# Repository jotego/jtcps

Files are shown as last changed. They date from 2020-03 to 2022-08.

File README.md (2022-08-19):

# JTCPS - FPGA Arcade Hardware

You can show your appreciation through
* Patreon: https://patreon.com/jotego
* Paypal: https://paypal.me/topapate

Capcom System 1/1.5/2 compatible verilog core for FPGA by Jose Tejada (jotego).

# Original Documentation

[The internet archive](www.archive.org) holds some schematics related to this work.

* [Forgotten Worlds manual](https://archive.org/details/arcademanual_forgotten-worlds/page/n15/mode/2up)

# Memory Requirements

All CPS1 and CPS1.5 operate correctly on a 32MB SDRAM system. Some CPS2 games may require a 64MB module. Those games are listed as having a GFX ROM of 16MB or more below. Please check the CPS2 ROM size section.

# Control

MiSTer allows for gamepad redifinition. However, the keyboard can be used with more or less the same layout as MAME for MiST(er) platforms. Some important keys:

-F12 OSD menu
-P   Pause. Press 1P during pause to toggle the credits on and off
-5,6 1P coin, 2P coin
-1,2 1P, 2P

For MiST, the first 6 gamepad buttons are used for game buttons, the next 2 buttons are used for credit and start buttons. If there is still one button left in the gamepad, it will be used for pause.

There is an option to slow down the game (available only for CPS2). If you enable the 1P_hold_for_slow setting on the OSD, then while the 1P button is held the game will run at half the speed. Release the 1P button to go back to normal speed or disable the option in the OSD. Note that if the option is enabled the 2P, 3P and 4P buttons will also activate the slow down effect.

# Setup

## MiSTer

Copy the RBF file to `_Arcade/cores` and the MRA files to `_Arcade`. Copy zipped MAME romsets to `_Arcade/mame`. Enjoy.

It is also possible to keep the MAME romsets in `_Arcade/mame` but have the MRA files in `_CPS` and the RBF files in `_CPS/cores`

The _rotate screen_ OSD option is ignored for horizontal games.

## MiST

You need to generate the .rom file using this (tool)[https://github.com/sebdel/mra-tools-c/tree/master/release]. Basically call it like this:

`mra ghouls.mra -z rompath -A`

And that will produce the .rom file and a .arc file. The .arc file can be used to start the core and directly load the game rom file. Note that the RBF name must be JTCPS1.RBF for it to work. The three files must be in the root folder.

*Important*: make sure to have the latest firmware and latest version of the mra tool.

Copy the RBF, .arc and .rom files to MiST and enjoy!

Note that there is no screen rotation in MiST. Vertical games require you to turn your screen around. You can however flip the image through the OSD.

Pang! 3 and all CPS 1.5/2 games did not use DIP switches to configure the game, but a small non-volatile RAM. You have to enter the test menu to configure it (via OSD). After you have configured the settings, save the contents using the OSD option *Save NVRAM*. A file will be created at the root of your SD card called game.RAM, where game will match the name of the .ROM file used with the game.

# Issues

Please report issues (here)[https://github.com/jotego/jtbin/issues].

## QSound Hiss

The DSP16A clock enable must be an exact multiple of 30MHz. Otherwise the sampling period will not be constant, generating jitter. The effect of jitter is very obvious in the DAC used on MiST because when all sound goes silent an ugly transient occurs. That effect was not noticeable in MiSTer, which uses a different DAC.

Even with the right clock enable, there is still hiss occasionally in MiST(er). Using the FPGA logic analyzer I could check that the period was indeed constant but hiss was present.

# CPS-1 Audio

The OKI PCM input clock is 1MHz, depending on the SS input setting, this gives two sampling frequencies:

SS | Fs (Hz) | 4xFs  |    a    |  1-a
---|---------|-------|---------|--------
0  | 6097.5  | 24390 | 0.8200  | 0.1800
1  | 7575.7  | 30303 | 0.8524  | 0.1476

The original board has a first-order low pass filter at 770 Hz, this can be implemented with a first order IIR filter:

y[k] = a * y[k-1] + (1-a) * x[k]

where a = exp(-wc/T )
wc = 2*pi*770 = 4838 rad/s
T  = 1/4Fs

# QSound

QSound requires its own firmware rom to work. In MAME this is called qsound.zip. QSound sampling frequency is 3746 ticks of the input clock, when the clock enable applied is 2/3. For a 90MHz input clock, this will result in the correct internal 30MHz and in a sampling frequency of 90MHz/3747=24,019.2Hz

The original board had a digitally controlled amplifier. The volume set on this amplifier could be read back by the CPU and DSP. In order to control the value read by these devices, press and hold the coin button for 1P while pressing up or down (for more or less volume). Note that this does not have an actual effect on the sound output.

# PAL Dumps
PAL dumps cam be obtained from MAME rom sets directly. Use the tool jedutil in order to extract the equations from them. The device is usually a gal16v8. For instance:

```
jedutil -view wl24b.1a gal16v8
```

In order to see the equations for Willow's PAL.

# Compilation
The core is compiled using jtcore from **JTFRAME**. Follow the instructions in the README file of (JTFRAME)[https://github.com/jotego/jtframe] and then:

```
source setprj.sh
jtcore cps1 -mister
```

This will produce the mister file.

## Static Time Analysis (STA)

MiST and SiDi compilations produce STA clean files with the default seed. However the MiSTer RBF file with everything enabled doesn't always come STA clean. If you disable HDMI or sound during compilation the RBF file will normally be STA clean. Public binary distribution in [jtbin](https://github.com/jotego/jtbin) are either STA clean or violations are below 99ps.

# MRA Format

Offset    | Length | Use
----------|--------|-------------
 0  /  0o |  2     | Sound CPU ROM*
 2  /  2o |  2     | PCM data*
 4  /  4o |  2     | GFX ROM*
 6  /  6o |  2     | QSound firmware*
10h / 20o | 18     | CPS-B configuration
22h / 42o |  1     | Game ID
23h / 43o |  2     | Bank offset
25h / 45o |  2     | Bank mask
27h / 47o |  1     | CPS-A board type (Pang! 3, etc.)
30h / 60o | 11     | Kabuki keys (CPS 1.5 only)
28h / 50o |  1     | CPS2 board type
2ch / 54o | 20     | CPS2 keys

* All offset values are expressed in kilobytes and stored with MSB byte second

The offset for each graphic bank is comprised of two bytes. Each offset data is packed in 4 bits, with the MSB used for bank 3:

{ Offset_bank3, ..bank2, bank1, bank0 } = { byte 24h, byte 23h }

The 4-bit offset makes the MSB of the 20-bit GFX ROM address.

CPS-A board type format:

Bits   |  Use
-------|----------------------------
0      | CPU speed. 0=10MHz, 1=12MHz
3:1    | Enables additional inputs on CPS-B chip side
4      | High for charger games
5      | 0 = Disables Kabuki decryption

CPS2 board type format:

Bits   |  Use
-------|-------
1:0    | Controller type

# SDRAM Usage

## CPS 1/CPS 1.5

SDRAM bank | Usage
-----------|-------
0          | RAM/VRAM/M68000 ROM
1          | Sound CPU/PCM samples
2          | GFX
3          | GFX

## CPS 1.5 ROM Size

The SDRAM layout is the same as for CPS 1. Although samples are much larger than in CPS 1 titles, they still fit in one SDRAM bank sharing space with the Z80 ROM.

Game                  | CPU     |   Z80       | GFX     | Q-Sound |
----------------------|---------|-------------|---------|---------|
Warriors of Fate      | 1   MB  |  128 kB     | 4 MB    | 2 MB    |
Cadillacs & Dinosaurs | 1.5 MB  |  128 kB     | 4 MB    | 2 MB    |
The Punisher          | 1.5 MB  |  128 kB     | 4 MB    | 2 MB    |
S.N. Slam Masters     | 2.0 MB  |  128 kB     | 6 MB    | 4 MB    |
Muscle Bomber Duo     | 2.0 MB  |  128 kB     | 6 MB    | 4 MB    |

## CPS 2 ROM Size

It looks like the 16kB memory add-on is not used for regular games. Maybe it is used for
network connectivity only.

Game                  | CPU     |   Z80       | GFX     | Q-Sound |Obj base| Addon | Popularity
----------------------|---------|-------------|---------|---------|--------|-------|------------
19XX                  | 2.5 MB  |  128 kB     | 10 MB   | 4 MB    | 7080   |  No   | 191
1944                  | 1.5 MB  |  128 kB     | 20 MB   | 8 MB    | 7080   |  No   | 161
Alien vs Predator     | 2.0 MB  |  128 kB     | 16 MB   | 4 MB    | 7000   |  No   | 637
Armored Warriors      | 4.0 MB  |  256 kB     | 20 MB   | 4 MB    | 7000   |  No   | 278
Battle Circuit        | 3.5 MB  |  256 kB     | 16 MB   | 4 MB    | 7080   |  No   |  87
Capcom Sports Club    | 2.5 MB  |  128 kB     |  8 MB   | 4 MB    | 7080   |  No   |  20
Cyberbots             | 4.0 MB  |  256 kB     | 32 MB   | 4 MB    | 7080   |  No   | 141
Darkstalkers          | 4.0 MB  |  256 kB     | 20 MB   | 4 MB    | 7080   |       | 146
Dimahoo               | 2.0 MB  |  256 kB     | 16 MB   | 8 MB    | 7080   |  No   |  32
DnD Shadow o. Mystara | 4.0 MB  |  256 kB     | 24 MB   | 4 MB    | 7080   |  No   | 336
DnD Tower of Doom     | 2.5 MB  |  128 kB     | 12 MB   | 4 MB    | 7080   |  No   | 108
Eco Fighters          | 2.0 MB  |  128 kB     | 12 MB   | 4 MB    | 7000   |       |  64
Giga Wing             | 1.5 MB  |  128 kB     | 16 MB   | 8 MB    | 7080   |       |  66
Hyper SF II           | 4.0 MB  |  256 kB     | 32 MB   | 8 MB    | 7080   |       | 171
Janpai                | 1.0 MB  |  128 kB     | 16 MB   | 4 MB    | 7000   |       |  15
Jyangokushi           | 0.5 MB  |  128 kB     | 16 MB   | 4 MB    |        |       |   1
Mars Matrix           | 1.5 MB  |  128 kB     | 32 MB   | 8 MB    |        |  No   |  57
Marvel Super Heroes   | 4.0 MB  |  256 kB     | 32 MB   | 4 MB    |        |       | 165
Marvel vs SF          | 4.0 MB  |  256 kB     | 32 MB   | 8 MB    |        |       | 336
Marvel vs CAPCOM      | 4.0 MB  |  256 kB     | 32 MB   | 8 MB    |        |       | 377
Megaman 2             | 1.5 MB  |  256 kB     |  8 MB   | 4 MB    |        |       | 225
Darkstalker's revenge | 4.0 MB  |  256 kB     | 32 MB   | 4 MB    |        |       |  54
Progear               | 1.0 MB  |  128 kB     | 16 MB   | 8 MB    | 7080   |  No   |  72
Puzz Loop 2           | 2.0 MB  |  128 kB     | 16 MB   | 4 MB    | 7000   |       |  16
Quiz Nanairo Dreams   | 2.0 MB  |  128 kB     |  8 MB   | 4 MB    |        |       |   8
Ring of Destruction   | 3.0 MB  |  256 kB     | 18 MB   | 4 MB    |        |       | 293
Slam Masters 2        | 3.0 MB  |  256 kB     | 18 MB   | 4 MB    |        |       | 291
SF alpha 1            | 2.0 MB  |  256 kB     |  8 MB   | 4 MB    | 7000   |       | 190
SF alpha 2            | 3.0 MB  |  256 kB     | 20 MB   | 4 MB    | 7000   |       | 218
SF alpha 3            | 4.0 MB  |  256 kB     | 32 MB   | 8 MB    | 7000   |       | 456
SF zero 2 alpha       | 3.0 MB  |  256 kB     | 20 MB   | 4 MB    | 7000   |       | 293
Super Gem Fighter     | 2.5 MB  |  256 kB     | 20 MB   | 8 MB    |        |       | 252
Super Puzzle Fighter 2| 1.0 MB  |  256 kB     |  4 MB   | 4 MB    | 7000   |       | 210
SF2 New Challengers   | 2.5 MB  |  128 kB     | 12 MB   | 4 MB    | 7080   |  No   | 135
SF2 Turbo             | 3.5 MB  |  256 kB     | 16 MB   | 4 MB    | 7080   |       |1200
Vampire Savior 1      | 4.0 MB  |  256 kB     | 32 MB   | 8 MB    |        |       |  30
Vampire Savior 2      | 4.0 MB  |  256 kB     | 32 MB   | 8 MB    |        |       |  26
X-Men Children of A.  | 4.0 MB  |  256 kB     | 32 MB   | 4 MB    | 7080   |  No   | 179
X-Men vs SF           | 3.5 MB  |  256 kB     | 32 MB   | 4 MB    | 7080   |  No   | 337

# Simulation

## Game
1. Generate a rom file using the MRA tool
2. Update the symbolic link rom.bin in ver/game to point to it
3. If all goes well, `go.sh` should update the sdram.hex file
   But if sdram.hex is a symbolic link to something else it might
   fail. You can delete sdram.hex first so it gets recreated

   `go.sh` will fill up sdram.hex with zeros in order to avoid x's in
   simulation.

4. Apply patches if appropiate. The script `apply_patches.sh` can generate
   some alternative hex files which skip some of the test code of the game
   so it boots up more quickly

5. While simulation is running, it is possible to update the output video
   files by running `raw2jpg.sh`

Some Verilog macros:

1. FORCE_GRAY ignore palette and use a 4-bit gray scale for everything
2. REPORT_DELAY will print the average CPU delay at the end of each frame
   in system ticks (number of 48MHz clocks)
3. JTCPS_TURBO forces turbo mode, speeding up -slightly- the game speed, especially on boot-up

## Video

Video only simulations can be done using mame dumps. Use the tool *cfg2mame* in the *ver/video* folder
to create two *.mame* files that can invoked from mame to dump the simulation data. Run the game in debug
mode but source from MAME the register file that *cfg2mame* creates. Then at the point of interest souce *vram.mame*. That creates the file vram.bin. Copy that file to a directory with the mame name of the game. Add a numerical index (see the other folders for examples). Create a hex file following the examples in
the other files too. Now you run go.sh like this:

```
go.sh -g game -s number -frame 2
```

This will run the simulation for the folder *game* and looking for files with the *number* index. If you
 need to look at the sprites too, you need to run more than one frame as the object DMA needs a frame to
 fill in the data.

# Support

You can show your appreciation through
* Patreon: https://patreon.com/jotego
* Paypal: https://paypal.me/topapate

# Licensing

Contact the author for special licensing needs. Otherwise follow the GPLv3 license attached.

# Patron Acknowledgement

The following patrons supported the development of CPS1.5
```
3style              Chris Harvey        Joeri van Dooren    Oliver Wndmth
80's spaceman       cohge               Johan Smolinski     Oriez
Adam Davis          Coldheat007         John Casey          Oscar Laguna Garcia
Alan Shurvinton     Dakken              Jonathan Loor       Oskar Sigvardsson
Alfredo Henriquez   Dan                 Jonathan Tuttle     Patrick Roman Fabri
Alonso J. Núñez     Daniel Bauza        Jorge Slowfret      Paweł Mandes
Anders Rensberg     Daniel Estreito     Josiah Wilson       Per Sweden
Andrea Chiavazza    dannahan            JPS (RetroFPGA)     Phillip McMahon
Andreas Micklei     Darren Wootton      Juan E. Gayon       PsyFX
Andrew Ajello       Dasutin             Justin D'Arcangelo  Purple Tinker
Andrew Boudreau     David Ashby         Kitsuake            Rachael Netz
Andrew Francomb     David Fleetwood     KnC                 RandomRetro
Andrew Moore        David Jones         Kyle Good           RetroDriven
Andy Palmer         David Mills         Lee Osborne         Richard Eng
Andyways            derFunkenstein      Leslie Law          Richard Murillo
angel_killah        DJ Lethal           Lionel LENOBLE      Richard Simpson
Angelo Kanaris      Don Gafford         Louis Martinez      Robert Bergman
Anthony Monaco      DrMnike             Luc JOLY            Robert Forbes
Anton Gale          Ed Balan            Magnus Kvevlander   Robert MacLean
Antonio Villena     Edward Rana         Manuel Astudillo    Robert Mullings
Aquijacks           Eric J Faulkes      Marcus Hogue        Roman Buser
Arcade Express      Filip Kindt         Martin Di Palma     rsn8887
Arjan de Lang       Francis B           Matt Evans          Ryan Fig
asdfgasfhsn         Frank Hoedemakers   Matt ODonnell       Sassbasket Silvercloud
atrac17             Frédéric Mahé       Matthew Humphrey    Sebastien Goutal
Bear S              Gary Greenan        Matthew Woodford    Skeeter
Ben Toman           Gavin               Matthew Young       Sofia Rose
Bender              Greg                Max Schütz          Spank Minister
Bliz 452            Gregory Val         Michael Deshaies    Spencer Bradley
Bob Gallardo        Gus Douboulidis     Michael Yount       Stephen Goldberg
Brent Fraser        Handheld Obsession  Mick Stone          Steven Wilson
Brett T Davis       Hard Rich           Mike Jegenjan       Steven Yedwab
brian burney        Henrik Nordström    Mike Parks          Thomas Irwin
Brian Sallee        HFSPlay             MiSTerFPGA.co.uk    Toby Boreham
Carrboroman         hyp36rmax           mottzilla .         Travis Brown
Charles             Jacob Hoffman       Nailbomb            Trifle
Chi Wai Tran        Jeff Roberts        natalie             Ulf Skutnabba
Chris Jardine       Jeremy Hasse        Neil St Clair       Ultrarobotninja
Chris smith         Jeremy Kelaher      Nico Stamp          Victor Bly
Chris W Miller      Jesse Clark         nonamebear          Victor Fontanez
Christian           Jim Knowler         nullobject          Víctor Gomariz Ladrón de Guevara
Christian Bailey    Jo Tomiyori         Oliver Jaksch       Xzarian
Christopher Gelatt                                          yoaarond
```
The following patrons supported the development of CPS2
```
                     80's spaceman        Adam Small           Adam Zorzin
Adam is              Adan Jacquez         Adrian Labastida     Adrian Nabarro
Alan Shurvinton      Alexander Lash       Alexander Upton      Alfonso Clemente
Alonso J.            Alvaro Paniagua      Andrea Chiavazza     Andreas Micklei
Andrew Boudreau      Andrew Schmidt       Angelo Kanaris       Anthony Monaco
Anton Gale           Antwon               Aquijacks (Flashjacks Aqy
Arend Pronk          Arthur Blough        Arthur Fung          BRCDEvg
Banane               Bear S               Ben Toman            Bitmap Bureau
Bitmaps Retro        Bliz 452             Brandon Peach        Brandon Smith
Brandon Thomas       Brent Fraser         Brian Peek           Brian Plummer
Bruno Freitas        Bruno M              C                    Cameron Tinker
Carrboroman          Cesar Sandoval       Charles              Chris Chung
Chris Mzhickteno     Chris Tuckwell       Chris W              Chris smith
Christian Bailey     Clinton Cronin       Cobra Clips          Coldheat007
Colin Colehour       Colt83               DARK WEB             Dan Doyle
Daniel               Daniel Casadevall    Daniel Fowler        Daniel Page
Daniel Zetterman     Darren Wootton       Dasutin              David Drury
David Filskov        David Fleetwood      David Jones          Denis Brækhus
Diana Carolina       Dimitris Zongas      DrMnike              Dre137
Eric J               Eric Schlappi        Eric Walklet         Five Year
Flavio Real          Florian Raoult       Focux                Gluthecat
GohanX               Gonzalo Lopez        Goolio               Greg
Gregory Val          HFSPlay              Handheld Obsession   Henry
Ibrahim              ItsBobDudes          JOSE LUIS            JR
Jack Sammons         Jacob Hoffman        Jacob Lawter         James B
James Dingo          James Kilgore        Javier Rodas         Jeff Roberts
Jeremy Hasse         Jerry Suggs          Jesse Clark          Jesus Rodriguez
Jim Knowler          Jockel               Johan Smolinski      John Figueroa
John Fletcher        John Hood            John Silva           John Wilson
Jonah Phillips       Jonathan Brochu      Jonathan Loor        Jonathan Tuttle
Jootec from          Jorge                Jork Sonkinfield     Joseph Milazzo
Josh Emery           Josh Mayer           Josiah Wilson        Justin D'Arcangelo
Kai Cherry           Keith Gordon         Kem Yos              Ken Scott
Kendrick Hughes      Kevin Gudgeirsson    KnC                  KrzysFR
L.Rapter             LFT                  Laurent Cooper       Lee Grocott
Lee Osborne          Luc JOLY             Mack H               Magnus Kvevlander
Manuel Astudillo     Marco Emparan        Mark Baffa           Mark Davidson
Mark R               MarthSR              Martin Ansin         Matheus
Matsu                Matt Elder           Matt Evans           Matt Lichtenberg
Matt McCarthy        Matt ODonnell        Matthew Humphrey     Matthew Woodford
MechaGG              Megan Alnico         MiSTerFPGA.co.uk     Michael Berger
Michael C            Michael Deshaies     Michael Rea          Mick Stone
Mike Jegenjan        Mike Olson           Mike Parks           Mottzilla
NINE                 Nailbomb             Narugawa             Neil St
NerdyNester          Nick Delia           Nick G               Nico Stamp
Nicolas Hurtado      NonstopXiaowei       OopsAllBerrys        Oriez
Oskar Sigvardsson    Parker Blackman      Patrick Roman        Paul Cunningham
Paul M               Paulo M.             Paweł Mandes         PeFClic
Per Ole              Philip Lai           Philip Lawson        Piafoman
Pierre-Emmanuel Martin Pontus Nyholm        Rachael Netz         Rachel Schaeffer
RandomRetro          Raph_friend          Raphael Melgar       RayGun
Richard Eng          Richard Murillo      Richard Simpson      Rick Ochoa
Ronald Dean          Roro                 Ryan                 Ryan Fig
Ryan O'Malley        Sam Hall             Samuel Warner        Schnookums
Sofia Rose           Spank Minister       SteelRush            Stefan Krueger
Stephen R            Steve Ikeguchi       Steve Skrzyniarz     Steven Hansen
Steven Yedwab        Stuart Morton        SuperBabyHix         Taehyun Kim
Tales Dilli          TealShark            Terse                The Collector
The Video            Thomas Attanasio     Thomas Capetanakis   Thomas Irwin
Tobias Dossin        Travis Brown         Trifle               Turboman UK
Ty B                 VickiViperZabel      Victor Bly           Victor Fontanez
Will Abbott          William Clemens      Yunus Soğukkanlı     Zach Marquette
Zoltan Kovacs        albertprime          alejandro carlos     angel_killah
arcadebros           blackwine            brian burney         bruno_tapez
cbab                 chauviere benjamin   dannahan             datajerk
deathwombat          derFunkenstein       gunmakuma            joshewah777
kccheng              kernelchagi          liphy                natalie
nonamebear           retrod00d            rsn8887              scapeghost
slayer213            taal.M               tonitellezb          troy coberly
yoaarond             종규 박
```

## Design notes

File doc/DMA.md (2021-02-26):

# DMA

## Measurements

DMA events occur once per line. All events except the palette DMA will finish before the line finishes.

Once VB starts DMA events are stopped until
1. A palette or OBJ request occurs
2. We need to prepare the SCR buffers before VB ends

VB lasts for 38 lines.

### Palette DMA

It spreads over many lines. Lasts for 780.4us, it is of a fixed duration, regardless of which palettes are updated. It can start outside VB, particularly during system bootup sequence.

Palette DMA stops for OBJ processing at the regular pace. It probably stops also for tile processing but that cannot be seen VB because tile proc. is stopped for most of the VB period.

### OBJ DMA

I measured the line DMA header and found these values: 604ns, 1.64us, 2.06us

ROW SCR | OBJ  | Time (us)
--------|------|----------
  OFF   | OFF  | 0.60
  OFF   |  ON  | 1.64
  ON    | OFF  | Not measured
  ON    |  ON  | 2.06

The first one would correspond to a line update with no OBJ and no row scroll. The second, no row scroll, but OBJ is active. The third, full row scroll and OBJ. It seems that there is a minimum of ~600ns (maybe 9x 16MHz cycles plus some bus arbitrion at the CPU 10MHz) required by the original DMA controller even if no requests are in place.

On each line a whole sprite data is copied: 4 16-bit transfers.

OBJ DMA can be re-started in the middle of the frame.

### Tiles DMA

Tile data for each scroll layer is stored in a buffer. SCR2 buffer is larger because it supports row scrolling.

Layer | Transfers | Time (us, 4MHz clock) | Equivalent tile pixels
------|-----------|-----------------------|------------------------
SCR1  |  98       | 24.5                  | 392
SCR2  |  96       | 24                    | 768
SCR3  |  24       | 6                     | 384

The layers are read in this order: SCR1, SCR2 and finally SCR3. Each layer is read only when it is needed based on the current screen position and the vertical scroll value.

### Loop test

A counter runs during the frame and gets reset at VB. By switching different control registers the following information can be extracted:

-Palette is only copied if the base register is written to. The DMA duration is the same regardless of the palette mask setting
-Scroll 2, 3 and row scroll. The video control register disables DMA for this layer
-Video control register is $4C ($11 in jtcps1_mmr.v = ppu_ctrl)
    -ROW  bit 0
    -SCR2 bit 4
    -SCR3 bit 2

Row scroll
19a9 7,6,3,2
198D 4,5,1,0

Scroll 3
19a8 7,6,3,2
198d 4,5,1,0

Scroll 2
1a31 7,6,3,2
198e 4,5,1,0

Fastest setting
1a67
Slowest setting
1833

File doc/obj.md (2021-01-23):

# Buffer Architecture

## CPS1

### Original Design

There is a frame buffer only for objects. Data is read from it at the pixel rate,
while data for the next frame is written in any location.

1. At VBLANK: CPU triggers the DMA and starts writing on a new VRAM page
2. During HBLANK, a few table entries are read
3. Sprites from read entries are rendered in the frame buffer

### JTCPS1

There is no frame buffer but only a line buffer.

1. At VBLANK: CPU triggers the DMA and starts writing on a new VRAM page
2. During HBLANK, a few table entries are copied to an internal table in BRAM
3. The internal table is read and a selection of sprites that will be visible
   is copied to a second table (double buffered)
4. The second table is used to render sprites in the line buffer

The advantage of this architecture is that it uses less memory. However, the
maximum number of sprites that can be drawn is less than what was allegedly
possible in the original hardware.

## CPS2

### Original design

There is no DMA involved. There is an 8kBx2 page buffer. While the CPU writes to one
of them, the engine renders the contents of the other one. The CPU flags which half
is being accessed with a latch.

A frame buffer is also used in CPS2.

### JTCPS2

Memory bits available without OBJ logic: 249'117 (MiST) => 27 9MK blocks free

The SDRAM does not limit the number of elements:
    -SDRAM limit: 96MHz / 8 * 4 bytes = 48 MByte
    -GFX data 4bpp, 16 pixels => 1 pixel = 8 bytes
    -SDRAM limit in pixels = 48Mbyte/8 = 6MByte => >12k horizontal lines

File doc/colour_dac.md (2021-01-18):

# The R089B

This is a resistor array, described by Loïc in his CPS2 work. Pins are as follows:

pin 1 is common, all resistors connect to this pin. From pins 2 to 7, each resistor is roughly twice the value of the previous one, starting at 100 Ohm: 100, 220, 470, 1k, 2.2k and 4.7k.

-Colour signals connect to 2.2k, 1k, 470 and 220 Ohm
-Bright signals connect to 1k, 470, 220 and 100 Ohm

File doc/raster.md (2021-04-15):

Games using raster interrupts, at least during the attract mode or first level.

Game     | Used | 0E  | 10  | 12   | Remarks
---------|------|-----|-----|------|--------
19xx     | No   |     |     |      |
armwar   | No   |     |     |      |
batcir   | No   |     |     |      |
sfa      | No   |     |     |      |
ssf2     | Yes  |     |     |      | SCR2/ROWSCR values changed midframe
megaman 2| No   |     |     |      |
csclub   | No   |     |     |      |
spf2t    | No   |     |     |      |
mpang    | No   |     |     |      |
avsp     | No   |     |     |      |
qndream  | Yes  | 200 | 106 | 106  |
mmatrix  | Yes  |  FF |  FF | 106  |
msh      | Yes  |0/200| many| 106  |

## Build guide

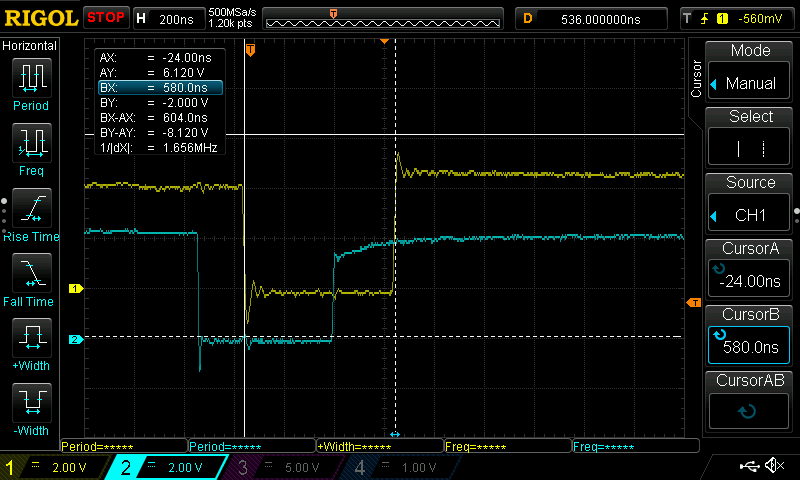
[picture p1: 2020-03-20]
doc/measurements/DS1Z_QuickPrint1.png

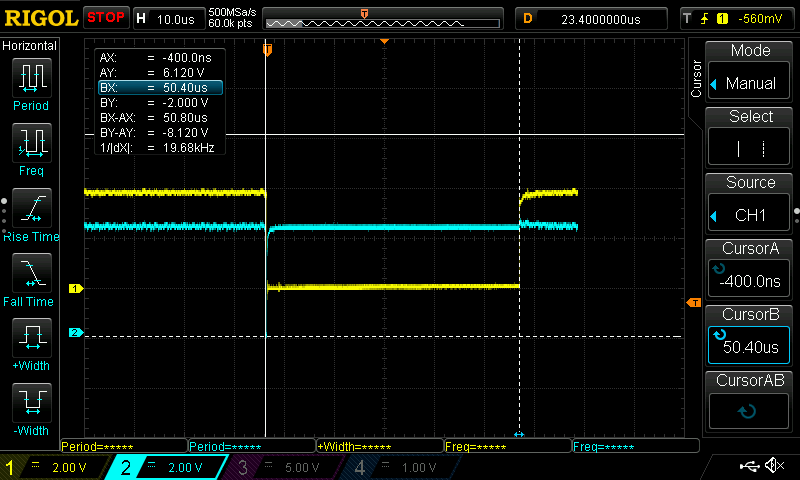
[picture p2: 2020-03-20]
doc/measurements/DS1Z_QuickPrint6.png

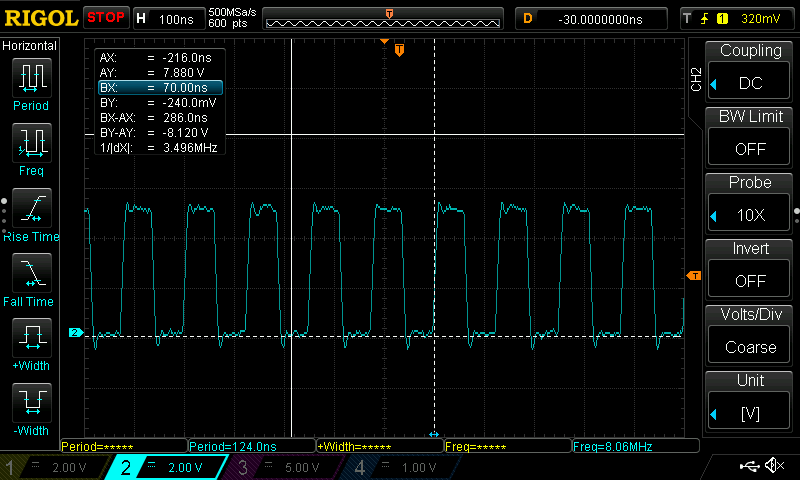
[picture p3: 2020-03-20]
doc/measurements/DS1Z_QuickPrint16.png

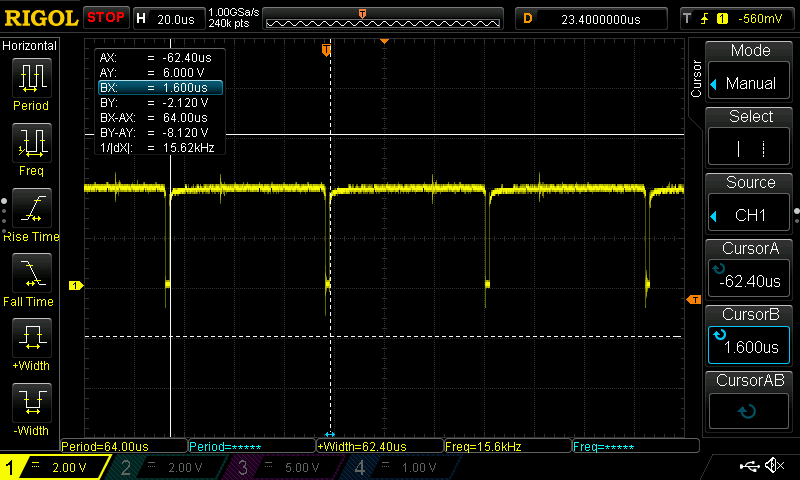
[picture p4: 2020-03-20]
doc/measurements/DS1Z_QuickPrint9.png

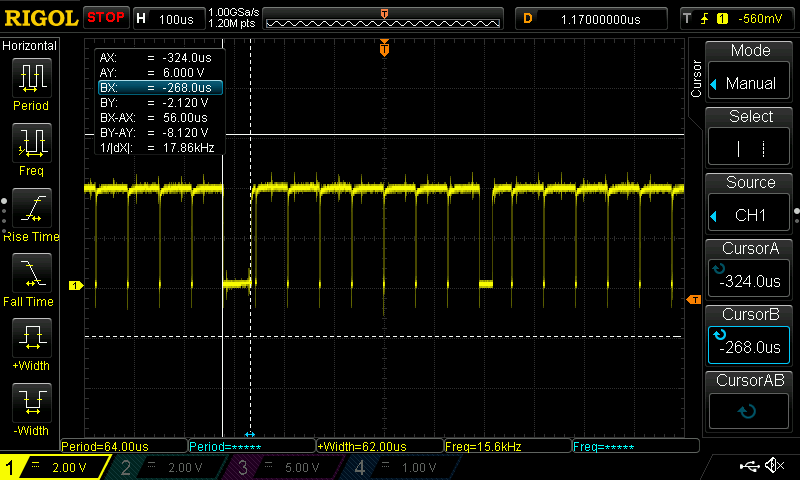
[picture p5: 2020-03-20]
doc/measurements/DS1Z_QuickPrint12.png

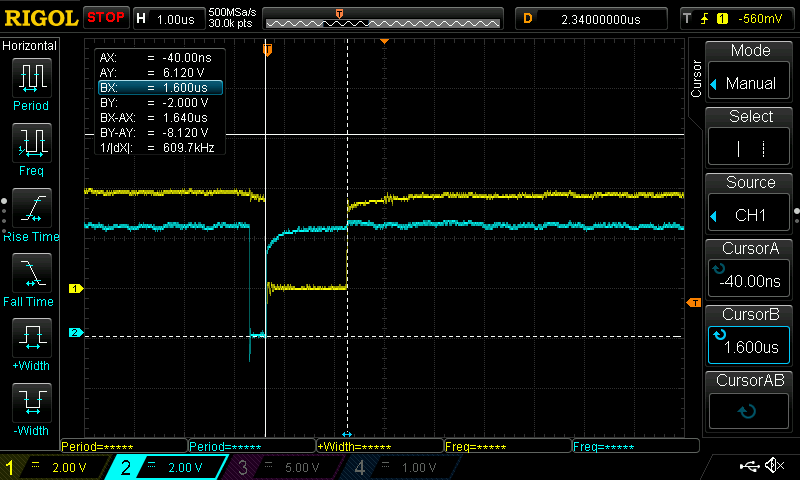
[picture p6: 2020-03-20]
doc/measurements/DS1Z_QuickPrint5.png

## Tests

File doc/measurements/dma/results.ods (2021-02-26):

core | OBJ short |  | OBJ long |  | No OBJ |  | Turbo 12MHz |  | Turbo 10MHz
210124 | 1399 | 139a | 13e4 | 13e8 | 14ad | 14ae | 1d5e | 1d5f
200130 | 14ae | 14af | 14ae | 14af | 14ae | 14af | 1d5e | 1d5f | 1852
PCB | 1894 | 1895 | 1894 | 1895 | 1894 | 1895 | 1894 | 1895 | 1895
MAME |  |  |  |  |  |  |  | 2382
210220 | 1890 | 1890 | 1890 | 1890 | 1890 | 1890 |  |  | 1ce2
COMPARISON
210124 | 5017 | 5018 | 5092 | 5096 | 5293 | 5294 | 7518 | 7519
 |  | -20,3% | -19,1% | -19,0% | -15,9% | -15,9% | 19,5% | 19,5%
200130 | 5294 | 5295 | 5294 | 5295 | 5294 | 5295 | 7518 | 7519 | 6226
210220 | 6288 | 6288 | 6288 | 6288 | 6288 | 6288 |  |  | 7394
 |  | -0,08% | -0,06% | -0,08% | -0,06% | -0,08% |  |  | 17,5%
PCB | 6292 | 6293 | 6292 | 6293 | 6292 | 6293 | 6292 | 6293 | 6293
Delta |  | -15,9% | -15,9% | -15,9% | -15,9% | -15,9% | 19,5% | 19,5% | -1,1%
MAME |  |  |  |  |  |  |  | 9090
 |  |  |  |  |  |  |  | 0,444462100746862

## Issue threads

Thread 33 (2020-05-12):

CPS1 core - Street Fighter 2 Turbo Hyper Fighting: The speed differential: The issue

fluxcorenz, 2020-05-12:
I've been trying to get good timing measurements to ensure the CPS1 core is as accurate timing-wise as possible, and Street Fighter 2 Hyper Fighting has been a thorn in the side of emulation for about 20 years now.

Video comparing 20200501 mister CPS1 core vs arcade board:
https://www.youtube.com/watch?v=7f4TsJQQSB0

From the sync time (0m21s) to the start of the 'continue' countdown screen:
Arcade board: 250s
Mister: 267s

Making a speed differential of roughly 6.8%

ROM revision is same: 921209 ETC

DIP settings (shown at end of video) are not exactly identical (I couldn't set the Mister dips the same), but I did a later test with arcade dips matching the Mister settings and the speed difference between the two arcade captures was around 14frames over the ~1500 frames of test time - probably within the general variation of timing of the arcade board, if I were to make more captures.

The same test on the earlier 20200410 rbf (against the same arcade footage) showed slightly faster mister speeds (i.e. the core has slowed down between 20200410 and 20200501)
https://www.youtube.com/watch?v=A4euNTIXxXw
From the sync time (0m19s) to the start of the 'continue' countdown screen (different from the above due to the sync point):
Arcade board: 252s
Mister: 266s

Roughly 5.5% slower

Furthermore, enabling the 'turbo' mode in the 20200501 mister cps1 core almost matches the arcade board speed (mister being faster by 15 frames or so):
https://www.youtube.com/watch?v=gs-IZaOrSlc

I'm working on getting footage from other people's arcade boards to gain confidence in general, to prove my arcade board isn't anomalous.

Critiques on testing methodology etc welcome

jotego, 2020-08-07:
I was thinking today that maybe the difference could come from different frame rates. So I verified a couple of things. The conclusion is that the frame rate does not seem to be a factor.

Schematics show that the crystal oscillator is different for the CPU and the GPU (CPS-A chip). The CPU uses a 10MHz crystal in most CPS1 games and allegedly a 12MHz one in some titles. The CPS-A chip uses a 16MHz crystal. The frame rate is set by the CPS-A chip so there is no reason to think that the frame rate would be different.

The frame rate on my SF2WW board -measured through DMA periods- is 59.78Hz. The JTCPS1 core outputs 59.63Hz. The difference is 0.25% and falls within the error tolerance of the equipment used.

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

jotego, 2020-12-16:
I have fixed a problem recently in the CPU that should bring back some of the speed. However, the main point is probably the DMA timing. I haven't uploaded the new RBF as it may be troublesome to 128MB module owners.

fluxcorenz, 2020-12-16:
I agree with the earlier point about frame rates - all the CPS1 Street Fighter boards run at the same graphics frame rate - SF2 Turbo uses techniques to run faster internally (https://game.capcom.com/cfn/sfv/column/131667) but still outputs at ~60Hz

I'm happy to give the rewritten memory controller version a test if you supply the RBF - I do use a 128MB module but will keep that in mind regarding any issues that might pop up.

jotego, 2021-01-30:
One year later... I have news.

During this time I have verified that the dash boards only have a faster clock. There are no other differences.

Grego2D and I designed a test software to run on real hardware and measure the time. Without going into much detail, the results can be summarized in:

MAME 9090
JTCPS1 Turbo 7519
REAL PCB 6293
JTCPS1 No turbo 5090

So the core is +20% faster with turbo, and 20% slower with no turbo. I did a first improvement to the DMA, and got it from 20% to 15%. I will be closing the rest of the gap in the coming days.

jotego, 2021-01-31:
I have improved the bus wait logic. The time difference is now 0.08%. RBF already available in jtbin.

fluxcorenz, 2021-01-31:
https://www.youtube.com/watch?v=2nJiMnxXYVA

Original time loss over all the idle rounds was 24 in-game seconds, now down to 3.
Total frame loss is 97 frames over 14999, ~0.65% slower than arcade.

Pretty huge improvement!

jotego, 2021-02-01:
It's a great comparison. Thank you so much for re-doing it.

Some of the error will be due to the difference between the  PCB aged oscillator and the crispy shiny 8MHz sharp oscillator in MiSTer.

We are going to take that factor out in a future test.

alessioscand, 2021-02-01:
Hello,
are these improvements valid also for SIDI?
Thanks

jotego, 2021-02-01:
Of course, the updated core is in the jtbin repository.

jotego, 2021-03-09:
Speed matched.

Closed 2021-03-09.

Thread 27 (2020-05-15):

CPS1: DB15 no working on last MiSTer RC 20200515

yavimaya, 2020-05-15:
DB15 SNAC is no working on last CPS1 core version, only D button from neogeo controller does something.
It was full working on v20200502.

jotego, 2021-02-20:
Is DB15 SNAC the same as the NeoGeo gamepad on DB9 for Villena's boards?

jotego, 2021-05-26:
Duplicated: https://github.com/jotego/jtbin/issues/93

Closed 2021-05-26.

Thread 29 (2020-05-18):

CPS1 - Forgotten Worlds - wrong files in sets

eubrunosilva, 2020-05-18:
forgottnua - Forgotten Worlds -USA, B-Board 88618B-2, Rev. A-
lw_2.2b <= this file doesnt exist in this set
i think also other sets of forgotten worlds have this file so nonmerged sets will not work

jotego, 2020-09-10:
Thanks Bruno. I will accept PR for these issues.

Closed 2020-09-10.

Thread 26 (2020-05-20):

CPS1: Carrier Airwing questioned about speed

jotego, 2020-05-20:
From Carrboroman:

>  I'm not sure if it is an issue with US NAvy, but I see the background to stutter at the beginning of the stages (i.e. first stage, the clouds, pretty evident)...then when the game starts it's smooth....(I'm using 15Khx CRT, via VGA board, latest Mister)
> Quick update, I tried Carrier Airwing (world) and it shows the same behaviour. basically it's like slowing down when the stage begins (and sporadically while playing) it is particularly visible at the first stage, right before the first enemies arrives, the clouds are stuttering. Enabling turbo in the settings get rid of the issue...just don't know if the overall speed is increased (music feels a bit faster indeed)  I asked a friend who owns a Carrier Airwing PCB to make a video, but it may take few days (he's in Italy)
>(just to be sure, the clouds stuttering I refer to, is not during the plane take-off animation from the carrier, but right at the beginning of the first stage!)

jotego, 2021-01-31:
Same as #33

Closed 2021-01-31.

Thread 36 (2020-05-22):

Complete mame key mapping (kick harness)

funkycochise, 2020-05-22:
By now only the first 3 buttons for player 1 and 2 are mapped
P1 : B1 (Left Ctrl), B2 (Left Alt), B3   Space
P2 : B1 (A), B2 (S), B3 (Q)

Additional keys needed for kick harness are not recognized
P1 : B4 (Left Shift), B5 (Z) , B6 (X)
P2 : B4 (W) , B5 (I) , B6 (K)

jotego, 2021-02-02:
Sorry for the long wait.

MAME default keys are supported now:

6 buttons for 1P
5 buttons for 2P
3 buttons for 3P

The service key (9) and test key (F2) have been added too.

This will come automatically in future updates.

prrole, 2021-02-02:
Player 2 button 6 would make a lot of sense to add as K, even if it's not default in MAME - it is the de-facto standard.

Reference:

I-PAC, see, see I-PAC installation tab:
https://www.ultimarc.com/control-interfaces/i-pacs/i-pac2/

J-PAC, see J-PAC Installation tab:
ultimarc.com/control-interfaces/j-pac-en/j-pac-jamma-interface

JammaSD
arcadexpress.com/documentos/JammASD.pdf

JVS-PAC:
jvspac.kirurg.org/?page=operation

JVS-PAC 2:
irkenlabs.com/jvs-pac2/keyboard-operation

el-goe, 2021-02-02:
It would be nice to also be able to remap them on joysticks.

jotego, 2021-02-03:
I have added K (to the source code, not RBF files yet). I think it won't be a problem to share it between 3P and 2P because I don't know of 6-button games for three joysticks.

I cannot really add local mapping in the core without much havoc at all levels (user, developer and MiSTer framework). The current approach is this one:

1. MiSTer provides PS2 keyboard and gamepad inputs to the core
2. MiSTer can map keypresses to gamepad inputs transparently to the core
3. The core can map keypresses to gamepad inputs too

Note that 2 and 3 can potentially collide. An option to disable 3 may be advisable, but I don't want to pollute the OSD with more options and so far no one has complained about a clash of key mappings. Maybe they will now that F2 is assigned to the test key.

F2 as a test key is useful in the CPS1.5 and CPS2 cores and had been requested.

Closed 2021-02-02.

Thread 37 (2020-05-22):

CPS1 Investigate MRA support for rare Capcom test build 'The World Warrior & Champion Edition'

mholzinger, 2020-05-22:
To investigate - Support for for rare Capcom test build 'The World Warrior & Champion Edition'

Source: Arcade projects user posts a new Street Fighter arcade build has been uncovered.

Post to the project and the forum are here: https://www.arcade-projects.com/forums/index.php?thread/12828-rare-game-the-world-warrior-champion-edition/

```Street Fighter II - The World Warrior &Champion Edition

Street Fighter 2 910522 - Etc. build

A-board 89626A-4 DASH
B-board 91634B-2
C-board PPU B-11
```

- According to the forum post, this build may only work patched in ram and was a test build by capcom.

- Dump of files attached to this issue post.
[sf2-05222020.zip](https://github.com/jotego/jtbin/files/4670644/sf2-05222020.zip)

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

- Also to note from Post- This may appear on a cloned Pang 3 board.

jotego, 2020-09-10:
Thank you. I have added it to jtbin. Please make PR there if you have files or changes to add.

cracklejoy, 2020-09-25:
On first glance this appears to be one of yumeji's boss hacks and there are several in hbmame.  I have not checked byte for byte but I highly doubt that this is a test build without further information. I just finished a playthrough. That url leads nowhere.

Closed 2020-09-10.

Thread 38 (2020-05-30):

Star field in Strider

ArtemioUrbina, 2020-05-30:
The star field doesn't twinkle in MiSTer and some stars are rendered as lines.

Video comparing both: https://www.youtube.com/watch?v=p-YIV0Z6YGY

Thanks for the great work!

jotego, 2020-06-08:
Thank you so much for the video.
I don't have the exact algorithm for the stars. Nobody does as of today. But I would have expected them to twinkle in the same way. That's something I want to look at.

ArtemioUrbina, 2020-06-08:
Let me know if you want a direct capture, I can use an OSSC/XRGB/XPC-4 + X-Capture 1

wnka, 2021-02-11:
Issue impacts Forgotten Worlds star fields too

jotego, 2021-02-11:
It does, yes. I was expecting the CPS-B chip decapping to show the logic for this but the circuits unveiled do not seem to be the full story. Part of it is in the other CPS-A chip, which is not known yet.
I will check again the CPS-B schematics and see if I can apply something here.

jotego, 2021-09-29:
The stars are now documented thanks to Loïc Petit. There are a couple of text files [here](https://gitlab.com/loic.petit/cps2-reverse/-/blob/master/DLs/DL-0311/doc/stars.md) and [here](https://gitlab.com/loic.petit/cps2-reverse/-/blob/master/DLs/DL-0921/doc/star-raster.md) but also all the schematics for CPS-A and CPS-B chips.
I'm working on them now and will update the core this week.

ArtemioUrbina, 2021-09-29:
Awesome!

jotego, 2021-10-01:
This is fixed now. I have to make sure the changes didn't affect CPS2 so I will upload the source code later.
I'm not sure about Forgotten Worlds now. The circuit is correct, but the core may be reading the ROM at the wrong place. I need some original pictures for reference.

Strider is perfect. Arcade:
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

Core:
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

Closed 2021-11-10.

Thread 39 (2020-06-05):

Strider: artefacts around Hiryu's character in certain positions.

Left-Empty, 2020-06-05:
Hello, Hiryu seems to have black pixels around its sprite in certain positions, in a way reminding me a bit of [a past 3 Wonders issue]( https://github.com/jotego/jtbin/issues/39).

Here are two examples screenshots:

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

Cheers!

jotego, 2020-06-05:
I think those can be seen in MAME too. It may an artefact on the original board too.

Left-Empty, 2020-06-05:
You are absolutely right: ironically, the "grosser Pixel" quality on my MAME setup made the thing less apparent than on the erotic direct video output of the MiSTer.

Closed 2020-06-05.

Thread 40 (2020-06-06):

CPS1 Carrier Air Wing sprite priority bug

PhantombrainM, 2020-06-06:
Yesterday I played Carrier Air Wing all 9 (or 10?) rounds with Continue dip on.

I noticed when the plane is fueled up (all three rounds or so?) that the pipes are flying through the air and I thought it looks weird.

So I opened Youtube and found the same behaviour but also some YT Vidoes without the problem. I think it's a bug.

Wrong (like on MISTer):
https://www.youtube.com/watch?v=ev1rgJm6uWw&t=545s

Seems right:
https://www.youtube.com/watch?v=T2ffq0MHzGI&t=306s

Also I lost control during the game at stage 7 or 8 (no control anymore and I died). Then I noticed I need to press start again and from that on I was player two (?) until the end of the game. Strange. I don't know why this happened and if it was a one time issue or not. Maybe I'll play it again tonight.

jotego, 2020-06-08:
This was originally issue #28 but it is described better here. There is a pic here:
https://clips.twitch.tv/IntelligentPiercingCoyoteFloof
The problem is that when I looked at the internal video signals, the drawing actually makes sense as it is. So I think I may be missing a piece of the puzzle. MAME gets this right but gets the NEMO letters wrong, which are very obvious too.
This will get sorted when I finally receive the EPROMs I've been waiting for.

The second issue you mentioned sounds more like a software problem. Maybe a different version of the game will work ok.

c0d3h4x0r, 2020-06-13:
I just noticed the same bug and took a photo of it.

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

jotego, 2020-12-08:
Technical notes:
Layer use:
SCR1 = text
SCR2 = big plane
SCR3 = clouds
OBJ = small plane and hoses
Control registers:
PRIO0 = 0000
PRIO1 = F7FF
PRIO2 = 03FE
PRIO3 = FFFF
Layer control = 1A5A

PhantombrainM, 2021-01-31:
FYI. Tested. CPS 01/31/2021 Carrier Air Wing sprite priority glitch after 2rd Level is still present. But new DMA runs butter smooth now.

asturur, 2021-07-28:
Also the capcom arcade museum for consoles do this right. in the 30 June version of the core the bug is still present.

jotego, 2021-12-17:
Fixed in 0fdcb02. But NEMO letters during the demo now look like in MAME. Maybe there are really supposed to be like that?

asturur, 2021-12-17:
Oh wow is cool that is been fixed. What was the issue? Does it affects more than just carrier air wing and nemo?

jotego, 2022-06-25:
The commit 0fdcb02 that *fixed* this issue, broke
- "Three wonders" intro. See #131
- Final Fight and Varth alignment. See #132
The priority mux section was reverted in edd0cb9, reopening this issue.

asturur, 2022-06-25:
gonna have 2 copies of the core 😏

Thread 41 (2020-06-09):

Many MRAs are missing MameVersion

c0d3h4x0r, 2020-06-09:
**/media/fat/Scripts/mra_rom_check.sh** says:
```
There are issues with one or more of your MRA or MAME files

Please gently encourage Developers and Maintainers of MRA files to correct files with broken XML, missing CRC values and missing MAME versions values to correct their MRA files
```

**/tmp/mra_rom_check.log** says:
```
/media/fat/_Arcade/1941  Counter Attack -World 900227-.mra:No MameVersion
/media/fat/_Arcade/Adventure Quiz Capcom World 2 -Japan 920611-.mra:No MameVersion
/media/fat/_Arcade/Captain Commando -World 911202-.mra:No MameVersion
/media/fat/_Arcade/Carrier Air Wing -World 901012-.mra:No MameVersion
/media/fat/_Arcade/Daimakaimura -Japan Resale Ver.-.mra:No MameVersion
/media/fat/_Arcade/Daimakaimura -Japan-.mra:No MameVersion
/media/fat/_Arcade/Dynasty Wars -USA, B-Board 89624B- -.mra:No MameVersion
/media/fat/_Arcade/Final Fight -World, set 1-.mra:No MameVersion
/media/fat/_Arcade/Forgotten Worlds -World, newer-.mra:No MameVersion
/media/fat/_Arcade/Ganbare! Marine Kun -Japan 2K0411-.mra:No MameVersion
/media/fat/_Arcade/Ghouls'n Ghosts -World-.mra:No MameVersion
/media/fat/_Arcade/Ghouls'n Ghosts -patched-.mra:No MameVersion
/media/fat/_Arcade/Gulun.Pa_-_Prototype_1993_-_Japan_931220_L-.mra:No MameVersion
/media/fat/_Arcade/Knights of the Round -World 911127-.mra:No MameVersion
/media/fat/_Arcade/Magic Sword  Heroic Fantasy -World 900725-.mra:No MameVersion
/media/fat/_Arcade/Mega Man  The Power Battle -CPS1, USA 951006-.mra:No MameVersion
/media/fat/_Arcade/Mega Twins -World 900619-.mra:No MameVersion
/media/fat/_Arcade/Mercs -World 900302-.mra:No MameVersion
/media/fat/_Arcade/Nemo -World 901130-.mra:No MameVersion
/media/fat/_Arcade/Pang! 3 -Euro 950601-.mra:No MameVersion
/media/fat/_Arcade/Pnickies -Japan 940608-.mra:No MameVersion
/media/fat/_Arcade/Pokonyan! Balloon -Japan 940322-.mra:No MameVersion
/media/fat/_Arcade/Quiz %26 Dragons  Capcom Quiz Game -USA 920701-.mra:No MameVersion
/media/fat/_Arcade/Quiz Tonosama no Yabou 2  Zenkoku-ban -Japan 950123-.mra:No MameVersion
/media/fat/_Arcade/Street Fighter II  The World Warrior -World 910522-.mra:No MameVersion
/media/fat/_Arcade/Street Fighter II'  Champion Edition -World 920513-.mra:No MameVersion
/media/fat/_Arcade/Street Fighter II'  Hyper Fighting -World 921209-.mra:No MameVersion
/media/fat/_Arcade/Street Fighter Zero -CPS Changer, Japan 951020-.mra:No MameVersion
/media/fat/_Arcade/Strider -USA, B-Board 89624B-2-.mra:No MameVersion
/media/fat/_Arcade/The King of Dragons -World 910805-.mra:No MameVersion
/media/fat/_Arcade/Three Wonders -World 910520-.mra:No MameVersion
/media/fat/_Arcade/U.N. Squadron -USA-.mra:No MameVersion
/media/fat/_Arcade/Varth  Operation Thunderstorm -World 920714-.mra:No MameVersion
/media/fat/_Arcade/Willow -World-.mra:No MameVersion
```

jotego, 2020-09-09:
I won't correct it myself. I leave the issue open in case someone wants to add the information to the MRA files in https://github.com/jotego/jtbin

jotego, 2021-01-31:
Atrac17 and Chocobobo are working on a new MRA set for these cores. This is covered by their solution so I will close the issue here.

Closed 2021-01-31.

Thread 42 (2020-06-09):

1941 - right edge of screen (in landscape HDMI display) has weird defect

c0d3h4x0r, 2020-06-09:
Not sure if this is accurate of the original hardware or not, since I don't have original hardware to compare against.  But I've noticed that a few columns of pixels at the right edge of the screen don't appear to render correctly.

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

jotego, 2020-09-09:
I have tested it:
-It doesn't occur in MiST
-it occurs in MiSTer for analogue 15kHz output or HDMI (rotated or non rotated)
I'm going to investigate it

jotego, 2020-09-09:
It only happens if the DIP switch for flip is enabled both in MiST and MiSTer. I didn't see it in MiST because the flip was off by default.
This points to some problem in the scroll data DMA involving the flip bit.

jotego, 2020-09-10:
This is now fixed in commit 1b6327b7fc1201a27b7d390cb54178d6def1d08f
I'll create new RBF files. I'm closing the issue now.

jotego, 2020-12-07:
This happens again in commit https://github.com/jotego/jtcps1/commit/bac12ec630ee3a4161137427fa8bc1f7a2836994 after fixing this assignment:
```
-wire        tile_vs  = vrender1== flip ? 9'd17 : 9'd12; // Vertical start, use for SCR3
+wire        tile_vs  = vrender1 == (flip ? 9'd17 : 9'd12); // Vertical start, use for SCR3
```

M-Walrus, 2021-01-31:
Adding another example of this bug occurring in Varth:
https://youtu.be/A_6O4TvEd8E

Clouds and large boss ships exhibit this bug throughout the game.

jotego, 2021-02-01:
This is fixed now locally. I will update the binaries later (today).

Closed 2021-02-01.

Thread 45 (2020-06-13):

Street Fighter II': Hyper Fighting (USA 921209)

mrfpga, 2020-06-13:
In 1P mode on the Balrog (Claw) stage there are graphical glitches in the center of the stage, where the women are dancing in the background. Thre is a horizontal stripe below their feet with random colours that are permanently changing.

EDIT: The problem occured on the MiSTer core, not sure about the other systems.

mrfpga, 2020-07-01:
@jotego

Here is a video showcasing the bug, which is already present on Street Fighter II: Champion Edition:

image:
https://ibb.co/52Xc3Gs

video:
https://youtu.be/tHlIP2nwj3M?t=834

cracklejoy, 2020-07-22:
This is not a bug.  Those are the lights for the stage and have been there for in sf2,sf2ce and sf2hf.

Closed 2020-07-23.

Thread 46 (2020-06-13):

Street Fighter Alpha: Warriors' Dreams (CPS Changer, Publicity USA 950727)

mrfpga, 2020-06-13:
When playing 1P mode for some time random voice samples start playing like the knockout cry long before the round is over.

EDIT: The problem occured on the MiSTer core, not sure about the other systems.

jotego, 2020-12-31:
I am going to assume this is related to #61. I will review the ADPCM chip controller. I am closing this here and will track it in #61.

Closed 2020-12-31.

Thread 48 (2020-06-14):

SF2WW USA 911101 Flicker

mikey1964, 2020-06-14:
I check my ram and it seems ok pass all test . this flicker happens in all stages but easy to see in sagat stage . when you beat a fighter in this case sagat with a perfect hold the
 buttons to increase the speed of the score count it will cause some parts of the background to flicker in video look at the rock and sagat body on the ground video is in zip file. I do not have a arcade pcb to see if this is normal behavior

[IMG_3680[3444].zip](https://github.com/jotego/jtbin/files/4775746/IMG_3680.3444.zip)

jotego, 2020-09-10:
Sorry it took me a while to get down to this issue. I agree with paulb-nl. Thank you both for reporting and resolving the issue.

Closed 2020-09-10.

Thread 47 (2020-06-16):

Buzzing Sound in Dinosaur Hunter (Chinese bootleg of Cadillacs and Dinosaurs)

MJY71, 2020-06-16:
There is a rather loud constant buzzing sound with Dinosaur Hunter (Chinese bootleg of Cadillacs and Dinosaurs). It almost sounds like a very loud ground loop. ROM used is the merged dino.zip from MAME 0.221, which includes the dinohunt clone. All CRCs have been verified. The MRA also references dinoh.zip for some reason, even though none of the ROMs in that set are called for.

With the DIP switches at default settings with the latest MRA from the 20200604 Alternatives collection, the noise can be heard from the character select screen onward, with the buzzing stopping occasionally and starting again.

With the Demo Sounds DIP switch set to On, it can also be heard as soon as the characters appear in the vehicle during attract mode.

No music can be heard, but some sound effects are barely audible, being masked almost entirely by the noise. Turning off ADPCM and/or FM has no effect.

MJY71, 2020-06-27:
That sounds great. I submitted this just to have it on file as suggested, but I think it was submitted before you confirmed that you were going to be working on Q-Sound... so now I don't care about this issue. ;)
Thanks!

Closed 2020-09-09.

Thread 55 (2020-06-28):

CPS1 background layer missed in Three Wonders intro.

jegayon, 2020-06-28:
There seems to be a problem in the background layer in the introduction of Three Wonders:

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
I hope these screenshots help.

paulb-nl, 2020-09-29:
With Turbo enabled the backgrounds appear correctly.

jotego, 2020-09-30:
Excellent hint. Thank you!

jegayon, 2020-09-30:
Umm... I must have something wrong with my Mist core, because even with the Turbo option activated the issue remains....

jotego, 2020-10-01:
Turbo function doesn't work in MiST from the OSD.
I can confirm that enabling turbo fixes it in MiSTer.

jegayon, 2020-10-02:
Yes!!! I just recived my Mister today and I can confirm it too.

jotego, 2020-12-07:
I tested it today using the new SDRAM controller, in case this was a memory contention issue. But the result was the same: no background for no turbo, background for turbo.

I wonder if the game should actually be set at 12MHz CPU permanently. I will try modifying the MRA to set 12MHz.

For my reference, this is how the scenes should look like.

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

jotego, 2020-12-30:
It happens even if CPU speed is set at 12MHz in the MRA file. Maybe the DMA starts a bit too early in the line.

jotego, 2020-12-30:
Compiling with FORCE_GRAY does not show the backgrounds either, so it is not a missing palette problem.

jotego, 2021-01-31:
Six months later...

The speed measurements I have made for issue #33 gave the final hint. When I applied the first fixed to the DMA (speeding the core by 5%), the backgrounds showed up. The problem was that the core was running too slow. I have it fixed locally and I will release the binary update today.

Thank you for reporting this and sorry for the long wait.

Closed 2021-01-31.

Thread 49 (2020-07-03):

CPS1 Core button mapping not working on SF2 games for X-Arcade TankStick

wiggy808, 2020-07-03:
@jotego

Patreon here.
I've submitted a ticket to X-Arcade techs, they indicated (as well as Classic Gaming Discord channel) that it was a core issue.
The X-Arcade Tankstick is basically a keyboard encoder, so opening up notepad, the buttons input letters and keys from the keyboard.

During button mapping of Player 1 on any of the CPS1 Street Fighter 2 series (SF2, SF2CE, etc. ), Player 2 does not have button mappings for kicks, only the 3 punches, while Player 1 has all 3 punches and kick buttons mapped and working.

Couple things that might help:
1.) Final Fight works great for both players, as they each only need 3 buttons instead of 6, so I'm assuming that might help you key in on the issue some way.
2.) The device does come up as keyboard on MiSTer when CPS1 loads, and same ID is detected when doing button mapping for both player 1 and player 2 because there is only 1 USB plug that is used to carry both players input.

Let me know what I can do to map player 2, as the .map and .cfg input files are not ascii so i don't know of a way to just set them in a file manually.

Thanks
Wiggy

jotego, 2020-11-19:
Sorry for the long delay in response. When I first read this I thought someone else would reply with a solution. Sometimes it does happen!

Now that I read more, I think it may be indeed a problem with the core. My cores convert key presses to joystick movements and that is probably interfering with MiSTer firmware, which also may be trying to do that for your joystick.

I will release the second CPS 1.5 beta without the internal keyboard mapping so it will all be left to MiSTer firmware to handle. Let me know how that goes.

Apologies again for missing to reply promptly.

wiggy808, 2020-11-19:
No worries, I’d say this is probably solved no need to change anything.

I was able to narrow down the problem (as it occurred on the SNES core as well), to xinput vs Dinput modes on my joystick.

See my ticket here as it’s now solved as of yesterday so everything works on CPS1 and other cores as well.

https://github.com/MiSTer-devel/Main_MiSTer/issues/276#issuecomment-730326217

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

jotego, 2020-11-20:
Thank you for your feedback. I always doubt about removing the keyboard mapping from the cores in case some users already use it.
I will close the issue now.

Closed 2020-11-20.

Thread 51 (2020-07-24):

MiSTer update_all removed Xinput support for CPS1

wiggy808, 2020-07-24:
Not sure what part of the update_all script affected this.

I had an image that I added CPS1 cores too via Patreon. Unable to map the keys (other issue already open) for the X-Arcade Tankstick, I upgraded the PCB to the Tri-mode board so that it could be used as a DirectInput or Xinput or Keyboard Input (only option before upgrade). I tried both DirectInput and Xinput modes, all buttons for both players worked fine.

After running an update_all, I'm now only able to use DirectInput mode for CPS1 cores, Xinput no longer allows me to map Player 2 buttons. Player 2 moves player 1.

jotego, 2020-07-24:
I don't see how this can be related. Let me try to get the author of update-all script into the conversation.

theypsilon-test, 2020-07-24:
Hi @wiggy808 , is this issue also happening with other arcade, computer, and console cores?

theypsilon, 2020-07-24:
Hi @wiggy808 , is this issue also happening with other arcade, computer, and console cores?

wiggy808, 2020-07-24:
No, but SF2 is the only core that requires 6 buttons per player. Even before I upgraded to Tri-Mode PCB, I was able to play Final Fight etc in keyboard mode on XArcade Stick.

As long as I only have to map a few keys, any of the modes seem to work. It was just something I noticed after upgrading to the Tri-Mode PCB that I couldn’t map all the keys in Xinput mode, only in Directinput mode.

So it’s definitely possible that other cores are affected, I just don’t have another core that requires 6 buttons per player to be a good test, so I opened up the issue with your CPS1 core.

Lemme know how I can test this better to help narrow down the cause.

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

wiggy808, 2020-07-24:
Apologies didn’t hit reply all.

No, but SF2 is the only core that requires 6 buttons per player. Even before I upgraded to Tri-Mode PCB, I was able to play Final Fight etc in keyboard mode on XArcade Stick.

As long as I only have to map a few keys, any of the modes seem to work. It was just something I noticed after upgrading to the Tri-Mode PCB that I couldn’t map all the keys in Xinput mode, only in Directinput mode.

So it’s definitely possible that other cores are affected, I just don’t have another core that requires 6 buttons per player to be a good test, so I opened up the issue with your CPS1 core.

Lemme know how I can test this more to help narrow down the cause.

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

theypsilon, 2020-07-24:
Maybe you could try with SNES and Genesis cores, they have 6 button controllers.

wiggy808, 2020-07-24:
Good call. I added SF2 rom for SNES, same issue with Xinput selected on X-Arcade as I saw with CPS1 core and no problems with DirectInput selected for SNES SF2.

Unfortunately, I would have to assume XInput worked on SNES before the update_all for the SNES core as well, since I only had tested the CPS1 core just before and after the update_all (I primarily use the MiSTer for arcade).

Couple thoughts. First, Not sure how to move this ticket to a MiSTer issue vice CPS1 issue like is now. Second, just to clarify how I’m doing the button mapping:

1. I unplug X-Arcade (not necessary but for good measure)
2. Set Switch to Xinput mode on Xarcade
3. Plug x-Arcade back in.
4. Reset MiSTer
5. Select OSD and Reset to map new joystick
6. Map joystick 1 starting with A button on joystick 1
7. Redo #6 with A button and map all of player 2 joystick controls.
8. Start SNES core —> SF2
9. Bring up OSD menu
10. Select Map buttons for game using A button on joy1
11. Repeat but using A button and map joy2

Using the exact steps above, when step 2 is on Xinput, when all this is done, Joystick 1 and Joystick 2 both move / control player 1 (like the CPS1 core).
When step2 is on DirectInput, both joysticks work as player 1 and player 2 just fine and have all 6 buttons working as expected.

Hope this helps, lemme know if I can test anything else.

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

theypsilon, 2020-07-24:
I think the better place to post this issue would be here: https://github.com/MiSTer-devel/Main_MiSTer/issues

update_all might have installed a newer version of Linux or Main_MiSTer binary through the main MiSTer-devel updater, and that newer version might have some problem with Xinput.

You will get better support there for sure.

wiggy808, 2020-07-26:
Will do, thanks!

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

jotego, 2020-08-05:
Closing it here then.

Closed 2020-08-05.

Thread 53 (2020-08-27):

Options menu in Street Fighter Alpha (CPS Changer)

raziel2001au, 2020-08-27:
It's supposed to be possible to access the options menu which contains settings like difficulty in the CPS changer version of Street Fighter Alpha by pressing Start 2 + Pause at same time for 1 second. However, the pause implemented in the core is not the same as the pause button on the CPS changer. Even if it was it's not a well known feature so I'm wondering if it's possible to add some sort of menu option or shortcut in the core to access the settings menu of the game?

jotego, 2020-12-17:
I have implemented this request. Sorry for the long delay and thank you for letting me know about this. I had no idea.
I will release it tomorrow.

raziel2001au, 2020-12-18:
Perfect, thanks jotego! Out of interest sake, what kind of solution did you go with in the end?

jotego, 2020-12-19:
I just did what you said. The unused coin button is used for the charger pause. This means you have the original system pause available.

raziel2001au, 2020-12-20:
Perfect, thanks!

Closed 2020-12-17.

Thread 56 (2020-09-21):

CPS1 Willow sprites not fading out with background.

squidrpi, 2020-09-21:
Noticeable on Willow opening screen (below) showing the worlds. When the background fades out the sprites do not fade, just switch off. Possibly related to [#32]

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

paulb-nl, 2020-10-04:
The sprites do fade with the background but it is difficult to see with the current brightness curve. The sprites do stay a few frames longer than the background.

Here is a video with the fade out going darker where it is easier to see:
[https://youtu.be/a_vxJwQQTuA](https://youtu.be/a_vxJwQQTuA)

jotego, 2021-01-18:
I have replaced the quick calculation method by a [look-up table](https://github.com/jotego/jtcps1/blob/master/cores/cps1/hdl/pal_lut.hex) obtained by solving the electrical circuit in the schematics. I believe this is as accurate as it gets. Please check it out, just update MiSTer to get the files.

Closed 2020-10-03.

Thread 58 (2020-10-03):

CPS1 brightness attenuation

paulb-nl, 2020-10-03:
As I posted here https://github.com/jotego/jtbin/issues/32#issuecomment-612374620 it seems the brightness is not attenuated enough compared to the real hardware.

Mame has a max attenuation of 66% and this core has a maximum of only 33%.

I made a test build replacing this:
https://github.com/jotego/jtcps1/blob/1dc20fb6f740f37cd3d95dd30bfaa56f6d3bd82d/hdl/jtcps1_colmix.v#L229-L231
with this:
````verilog
red   <= {2{dly_r}} - (mul_r>>1) - (mul_r>>2);
green <= {2{dly_g}} - (mul_g>>1) - (mul_g>>2);
blue  <= {2{dly_b}} - (mul_b>>1) - (mul_b>>2);
````
and indeed the fade in/out looks a lot smoother.

jotego, 2020-10-07:
Hi Paul,

Thanks a lot for looking into this. I think I based the attenuation on the Bionic Commando schematics and I had it pending to measure it. It looks like your approximation works better. I would like your name to show in the commit.

Would you mind making a PR? In that case, please do it on the [CPS1.5 branch](https://github.com/jotego/jtcps1/tree/cps1.5), and that is currently the development branch.

Thank you

Closed 2020-10-11.

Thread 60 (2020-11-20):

Cadillacs & Dinosaurs - CPS1.5 (Beta 2)

ItsAtomico, 2020-11-20:
Middle part of the car (door section) flickers when the Cadillac rolls into the screen.

Can be tested at the start of Stage 2 or during attract mode. Tried USA, World and Asia roms, HDMI and CRT (via I/O board).

jotego, 2020-11-20:
I think this is the same problem as #44

jotego, 2020-12-11:
Just pasting the snapshot here for reference.

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

jotego, 2021-01-23:
This is fixed now in the CPS2 branch of the repository after simplifying the sprite engine. I will update the binary files next Friday (30th Jan).

Closed 2021-01-23.

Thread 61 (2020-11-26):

PCM sound missing in Street Fighter II series.

PepAlacant, 2020-11-26:
It lacks a sound on Chun-li Stage music. It seems a PCM is missing on the melody. It's a instrument that sounds almost all the time in the melody. Here is a sample of how it should sound.

https://www.youtube.com/watch?v=H2dgVJy8jZM

It happens on both MiST and MiSTer jtcps1 Cores.

jotego, 2020-11-26:
That's just an awesome finding. And quite an embarrassing one too. There is definitely a PCM channel missing. I will get it fixed.

PepAlacant, 2020-11-28:
It happens in other games too, lost or very low PCM channel. I suppose it's the same issue than in Street Fighter II. The King of Dragons loses percussions and other games! Thanks for your excellent work.

jotego, 2021-01-01:
The sound commands are issued in time, and there is a sound produced at the right time. But it is not the same sound.

The sound seems to be produced by ADPCM phrases **4** and **B**. The Z80 sends two commands very closed to each other for each phrase: 4, 4 and then B, B. The PCM module is requesting the right data and getting it correctly.

Parsing the SF2 OKI ROM directly and listening to sounds 4 and B, I find that they sound quite different from how they sound in the arcade (or at least in MAME). Even when parsed with the MAME C code.

I do not understand right now why these two sounds are played differently. Some ideas:
-Side effect of the second issued command with the same phrase
-Different response to saturation

jotego, 2021-01-02:
It was just the linear interpolator removing too much HF content. Replacing it with a full FIR x2 interpolator preserves the HF content, and the sample sounds as expected. Removing interpolators all together is also a valid option.

I will release an update today.

Closed 2021-01-02.

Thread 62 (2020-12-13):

CPS15 build

gyurco, 2020-12-13:
I think some things are missing for a successful build:
cores/cps15/patrons/msg
jtdsp16 module (also referred as git@github.com url, not https://)

jotego, 2020-12-17:
Yes, I rushed a little bit with the public files. A commit was missing inside the Mister template in JTFRAME too...
I am not planning to publish JTDSP16 as I am a bit afraid of commercial companies using the code without complying with the license.
I can give you access to the private repository if you want to see it. I will publish it when I am done with CPS2.
However, you do not need it to build CPS15. You can just define the macro NOSOUND, or simply compile with **jtcore cps15 -q** and you will get the core compiled (with no sound, though).

gyurco, 2020-12-18:
For my purposes, sound is not required. I just want to try the new EEPROM saving feature in the firmware.

jotego, 2020-12-19:
It should compile correctly now. I fixed the missing commits.
This is the kind of thing I want to prevent (or at least delay):
https://www.ebay.com/itm/Analogue-NT-NES-24K-Gold-Plated-Factory-Sealed-Brand-New-System-9-out-of-10-/193258367366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

jotego, 2020-12-19:
About the EEPROM, the module I use for storing the values in the core already has a secondary set of ports there in place. The idea is to connect that to whatever saves to the SD. If you get that done, it would be awesome!

gyurco, 2020-12-19:
With a parallel interface for jteeprom, it would be a piece of cake. But I don't see that, what should I look for?

Yeah, you cannot know what was used by Analogue. Also it was very interesting when Ijor released his FX68K CPU, their Genesis suddenly appeared.

jotego, 2020-12-19:
I have connected the lines in jteeprom and pushed it.
Please update CPS15 with submodules and look for this line: https://github.com/jotego/jtcps1/blob/344ec615ca12e35470ecc473df793e886ec99bcb/cores/cps15/hdl/jtcps15_game.v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

gyurco, 2020-12-19:
I see now. A dump_we would be also needed to restore the EEPROM at core boot (I've implemented it by sending a .RAM file via ioctl_index=1 just after the .ROM).

gyurco, 2020-12-19:
Btw, which branch of jtframe should I use? I see the branch for cps15 is diverged from master, where the data_io change is already committed. Are you planning to merge jtframe/sdram back to master?

gyurco, 2020-12-19:
I've sent a PR to jteeprom. I have the necessary jtframe changes also, but in the master branch, which doesn't compile with cps15. So I wait with that.

gyurco, 2020-12-19:
Another problem that without the sound board, no controls at all, thus I cannot enter service mode and try to change some settings :)

gyurco, 2020-12-19:
It's the jtframe change for master:
https://github.com/gyurco/jtframe/commit/0d855969fe2864ad25d3e02fa4cc478a9f902a29
I won't send a PR until the dust settles on the repos, or you can integrate it in your own way. The cps15 change itself is very minimal.

jotego, 2020-12-19:
Thank you. Let me merge the changes in master to the SDRAM branch and check that it compiles correctly.

jotego, 2020-12-19:
It has taken a couple of trials but if you update CPS1.5 and run a submodule update, it should all work. I cannot still update the master branch of JTFRAME as the SDRAM interface has changed, and I still do not consider it stable.
Could you try your change on these files?

gyurco, 2020-12-19:
Looks like something is lost in the sdram branch, as USEWAITN is no longer in jtframe_z80_romwait.

gyurco, 2020-12-19:
...and I only get a black screen for every games.

jotego, 2020-12-19:
It's strange... I have just checked the commits in Github, and they are correct.
I tried compiling again a moment ago, and it well. I wonder whether you missed running the _submodule update_ command.

gyurco, 2020-12-19:
Now OK...for some reason I didn't get the two new commits in the cps15 repo.
Unfortunately only 00's are written in the RAM file. I have to check if the error is on the serial or the parallel side of the EEPROM.

gyurco, 2020-12-20:
It works finally!
I sent you the PRs (submodule update is not included), and a new firmware via email.

jotego, 2020-12-20:
Just tested it here. It's pure joy!
Let me know here when you publish the firmware. I will release the updated core then.
Sound is still noisy with the sigma-delta output of MiST. I will be lowering the system frequency to 48MHz next. That may help with the sound noise too.
I may refactor the code a bit. Maybe push it to jtframe_dwnld or the core-specific _dwnld/prom_we module.
Thanks a lot.

gyurco, 2020-12-20:
Great! I've just released the new firmware (201220). Note that it also has 64-bit status word support, too (Street Fighter should use it  - it's broken currently).
I've tried to make this change as simple as possible, and it should be backwards compatible with existing cores, too (if no CORE_NVRAM_SIZE is defined, that the game interface is unchanged). But of course, it's your code, and it must fit to your taste, too.

48 MHz SDRAM clock for CPS1? Won't be too slow? Isn't it possible to keep 96MHz at least for MiST/SiDi? Maybe if the core and the sdram clocks can be separated (SDRAM controller can be 48 or 96, but all other parts are only 48, as it's done in many other cores), then it'll be easy to do it.

gyurco, 2020-12-23:
The noisy sound on MiST couldn't be because of the overall volume level is very low? Just compare it with CPS1, CPS15 is very silent.
Btw, Merry Christmas!

jotego, 2020-12-23:
Merry Christmas!

Yes, the volume is low but there is a lot of HF content that saturates the sigma-delta modulator easily. Reducing the frequency of the modulator helps in avoiding saturation. Having an integer relationship between the DAC clock and the sample rate also prevents noise and when I fixed that I got rid of horrible noise. But it isn't clean yet. I think messing a bit with the clock enable of the DAC may fix it.

This DAC output is for me one design flaw of all homebrew FPGA platforms. It takes sigma-delta modulation for granted, simplifying it to great lengths. On MiSTer it is possible to connect an external DAC and bypass the 1-bit modulator. The difference is abysmal.

jotego, 2020-12-30:
ioctl_index in data_io does not have a reset value, which kills my sims. I tried setting it to 8'd0 at SPI_SS2 posedge but that creates problems in the actual core compilation. Games don't boot up if I do it. I do not understand why. Does it make sense to you? @gyurco

gyurco, 2020-12-30:
You can use ioctl_download/ioctl_upload to determine if it's valid. If they're 1, then the index is surely valid.

gyurco, 2020-12-30:
Resetting it with SPI_SS2 will reset it every time the ARM stops using the SPI.

Closed 2021-01-17.

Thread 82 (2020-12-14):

V-Sync issues with Cadillacs and Dinosaurs and Warriors of Fate

Alex-Catalin, 2020-12-14:
As the title suggests, I noticed some V-Sync issues with these 2 games. They appear always at the same time, in the same places in the game.

For example, in Cadillacs and Dinosaurs, they can be seen right at the beginning, in stage 1 and they appear again in the second level, when you are in the swamp. On Warriors of Fate, they look even worse than on Cadillacs and Dinosaurs.

I have not experienced any other issues, such as crashes or anything else, just these V-Sync problems which are consistent and appear every time in the exact same places.

Closed 2021-03-05.

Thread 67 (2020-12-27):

WILLOW strange turbo behavior and unassigned buttons

Rageypoo, 2020-12-27:
Hello, just wanted to let you know that in WILLOW if you use the attack or jump buttons it speeds up the game insanely fast in everything except once the game starts. It speeds up text, animation, and the countdown timer if you die. Is this normal?

Also, there is a button assignment that doesn't seem to exist. The game had 2 buttons, one for attack and one for jump, but when doing button assignments there is a third button that seems to be blank.

jotego, 2020-12-30:
Hi, yes, it is normal. It is the way the game was designed. Check out the dip switches. There is a "turbo" function that might be related to that. I have not tried it out myself.

The third button is read at least in test mode. It seems not to be used during gameplay.

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

Closed 2020-12-30.

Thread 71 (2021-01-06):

Sound issue in Street Fighter II series

nickcsbr, 2021-01-06:
Hello,

Since the last update I have noticed that the ADPCM samples in Street Fighter II series are sounding very low quality for the CPS1 core. The hit sounds, the airplane sound and specially the voices are the most noticeable ones. Please let me know if any other information is needed and keep up the amazing work! Thank you.

SegaSnatcher, 2021-01-09:
I noticed this too, glad it wasn't just me.

SegaSnatcher, 2021-01-11:
Final Fight sample audio also sounds worse now.

jotego, 2021-01-12:
I am implementing the original on-board filter and more precise upsampling filters for the next update. But, all the signal flow outside the core is out of my control. The different filters and D/A converters will affect the sound too. This is especially true if you use the cheap analogue output in MiSTer. Then there is another problem: many people only remember MAME, not the real sound.

Here is the frequency response of the on-board filter for the PCM channel. I hope you find this more to your liking when I finish it.

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

jotego, 2021-01-13:
I think this is solved now in commit https://github.com/jotego/jtcps1/commit/6e1934ac39cf118277dd936cc3d59d75383904aa
You can hear it in the attached file. I will release the update on Friday.

[final fight.mp3.zip](https://github.com/jotego/jtcps1/files/5810099/final.fight.mp3.zip)

nickcsbr, 2021-01-13:
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

Perfect! Thank you for your incredible work!

Closed 2021-01-13.

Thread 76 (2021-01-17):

CPS1: Top row glitchy line of pixels in Street Fighter 2 Hyper Fighting.

SegaSnatcher, 2021-01-17:
I took a video of the issue.

https://www.youtube.com/watch?v=rmytFhembWg&feature=youtu.be

jotego, 2021-01-17:
I attached a 96MHz compilation to the last Patreon post. I suppose there are no glitches there. This is the DMA being late for 48MHz SDRAM compilations.

Closed 2021-01-17.

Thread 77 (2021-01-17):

DMA Measurements

jotego, 2021-01-17:
I measured the DMA in a SF2 board by looking at the bus request signal of the M68000. I came up with a model for it detailed in [DMA.md](https://github.com/jotego/jtcps1/blob/master/doc/DMA.md).

DMA is used to read data from the shared RAM. The main CPU is stopped during that time. Reads are spread across the whole frame.

-Palette is read during vertical blanking
-Row scroll position, scroll tiles and the OBJ table are read during horizontal blanking, in small pieces

Depending on the size of tiles for each scroll layer, the DMA period varies. SCR1 has the most frequent DMA access as its tiles are 8x8. SCR3 is the least often as tiles are 32x32.

DMA steals a lot of time from the main CPU. It looks like when a section is not needed, its DMA transfer is not executed. It is not clear which CPS-A registers are used to enable the DMA. But it looks like some registers are refreshed each frame by the CPU without a real need for the refresh. Particularly the base memory registers. I am assuming that the palette and object tables are only copied when the base memory registers are written to. I am currently copying tile data for every frame and row scroll data for every frame if row scroll is enabled. That is probably more than needed and it may be slowing down some (not many) scenes.

The object table can have a special code to mark the final object. It is not clear if the DMA will stop after reaching that byte.

There is a state machine controlling the DMA inside the CPS-A chip. It seems to operate at 4MHz. At least, memory transfers are done at that speed. In between one type of memory transfer and another, there are some state machine cycles involved. I don't know exactly how many of them are there.

I would need a piece of software that runs on an SF2 board that does this:

-Have two selectable object tables, a long one and a short one (with the termination code)
-Display some video using all layers
-It should refresh all registers on the V blank interrupt:
 1. Palette base address
 2. Object base addr.
 3. SCR1 b. a.
 4. SCR2 b. a.
 5. SCR3 b. a.
 6. Row scroll b. a.
 7. Layer enable bits in the video control registers
-It should let the user turn on and off individually which one of the registers will be updated, and which type of object table is used
-Run a counter to show how many counts can be done per frame. The number of counts will vary depending on how many DMA items are active.
-The row scroll table should have non zero values to make it obvious that is being used
-By individually selecting and disabling these bits, and measuring the board, it will be possible to know which ones have an effect on the DMA, and which don't.

jotego, 2021-01-31:
The first test suite is here: https://github.com/originalgrego/sf2ww_dma_tests

jotego, 2021-03-09:
Done

Closed 2021-03-09.

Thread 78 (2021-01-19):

CPS1: 1941 very low FX volume option still over powers music.

SegaSnatcher, 2021-01-19:
I feel even the lowest volume FX option might be a bit too loud for those that want to hear more of the FM music.

Would be nice if very low was adjusted slightly lower so the FM music could be heard more.  This is with the filter setting off.

Here is an example of what I like to hear.

https://www.youtube.com/watch?v=rEqFyEjePZA

PhantombrainM, 2021-01-31:
Your Video says "Ver mame0.37b16".

The behavior of the music fx balance should be compared to a real pcb. If that mismatchs a issues ticket  should be created.

Otherwise it's more of a feature request than an issue.
JT cores already allows to disable FX completly, if you just want to listen to the music. Not sure if it needs even more options.

jotego, 2021-02-01:
I want to make a test for sound balance on the PCB, but this is going to take several weeks I suppose.
Once I have that information I will re-centre the OSD values around the measured value. I will make the "very low" option really sound very low.

SegaSnatcher, 2021-02-01:
Awesome!!!

SegaSnatcher, 2021-02-27:
Thanks for making FX lowest volume lower, but it seems all volume levels are now lower as a result.  Was this intentional?

jotego, 2021-02-27:
Yes, I turned everything down a notch. Let us leave it like that until I can make the measurements.

Closed 2022-04-17.

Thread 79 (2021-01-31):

"Original Filter" triggers noise artifacts (analog audio) MISTer

PhantombrainM, 2021-01-31:
If you load up Carrier Air Wing and let the first attraction cycle pass there is a remaining permanent sound with the following conditions:

-> MISTER CORE VOLUME in GUI Core Settings -> one step down
-> Original Filter : ON (OFF -> Voice gone)
-> FX Volume : LOW (other settings change pitch of sound)
-> FX: ON (OFF -> Voice gone)
-> FM: ON OFF -> Not affected
-> MISTer general Volume change F11/F12 (Full and one step lower changes pitch of the voice)

I can try to make a video if necessary.

paulb-nl, 2021-01-31:
This is caused by the audio DAC of MiSTer. SNES also has this issue.  Using Optical or HDMI audio extractor there is no issue.

jotego, 2021-01-31:
Like Paul says, this is artifact created by the cheap built-in DAC. There are techniques to minimize these problems but there is only so much you can do.
My recommendation since several years ago is to stop using cheap 1-bit sigma-feta converters and have a proper DAC connected to the FPGA.
MiSTer allows that by means of the optical output or the HDMI output.
I hope future FPGA systems for retro have a proper DAC installed on board.

I can try and add options to mess with the built-in DAC, like:

-reduce signal amplitude
-add dithering
-filter out low frequencies

But I think it's better if users buy an 8€ DAC, honestly.

Let me know what you think.

PhantombrainM, 2021-01-31:
I hadn't tried SNES, but I noticed it with the 48Mhz version already with Punisher. In the 96Mhz version it was gone again.

If it's a hardware problem with the Mister, then I'm not in favour of a workaround. Who knows where the journey will take us. That would then have to be removed again in a future hardware generation or revision, so not purposeful.

 I'll look into an external converter or I'll try to grab HDMI audio.

 I think the ticket can be closed with this.

PhantombrainM, 2021-01-31:
Closed. As discussed.

Closed 2021-01-31.

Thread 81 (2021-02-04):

CPS1 Original-filter comparison with PCB

paulb-nl, 2021-02-04:
Here is a video recorded from jtcps1 20210201 with filter enabled.
https://youtu.be/HNkTJRo_ZR0

Here are videos of the pcb:
https://youtu.be/4C1vcIH7FTA

https://youtu.be/EDXE0SsaCiM

Doesn't it sound like the filter is removing too much high frequency compared to the pcb? The cymbal and drum sound very muffled.

jotego, 2021-03-02:
I agree. I have just double check both the analogue (Forgotten Worlds schematics) and digital (JTCPS) filters in simulation, and they actually match.
I have a SF2 board too, I will compare the component values in that board. Maybe Forgotten Worlds, being the 1st game, had different values.
For now, I'd rather not change the filter. It may be wrong for SF2, but it may be right for other titles.

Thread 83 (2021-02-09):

CPS Cores do not support Custom AR:

Firebrandx, 2021-02-09:
Wanted to experiment with my own integer scaling and noticed CPS games do not support this feature. For example:

[sf2ce]                       
vscale_mode=1
custom_aspect_ratio_1=48:35

Does not work at all (you can't select the custom AR mode in the OSD). It's vital in my opinion that all cores should allow the user complete control over AR and integer scaling. The "Original" and "Wide" modes are too limiting in scope.

jotego, 2021-02-10:
I have added that now. Give me a couple of days to update the RBF files.

Closed 2021-02-10.

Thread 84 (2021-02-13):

[MiSTer] CPS 1 : 1941 - Counter Attack (Japan) -  reverse display for rom check part on HDMI

wwark, 2021-02-13:
This case is present just on HDMI, the case is ok on CRT.

I took screenshot with the Mister (option win+printscreen)
Rom Check
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
In game
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

We saw trhe rom check is inverted compared during the game.

Thanks,

jotego, 2021-02-13:
The screen orientation is controlled by the game. It seems like the game doesn't apply the flip setting until later.
I'm afraid there isn't anything I can do.

wwark, 2021-02-14:
Ok on Mame the behavior is not reverse on my LCD screen. Is Mame not have the correct behavior is this case ?
and also this issue is not present on CRT.

Thanks,

jotego, 2021-02-15:
Set the flip setting in MAME and you will see it happening there too.

For the CRT test, you must have run it with a different flip setting.

wwark, 2021-02-15:
ok if i set flip Mame i saw the reverse display but it is inverted between the mister core and Mame.
Thanks no need to check more on this case.

Closed 2021-02-13.

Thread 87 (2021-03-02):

Street Fighter Alpha (CPS2) Ryu's ending

jotego, 2021-03-02:
Ryu's ending screen looks black instead of showing an orange sky.

The sky is in layer SCR2, but SCR3 is configured to have priority over it, and it is all drawn with ink zero, which is not transparent. There must be some bit in the CPS-A/B chip to configure this, but we don't know it.

Reference: [CPS-B schematics](https://petitl.fr/cps2/DL-0921/#lut-assembly).

This is how it looks like:

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

And this is how it should look:

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

jotego, 2021-03-02:
This seems to be a ROM mapping problem. CPS2 is assumed to cover all ROM space for the SCR banks, but in this case SCR3 may be pointing to an unmapped region, and thus should be read as FF's (and be transparent)

Chocobobobo, 2021-03-04:
Just checked with my good friend Raph, who owns the blanka version of the PCB

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

paulb-nl, 2021-03-04:
Street Fighter Zero PCB:
https://youtu.be/P-zc4VzSZgU?t=396

https://youtu.be/qRfPZ-rqujY?t=817

Chocobobobo, 2021-03-04:
Yes, I watched every single video with it on YT. But with the poor image quality, it feels like some are using super eagle filter (meaning emulators are being used). This is why I am just trusting people I know, owning actual hardware (and streaming it for me to check).
But thanks Paul :)

Closed 2021-03-09.

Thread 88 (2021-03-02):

CPS1 - Crackling audio on Street fighter 2 Zangief stages

jadflat, 2021-03-02:
I'm getting some crackling on the music on Zangief stages on all three versions of Street Fighter 2. It does this over hdmi, 3.5mm and optical. Seems to be present only on the FM audio.

jotego, 2021-03-03:
Thank you. I am tracking this issue [here](https://github.com/jotego/jtbin/issues/175).

SatanicNemesis, 2022-02-07:
This has been closed but problem still persists

jotego, 2022-02-07:
Because the issue is being tracked in the link above. I have just moved it.

jotego, 2022-04-17:
I think that's just how the chip is supposed to sound. Other implementations sound the same: check track 20 [here](https://vgmrips.net/packs/pack/street-fighter-ii-the-world-warrior-cp-system).

Closed 2022-04-17.

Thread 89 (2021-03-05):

CPS1: 1941 is upside down (?)

r4dius, 2021-03-05:
Hi, I just tried running 1941 on mister with hdmi and the picture is upside down,
the "rotate screen" is enable, if disabled the image is rotate 45° as expected I guess.
Am I doing something wrong :'( ?

jotego, 2021-03-06:
Go into the OSD menu, the DIP switches, then select flip and reboot.

r4dius, 2021-03-06:
My bad, thanks :)

Closed 2021-03-06.

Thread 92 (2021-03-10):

cps 1.5 3º player

leosmendes, 2021-03-10:
the core of cps1.5 working normally for 3 players? I ask why I can't get any buttons on "cadlac and dinosaurs" I managed to use 3 controls smoothly on the gauntlet core. I activated in the configuration part of the game 3 payers too. I can't get any response in the core of cps 1.5 from the third controller, even though I mapped it and activated it too

jotego, 2021-03-11:
Hello, there is a problem with the third player input. I have already spent a couple of sessions debugging it but haven't found the culprit yet.
I am taking this problem here

https://github.com/jotego/jtbin/issues/148

So I will close this thread. Thank you for reporting it. I will continue chasing this issue.

Closed 2021-03-11.

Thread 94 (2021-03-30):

Willow - Dip switches does not work properly

thehughhefner, 2021-03-30:
Hi,
I was playing through willow (world) and I've noticed that the dip switches are broken. Toggling one dip switch can affect other dip switches. For example, when increasing health, it can turn off other things.

Also, the level dip switch doesn't work either, setting it to level 6 won't take me to that level.

atrac17, 2021-08-04:
These are the proper dips for Willow. Those others come from mame. Try placing this in your mra for [willow] primary mra.

```
    <switches base="23" default="3f,1f,de">
        <!-- DSWA -->
        <dip name="Coin A" bits="0,2" ids="2/1,4/1,3/1,2/1,1/4,1/3,1/2,1/1"/>
        <dip name="Coin B" bits="3,5" ids="2/1,4/1,3/1,2/1,1/4,1/3,1/2,1/1"/>
        <dip name="Cabinet" bits="6" ids="Upright 2 Players,Upright 1 Player"/>
        <!-- DSWB -->
        <dip name="Difficulty" bits="8,10" ids="8,7,6,5,1,2,3,4"/>
        <dip name="Nando Speed" bits="11,12" ids="Very Fast,Fast,Slow,Normal"/>
        <dip name="Power Ups" bits="15" ids="On,Off"/>
        <!-- DSWC -->
        <dip name="Lives" bits="16,17" ids="4,3,1,2"/>
        <dip name="Vitality" bits="18,19" ids="2,5,4,3"/>
        <dip name="Flip Screen" bits="20" ids="On,Off"/>
        <dip name="Demo Sounds" bits="21" ids="Off,On"/>
        <dip name="Allow Continue" bits="22" ids="No,Yes"/>
        <dip name="Game Mode" bits="23" ids="Test,Game"/>
    </switches>
```

jotego, 2021-11-21:
I have copied the DIP switch list provided by Atract17 to the MRA files.
The confusion came because Willow DIP switches have a different meaning if you turn on the service mode while playing -and don't reset the game. But there is no way right now to show an alternative DIP switch menu in MiSTer. So we have to delete the cheat options provided in this other mode.

Closed 2021-11-21.

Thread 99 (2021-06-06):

In "Muscle Bomber Duo Ultimate Team Battle" 3rd and 4th players can't jump

13r, 2021-06-06:
I mapped several gamepads but always the 3rd and 4th player have the "jump" button inoperative. In the OSD i can map the button fine in every pad, but in the game it doesn't work. I even switched gamepads and it happen always with the 3rd and 4th player.

I tried other CPS and CPS 2 games of 3 and 4 players where they use 3 or more buttons and they seem to work fine (for example "Dungeon and Dragons Tower of Doom"). This seems to be the only game with this problem for me.

jotego, 2021-06-08:
That's indeed the case. Let me look into it.

13r, 2021-06-08:
Ok, thanks for confirming it (i was a little paranoid about some kind of configuration issue on my mister). Take all the time you need ;).

jotego, 2021-06-09:
Fixed in f6c327f
Run the updater to get the file

Closed 2021-06-09.

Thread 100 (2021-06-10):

SF2WW Blanka headbutt bug sound

mikey1964, 2021-06-10:
play as guile get to blanka stage block everything at some  point blanka will try to headbutt you and will do it 2 times in a row and each time the dying sound plays not sure if this happens in a real arcade board  .  also not sure if this is normal on a real arcade cps1 board as the plane moves the portraits flicker sometimes . the sf2ww arcade game seems to have alot of flicker when the speed increases hard to tell what is legit hardware bugs and what is a bug in the mister core not sure if other arcade revisions fix theses problems

mikey1964, 2021-06-10:
here is a video https://gofile.io/d/RMOFbA

jotego, 2021-06-11:
Hi,

I think your RBF may be a bad one. I made a bad update last week and had to delete it. The problem we fave is that the updater doesn't delete files, only updates. So I think you will have to manually delete the core.

I am preparing changes to the update approach to prevent these situations but it will still take a while until we have them ready. A first step will be announced today.

Thank you for reporting it.

mikey1964, 2021-06-11:
ok i will delete the RBF by hand and then let the update download it again. i  will test again and let you know if it made a difference

mikey1964, 2021-06-11:
i remove files manually   jtcps1_20210604.rbf - size 2.87 MB (3,013,356 bytes)
                                        jtcps15_20210604.rbf - size 2.91 MB (3,059,688 bytes)
is there anything else i need to remove. update install these files
jtcps1_20210604.rbf - 2.87 MB (3,013,356 bytes)
jtcps15_20210604.rbf - 2.91 MB (3,059,688 bytes)

 it made no difference
i got blanka to do the headbutt 3 times, in one set i got elephant sounds other 2 sets the sound had distortion and sound drop got like a robot like sound.

mikey1964, 2021-12-23:
so iam guessing you fix this JT? i let blanka do his headbutt  i see nothing change still getting different sounds

jotego, 2021-12-23:
Let me check again

mikey1964, 2021-12-23:
which rbf are you using

mikey1964, 2021-12-23:
iam using jtcps1_20211217

jotego, 2022-04-17:
I think this is probably a bug in the original. I'll close it until new evidence pops up.

mikey1964, 2022-06-14:
i have not been able to find a arcade machine to test this out but atleast i can confirm this happens in mame  also so its not my de10 or bad files . if i find a arcade machine i will let you know if it does the same thing

Closed 2022-04-17.

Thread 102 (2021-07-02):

CPS 2 : Powered Gear Strategic Variant Armor Equipment (Japan 941024) - Graphical issues

wwark, 2021-07-02:
You will see glitches on the screenshot below - produce with the 1st public release version.
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
Thanks,

wwark, 2022-01-07:
normally fixed by https://github.com/jotego/jtcps1/issues/119

jotego, 2022-01-07:
Yes, it is fixed now :-)

Closed 2022-01-07.

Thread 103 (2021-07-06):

CPS1: Street Fighter II' Hyper Fighting -World 921209-.mra - Pause and Coin always mapped to R / L buttons regardless of configuration change

jdalmanza, 2021-07-06:
I can change the button mappings manually within the interface but no matter what I assign to L and R they always function as Coin and Pause.

In my case I am using a SNES style gamepad. I can map all os the 6 input buttons to the buttons I want but L and R are always Coin and Pause. this is the only game that exhibits this behavior of the roms that I have tried on both CPS1 and CPS2 cores, I can freely map and replace coin and pause on just about every other rom, just not on SF2:HF

jotego, 2021-07-06:
Try going through the controller setup in the main MiSTer menu first (before loading the core)

jdalmanza, 2021-07-12:
I tried a different controller, HORI PS3 fighting pad and did not see the issue I described. Then, I took your advice and re-mapped the original SNES style controller and after that I did not see the issue anymore on this or any of the other ROMs.

Closed 2021-07-12.

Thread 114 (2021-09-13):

CPS2 - eco fighter - missing foreground layer

Spacejockey-GH, 2021-09-13:
En la pantalla 5 faltan todas las columnas verticales que deberian aparecer en primer plano no son dibujadas:

 Core del 20210828:
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

Captura de MAME###

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

Si mal no recuerdo esto se veía bien en versiones previas del core (Antes del fichero beta.zip)

jotego, 2022-01-07:
Fixed in b23bbae

Closed 2022-01-07.

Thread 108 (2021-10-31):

CPS-2 - Darkstalkers: The Night Warriors - Graphics Glitching

M-Walrus, 2021-10-31:
Elements of backgrounds, UI and character sprites all exhibit glitchy behavior when playing through the game.  These glitches happen for a frame and all elements have similar behavior where a block will be missing or misplaced.  This can be difficult to observe because of how briefly it flashes, but I have seen it occur on multiple stages while playing the game.  Does not seem to effect the intro, character select, or transitions between rounds.

CPS-2 core version where this is observed: 20211024
Game version/MRA: Darkstalkers The Night Warriors (Euro 940705)

In the attached screenshot you can see it in the top-left corner where part of the UI is missing for a frame, which should be overlaid on top of the character artwork and framing it fully, but instead is missing the bottom half.
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

Another example of glitching UI element is timestamped here in my recent video for the core/game. Look a couple seconds past where this starts when "3 HIT COMBO" comes on the screen.  The I in HIT flickers out and then part of the word COMBO disappears with the B getting moved next to the T in HIT:
https://youtu.be/ouYL4MP_wNE?t=679

thehughhefner, 2021-10-31:
The Night Warriors is full of visual glitches.

This happens on real hardware as well.

jotego, 2021-11-01:
Another example copied from Discord:
https://youtu.be/ouYL4MP_wNE?t=657

> You can see a large chunk of the background go missing on the right side for a frame, and part of it appears below Victor as he is falling: then if you go frame by frame as Victor his hitting the floor afterwards, you can see most of Rikuo's portrait by his life bar disappear
a few frames later if you observe Victor while he is bouncing off the ground, you can see large portions of his character sprite missing also
I noticed the player character sprites on multiple stages doing this, with large chunks missing from them for a frame.
same for background art on various stages

Still not sure whether this is genuine or a core problem. It is not so easy to spot it as it happens for a split second

M-Walrus, 2021-11-03:
Some videos were posted on discord from original CPS2 hardware with a darksoft multi, and the observations I made from those are:

turbo1:
-clean. no UI, character sprite or background issues.  MiSTer core seems to match this perfectly.

turbo2:
-frequent UI corruption including character portraits flickering out for a frame.
-some background corruption. foreground light pole on jon talbain stage was most notable. no background objects randomly moving around the stage as was observed on MiSTer.
-minimal/no character sprite corruption (saw a single line on demitri for a frame, but thats it- no large chunks)

turbo3:
-definite character sprite corruption. half of demitri's sprite was missing for a frame during jon talbain fight.

so currently the only things in question in the MiSTer CPS2 core compared to what I've seen in the real hardware videos are:

-a regular occurrence of character sprites missing chunks

-stage objects moving to different places on the screen for a frame.  In my video linked above you can see the lightpole in the foreground on jon talbain's stage move to a different spot on the screen for a frame just like the background machinery did on Victor's stage.

thehughhefner, 2021-11-03:
This could be due to two things
- There are variations between real hardware. As mentioned before, Darkstalkers is in general a visual buggy game.
- DMA timing needs to be adjusted.  Didn't the mapping of the CPS-A confirm it was correct?

M-Walrus, 2021-11-03:
This may be coincidence, but the three instances where I've noted screen objects being drawn in the incorrect location for a frame, have always been shifted to the left on the screen.
The "3 HIT COMBO" text where the B was shifted to the left against the T, machinery on Victor's stage appeared on the ground (far) to the left of its original position, and the light pole on Jon Talbain's stage also moved to the left from its original position.

We have only seen a 5 minute video of Turbo 2 on original CPS-2 hardware so far, so I think a longer video would help to be certain here.

thehughhefner, 2021-11-03:
I'm starting to think more about what you are seeing @M-Walrus is also in real hardware. Darkstalkers is one of many where there are absolute random visual glitches that appear on screen for a frame. Also, it is very very hard to compare real hardware vs "emulator" since lots of things going on at the same time. Its a fighting game after all.

M-Walrus, 2022-04-02:
Closing this.  Last tests suggested it possibly occurred more frequently on the core than on a real PCB, but I have no way to verify this and do not want to have this report lingering around any longer. Possibly someone who especially likes this one can verify it closely to the original PCB performance at a later point.

Closed 2022-04-02.

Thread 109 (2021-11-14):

CPS2- Dungeons & Dragons Tower of Doom - odd text highlight effect in service mode

Jimi369, 2021-11-14:
When in service mode on D&D-Tower of Doom on the CPS2 core  the highlighted text seems to be slightly corrupted. At least it is different from other service modes on the cps2 core.

I’ve looked on youtube for a video to compare but found no example. So it may be normal but I can’t tell.
Tested on two different Mister builds with the latest updates (as of november 13th)

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

jotego, 2021-11-14:
It isn't consistent across games so I think it's correct but I'll leave the issue open in case new information arises.

Closed 2021-12-22.

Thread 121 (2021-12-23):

Rogue line on SSF2 player select screen

sqwirral, 2021-12-23:
Issue appeared in **jtcps2_20211217**, previous version is okay.
Tested with Super Street Fighter II The New Challengers (World 931005).mra

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

jotego, 2022-01-07:
I this in fine in version b23bbae
That's 7th Jan. 2022
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

Closed 2022-01-07.

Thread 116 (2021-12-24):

CPS2 - Alien Vs. Predator - Graphics glitch

M-Walrus, 2021-12-24:
Round 7 has a graphics issue with a foreground door frame (about 2 minutes into the stage), as seen timestamped here:

https://youtu.be/Oo8bmBKDlFg?t=2174

Colors on the foreground section of door become two-tone and the priority shifts so it becomes a background object, making it look like players are walking on top of it.

Version tested is Euro region release, 10-24-21 core build on MiSTer FPGA

atrac17, 2022-03-20:
This may be due to overdump of GFX roms @jotego. I'll upload new MRA's here to test with the latest rom dump from mame.

jotego, 2022-04-20:
As this is a problem with the ROM dumps and not with the core, I will close it here.

M-Walrus, 2022-05-11:
> As this is a problem with the ROM dumps and not with the core, I will close it here.

This was never confirmed @jotego. Do you have any further information about these bad rom dumps?  I am pulling from the most recent MAME set, verified.  Folks with ROM dumping capability should know if there is possibly no good dump of this game, if this is indeed the issue.

All we have in this issue report is a random person saying it *may* be due to some issue and they would test something, but no follow-up.

atrac17, 2022-05-11:
You've used this specific ROM? Made an MRA to load this over dumped GFX bank?

[cps2.cpp: corrected some overdumps for avsp - Guru](https://github.com/mamedev/mame/commit/163659b50aabc57aaeeb55e35e88d85523cdbc4c)

When @theypsilon has the new distribution for ROM fetching available, I'll replace the MRA.

I'm not some random person. Since you did the above, you know that when you looked at the MRA, I'm one of the authors. This was discussed off of GitHub because it effects every single MiSTerFPGA user.

atrac17, 2022-05-12:
Core and hardware. Thanks tester nobody!

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

https://youtu.be/oA_aBrCciFI?t=2520

Closed 2022-04-20.

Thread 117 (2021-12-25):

CPS2: Sprite gaps (Multiple games)

lsnderick, 2021-12-25:
Recently I noticed there seems to visible "gaps" between some elements of the larger sprites. During the screen transitions those sprites seem to move out of sync with the rest of the image. So far I've seen this is in Vampire Savior 2 The Lord of Vampire (Intro), Vampire Hunter 2 Darkstalkers Revenge (Intro), Marvel Super Heroes (One of the stage background layers). Some screenshots:

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

jotego, 2021-12-25:
I think this is new. Maybe I broke something in an update. I don't remember seeing this problem before.

jotego, 2021-12-25:
The problem was introduced in commit 0fdcb02

jotego, 2021-12-25:
Fixed in c67b7e7

Closed 2021-12-25.

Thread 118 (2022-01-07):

CPS2: Mars Matrix music sounds too low + sound effects only on the left channel

thehughhefner, 2022-01-07:
Hi,
Mars Matrix music sounds too low compared to other CPS2 games. I don't have the original board to compare, however, compared to other games on the same hardware it's low.

Also, the sound effects (shooting) seem only to appear on the left channel.

jotego, 2022-04-20:
All CPS2 games share the same sound subsystem as far as I know. The game must have been programmed to be quiet. Feeling the sound to come only from one source may be due to the spatial nature of Q-Sound, you may try moving a bit. I can hear the shooting sound from both speakers if I move close to them.

Closed 2022-04-20.

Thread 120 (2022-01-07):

Eco Fighters: tall objects not drawn

jotego, 2022-01-07:
Scenes were a top to bottom element in the object layer is used, fail do draw it.

During the attract mode:

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

The wooden pilar is missing. It should look like:

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

This issue comes from [JTALPHA](https://github.com/JTFPGA/jtalpha/issues/85).

jotego, 2022-01-07:
Fixed in b23bbae

Closed 2022-01-07.

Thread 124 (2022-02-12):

Ssf2

jotego, 2022-02-12:
From Discord

in ssf2 in ken stage when you win a line flickers on the bottom of the boat as is moving up and down when you win on the score count. i  dont think this happens in real hardware can somebody check if it does happen there

mikey1964, 2022-02-12:
might be normal

https://user-images.githubusercontent.com/56406421/153706640-32b3d04e-c95b-4007-8a05-cf230e2b0ec1.mp4

jotego, 2022-04-20:
I think this is genuine then. I'll close the issue. Thanks for the video.

Closed 2022-04-20.

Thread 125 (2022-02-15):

Core suddenly rebooting - X-Men vs. Street Fighter

luciusbono, 2022-02-15:
I'm trying to chase down an intermittent issue with X-Men vs. Street Fighter where the core will suddenly reboot. It doesn't happen every session, but does happen _most_ sessions around 3 rounds into the game.

I recognize this is super vague, but I'm new to the MiSTer platform and haven't been able to locate any logs that may be helpful - and it's not consistent enough where I've been able to find any specific trigger conditions. Only the core reboots (screen freezes and the core boot sequence occurs). I have only noticed this on X-Men vs. Street Fighter but it's the ROM/core I play the most.

Running the latest version of the core / MiSTer from `update_all`. MiSTer is using a high quality power supply / is well cooled (it's using the MiSTer Multisystem daughterboard). Input device is an 8BitDo Arcade Stick.

Any guidance you could provide to help produce a better problem report would be greatly appreciated - certainly not expecting answers with this vague of a problem report!

jotego, 2022-02-15:
Thank you for your kind report.
This could be related to #110. Can you try playing with the Phoenix ROM version? That version doesn't use encryption and if worked, it would point to the problem.

luciusbono, 2022-02-22:
Sorry for the long delay, I was traveling last week and didn't have enough time to test the Phoenix ROM.
Testing with the USA Phoenix ROM for about two hours has yielded _zero_ resets so I suspect your hunch about encryption being the problem is correct.

Is there any other testing I can do to help?

jotego, 2022-02-22:
Thank you very much. This is precious information. I'll try to spend some time on it this week.

venalaine, 2022-02-25:
I can also confirm this issue. I have been playing this game during past couple of days and sometimes the game just reboots. It seems that the issue is not related to certain level or anything. Sometimes it happens after 5 min of playing, sometimes after 30 minutes or something.

ibrahima-whatever, 2022-05-07:
Hi,

This happens fairly regularly in single player. Steps to reproduce below:

1. Pick a team that includes Akuma / Gouki. He can be selected by moving up from Magneto or another character on the top row.

2. In a match, use Akuma’s super; Raging Demon / Shun Goku Satsu against the CPU when one of their characters is on relatively low life (eg less than a third or so). This super can be used by pressing ‘jab, jab, direction forward, short, fierce’. If you are successful Akuma will trigger a super animation where he slowly floats towards the opponent, then grabs them with a white screen flash. Another description for the input depending on preference is ‘light punch, light punch, forward, light kick, heavy punch’. You may need to practice this move to get used to the input

3.  If you have been successful the following things should happen:
* Akuma defeats the CPU opponent with the super
* The CPU tag partner character jumps onto the screen after the white flash and the super combo has completed
* The game resets when the CPU tag partner attempts to attack

Please note that this happens between 50-70% of the time when playing against the CPU. In some cases it is possible that the game will not reset even when you have input the super correctly and defeated the first CPU opponent.

I have noticed that a similar crash also occurs in Marvel Super Heroes using the hidden character Anita when playing against a CPU controlled Shuma Gorath on their stage.

If needed I can do a recording of the Akuma crash. Please let me know if that would be useful.

ibrahima-whatever, 2022-05-07:
Just noted re: Phoenix set. I will try and replicate it on that set over today and let you know how I get on.

jotego, 2022-05-08:
Thank you. Please let us know if the Phoenix set is ok. I tried a few things about this on the related issue #110 but I couldn't fix it. I will try a different approach this week to find the root cause.

ibrahima-whatever, 2022-05-08:
Retested on the Phoenix USA 961004 rom. No crash. Played through arcade mode and landed the super roughly five or six times to KO cpu opponent. Game continued as normal.

Out of interest I retested on the standard USA 961004 rom. No crash. Tried to reproduce several times.

Retested on the Euro 961004 rom. Crash. This was reproduced several times.

Retested on the Euro 960910 rom. No crash.

So at this point can’t guarantee that the Phoenix rom includes a change that prevents this particular crash on Xmen Vs Street Fighter when ko’ing a CPU player with Raging Demon, though I understand that this has prevented crashes on other romsets in similar situation (eg the old deejay crash on ST).

I would assume that outside of the region code and related changes the two 961004 romsets are identical, but again I could understand if that isn’t the case for whatever reason (eg change in how the cpu controlled character behaves, or changes to game logic or similar).

In the interest of narrowing this down might be worthwhile to note that I typically play with in-game turbo setting enabled (eg ‘normal’ or ‘turbo’ on character select screen). I usually pick Akuma as first character but have also seen this happen when he is secondary. I have been able to reproduce this when he is partnered with Ryu or Magneto, so again tag partner doesn’t seem to impact this.

jotego, 2022-07-03:
This is most likely fixed in bf5a34e. Please reopen it if it still happens (wait until the updated core is published on the 8th July 2022)

luciusbono, 2022-07-03:
Amazing! Thank you so much.

Closed 2022-07-03.

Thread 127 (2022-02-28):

No jump button on Strider on the default configuration

pepie34, 2022-02-28:
No button is configured to do a jump by default on Strider.
(No jump appears in the short osd popup help, and no button actually do the jump)
You need to do at least a remap on the core menu to enable a jump button.

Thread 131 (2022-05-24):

cps1 - 3 Wonders - intro glitch

barbudreadmon, 2022-05-24:
Seen on a friend's mister last week, i don't own one.

See pcb video at https://www.youtube.com/watch?v=UiJeLfruoh4&t=71s , the gun isn't supposed to be cut but it's cut on mister.

atrac17, 2022-06-19:
Reference #132

Last working build is [20211206](https://github.com/jotego/jtbin/blob/master/mister/cps1/releases/jtcps1_20211206.rbf) (JTCPS1 v9f4b585).

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

Current build is [20220601](https://github.com/jotego/jtbin/blob/master/mister/cps1/releases/jtcps1_20220601.rbf) (JTCPS1 v40add73).

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

jotego, 2022-06-25:
Thanks @barbudreadmon for the PCB video.
Thanks @atrac17 for providing the history information. I've reverted the compromising change in edd0cb9. This fixes this issue but reopens #40.

Closed 2022-06-25.

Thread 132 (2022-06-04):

Final Fight: check layer alignment

jotego, 2022-06-04:
Check whether this is correct

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

atrac17, 2022-06-19:
The priority issues are present in other CPS1 titles. Final Fight is not the only title effected. I was able to trace this back to the last known working build.

Last working build is [20211206](https://github.com/jotego/jtbin/blob/master/mister/cps1/releases/jtcps1_20211206.rbf) (JTCPS1 v9f4b585).

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

Current build is [20220601](https://github.com/jotego/jtbin/blob/master/mister/cps1/releases/jtcps1_20220601.rbf) (JTCPS1 v40add73).

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

Traced back to the following commits:

[4cef041](https://github.com/jotego/jtcps/commit/4cef041467b0fea679848870385c073a28a18d8f)
[0fdcb02](https://github.com/jotego/jtcps/commit/0fdcb021b95a30dc7bf548203660dcb2f20e56e7)

jotego, 2022-06-25:
Thanks @atrac17 for providing the history information. I've reverted the compromising change in edd0cb9. This fixes this issue but reopens #40.

Closed 2022-06-25.

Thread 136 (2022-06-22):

Can't Define Coin/Start

ZeroAlucard27, 2022-06-22:
This issue is only on the Capcom fighting games, for some reason.

I can (seemingly) define my buttons, but when I finish the process, the coin and start buttons don't work.

This has happened with multiple controllers (two fight sticks and a keyboard), and I did save my settings.

Closed 2022-06-22.

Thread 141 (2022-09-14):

wrong sound in king of dragon and captain commando

titorin0, 2022-09-14:
In the first stage of captain commando the cymbals are perceived very strident.
they are not corrected by touching the filters.

the same goes for the king of dragon in stage 4 .
becoming unpleasant
https://youtube.com/clip/UgkxhsKSqb7QJffJFQkWv4YaObqXCOb_Gsxo
real pcb kod: https://youtube.com/clip/Ugkx30RhvkV-J4ZiMGVQeUj8xLZeA2Rg3CZ3

https://youtube.com/clip/UgkxO7wt1Am9h_BWJhiZ_K9NUSGeHzs6rsx1
real captain pcb: https://youtube.com/clip/Ugkx5FEH_Dr24ocC1RRvmCN5CZdFSEakpOx9

TesterNes, 2022-11-12:
That Captain Commando's video is not from a real pcb but MAME32Plus!Plus!0.116u3
This is from a real one: https://www.youtube.com/watch?v=0o9Utr5rjFQ
Anyway, this is related to https://github.com/jotego/jtcps/issues/145

jotego, 2022-11-21:
Close as duplicated. We will track it in #145

Closed 2022-11-21.

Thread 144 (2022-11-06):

Puzzloop2/CPS2 Spinner support

eedomus, 2022-11-06:
By Default, Puzzloop is configured to be played with a joystick.

But you can enable spinner control going to "Test Menu / Configuration / Operation"

Playing this game with a spinner is a nice added value on the gameplay 🥰

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

jotego, 2023-01-15:
The spinner logic is currently not connected to the CPU. Apparently, there are two games using the spinner and the hardware is slightly different.

To do:

- [ ] connect spinner to JTCPS2
- [ ] Eco Fighters mode
- [ ] Puzz Loop 2 mode

capitaineflam25, 2023-01-16:
Thanks for the explanation 👍🏻

jotego, 2023-01-18:
Completed on e1c67c9
To be released this Friday

Closed 2023-01-18.

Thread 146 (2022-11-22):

Speed increase with SF2 Hyper Fighting

sqwirral, 2022-11-22:
The speed of SF2HF seems to have been changing between releases.

It was pretty good back in 20210131. Here's a video by fluxcore comparing 20210131 to real hardware:
https://www.youtube.com/watch?v=2nJiMnxXYVA

Here is a video (posted by Ohmi) comparing the current 20220819 to a real HF board, and the core runs too fast:
https://drive.google.com/file/d/1FNYcXS0yum-oKHpksb2RO4Xx8hH1cAg5/view?usp=share_link

I tested a lot of RBF's (using Street Fighter II'  Hyper Fighting -World 921209-.mra) and found the speed has changed a lot in both directions between versions. Here's a video with 15 synced together:
https://www.youtube.com/watch?v=kW-OaRdK7IU

It may be easier to visualise the changes when looking at the end times of the above video:
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

(Note, I also tested the same versions a second time, to make sure it wasn't giving totally different results each run. While not frame-exact, they were very close when sticking to the same version, so I don't think that's a problem.)

jotego, 2022-12-16:
Some changes in how the /DTACK signal is handled have affected the core performance over time. This is a collection of the different values recorded using _SF2 DMA no b3.mra_ These tests measure the CPU speed under different DMA settings. In this table I am just comparing the default value. Note that the numbers are in hexadecimal.

Version         | commit  | Speed     | JTFRAME
----------------|---------|-----------|-------------------------
Original PCB    |  N/A    |  2C00     |
20210131        |         |  2C04     |
20210604        |         |  2C0A     |
20210828        |         |  2C0B     |
20210921        |         |**357C**   |
20211002        |         |  357C     |
20211024        |         |  357C     |
20220112        |         |  3584     |
20220321        |         |  3584     |
20220417        |         |**2BF9**   |
20220422        |         |  2BF9     |
20220427        |         |  2BF9     |
20220601        |         |  2BF9     |
20220627        |         |  2BF9     |
20220704        |         |  2BF9     |
20220705        | 61626fc |  2BF9     |  bd7cf34
20220819        | b78bdae |**3576**   |  a108a4a

The immediate action is to [delete version 20220819](https://github.com/jotego/jtbin/commit/7059c052a419959bf5c3fdd335b4b7bfc7c10126). I keep the issue open until the source code incorporates the fix.

jotego, 2022-12-22:
- The changes in the jtframe_68kdtack module in [JTFRAME](https://github.com/jotego/jtframe/commit/fa2d6a1a78d3d41b57ae12030c54f8096d01d8b0)  caused the speed increase
- Fixed in bd63249

Closed 2022-12-22.

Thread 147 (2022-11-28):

CPS3 schematics

jotego, 2022-11-28:
This issue covers the work that can be done without cracking open the custom chips

- [x] Create core in the JTCPS repository and add JTKICAD
- [x] Schematic for the memory modules
- [x] Symbols for custom chips -temptative names-
- [x] First schematic draft

etriana85, 2022-11-28:
I'm working on it

Closed 2023-02-03.

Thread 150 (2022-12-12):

CPS3 Custom chips

jotego, 2022-12-12:
Obtain die pictures of the custom chips

- [ ] Obtain disposable custom chips
- [ ] Desolder
- [ ] Decap
- [ ] Die pictures
- [ ] Upload and share with interested developers

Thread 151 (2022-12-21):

Create new MRA files for CPS1 games

jotego, 2022-12-21:
JTCPS1 was the first core to extract information from MAME in order to create the MRA files. Since then JTFRAME has advanced a long way to make this a standard step of core development. JTCPS1 MRA files are not well supported now as they are not covered by the new workflow and they have had merges in JTBIN.

**Missing MRA features**
- Button names
- _ccw_ annotations for vertical games

**Tasks**
- [ ] Export the header section of current MRA files into a new _mame2mra.toml_ file
- [ ] Add button names
- [ ] Correct DIP switch names
- [ ] Add flow for custom MRA files
- [ ] Keep MRA files for DMA speed tests

Toryalai1, 2022-12-21:
This might be helpful:
https://github.com/jotego/jtbin/pull/298

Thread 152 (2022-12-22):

Freezes on MiSTer

jotego, 2022-12-22:
Latest known commit to work: b78bdae
Broken commit: _before_ 8ffa364

- In MiSTer, games halt after the test screen, which passes ok. The DMA test rom has corrupted graphics
- In MiST, games work normally

jotego, 2022-12-22:
Fixed in f0c96fc

Closed 2022-12-22.

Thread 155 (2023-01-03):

Add ability to change sensativity and rotation speed of Forgotten Worlds analog rotation like in mame

konradpop, 2023-01-03:
due to various rotary joystick interfaces the response on the rotation can be slow with this game, mame has a feature for analog rotary sensitivity and speed so that the character can spin faster or slower etc. Is this possible in this, Using DaemonBite joystick with rotary interface + LS30 joysticks, the default rotation speed is too slow in the game.

jotego, 2023-01-16:
Completed in 968dfba
- Added OSD option with 4 speeds for rotation
- Rotation is mapped to two joystick buttons
- Rotation can be controlled with a spinner
I will update the version in JTBIN on Friday

Closed 2023-01-16.

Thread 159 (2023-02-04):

Adding high score saving

theenemy-thd, 2023-02-04:
Are there any plans to add high score saving at all, It would obviously be great on all your cores to have highs saved.

jotego, 2023-02-05:
Yes, a lot of ground work has already been done in the last two months to pave the road to hi-score saving.
If you check the repository logs, the modifications done to add a file called mem.yaml to many cores is related to this.
I cannot commit to a specific date for this change but it's coming.
Let me close this issue as I think this task was already captured in a different one.

Closed 2023-02-05.

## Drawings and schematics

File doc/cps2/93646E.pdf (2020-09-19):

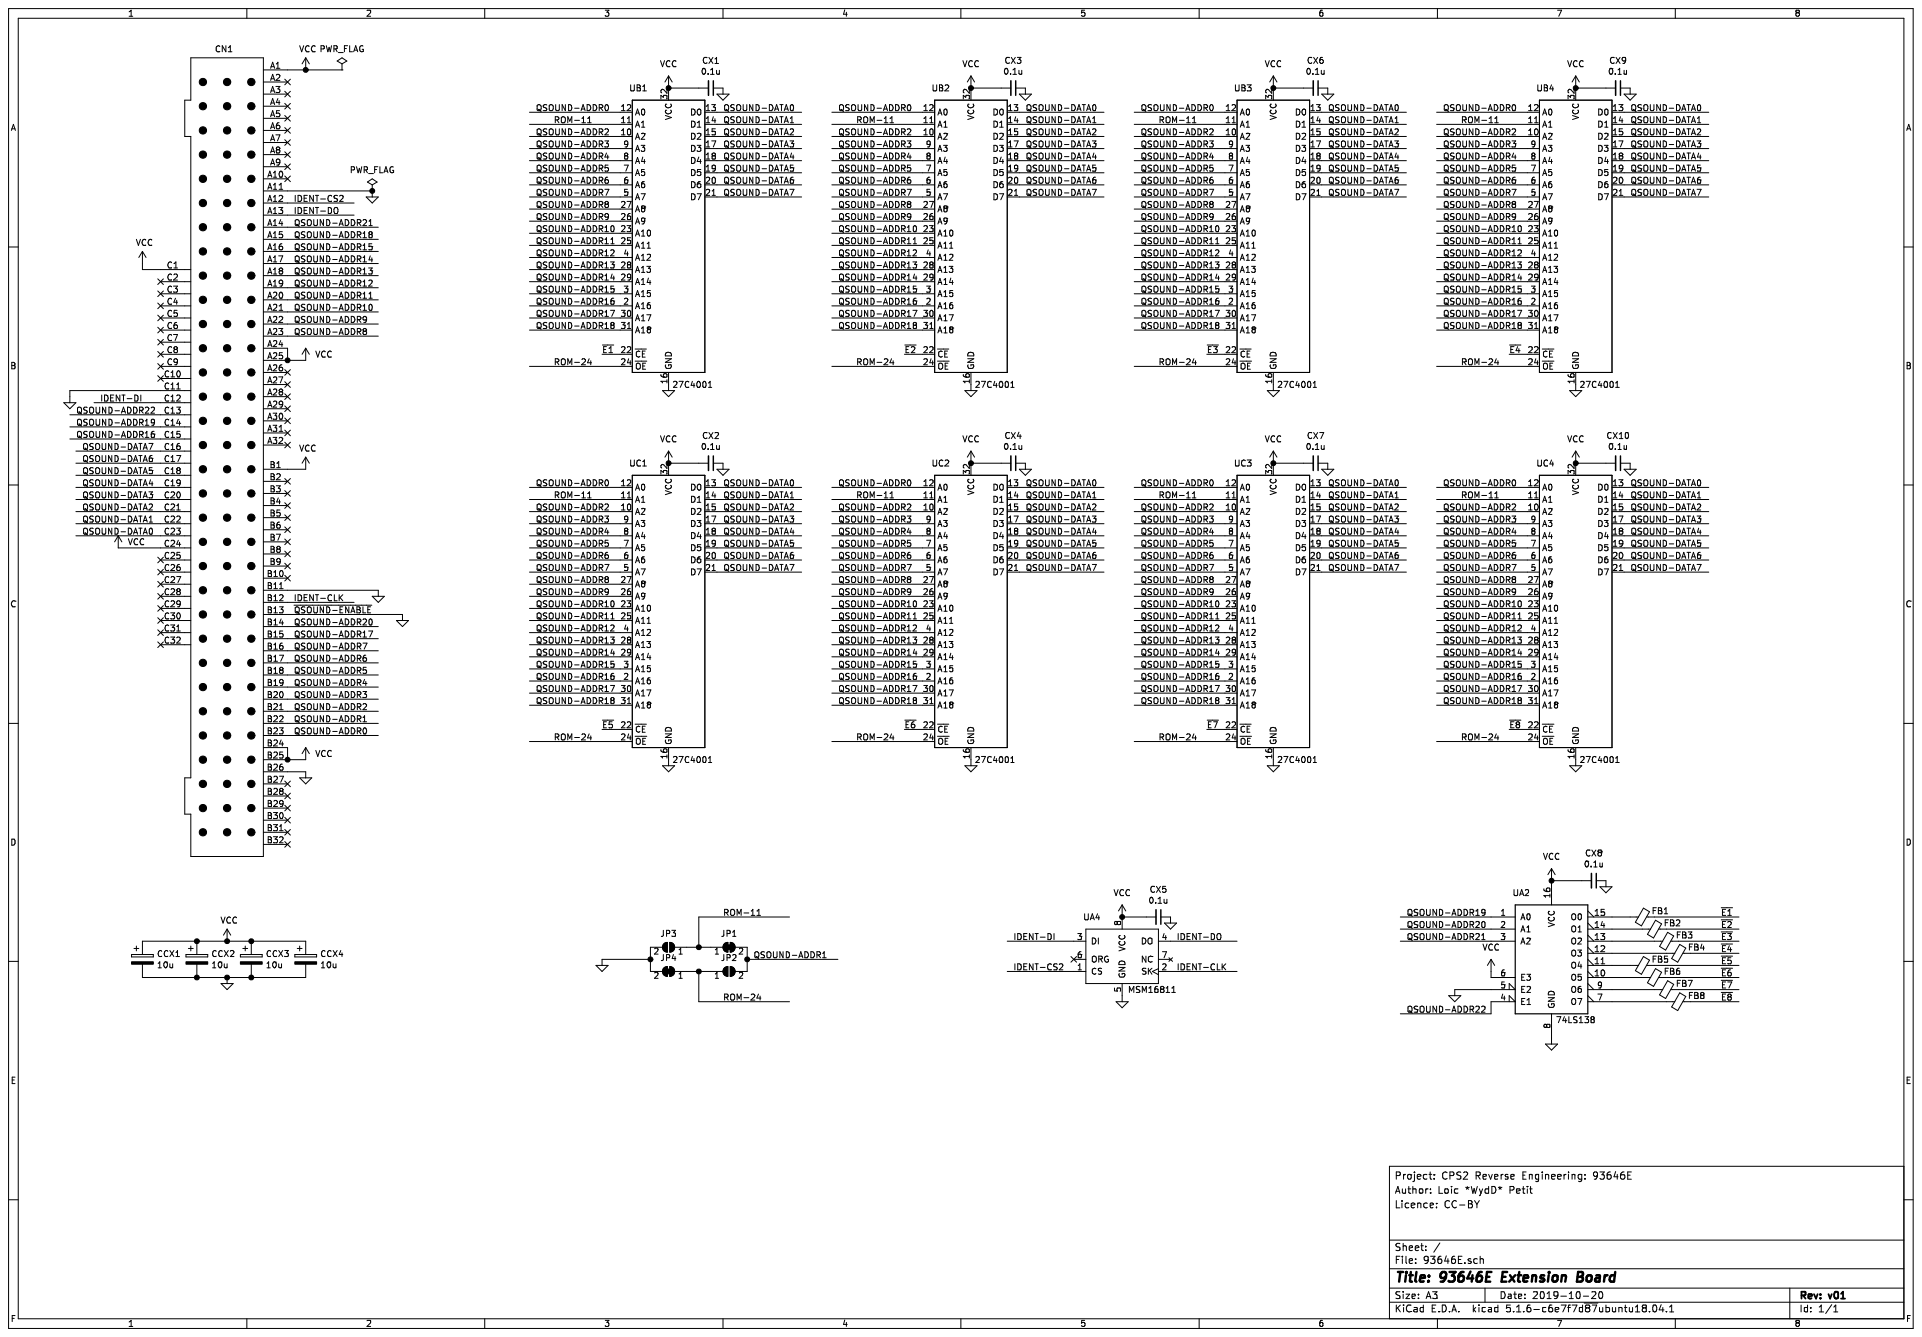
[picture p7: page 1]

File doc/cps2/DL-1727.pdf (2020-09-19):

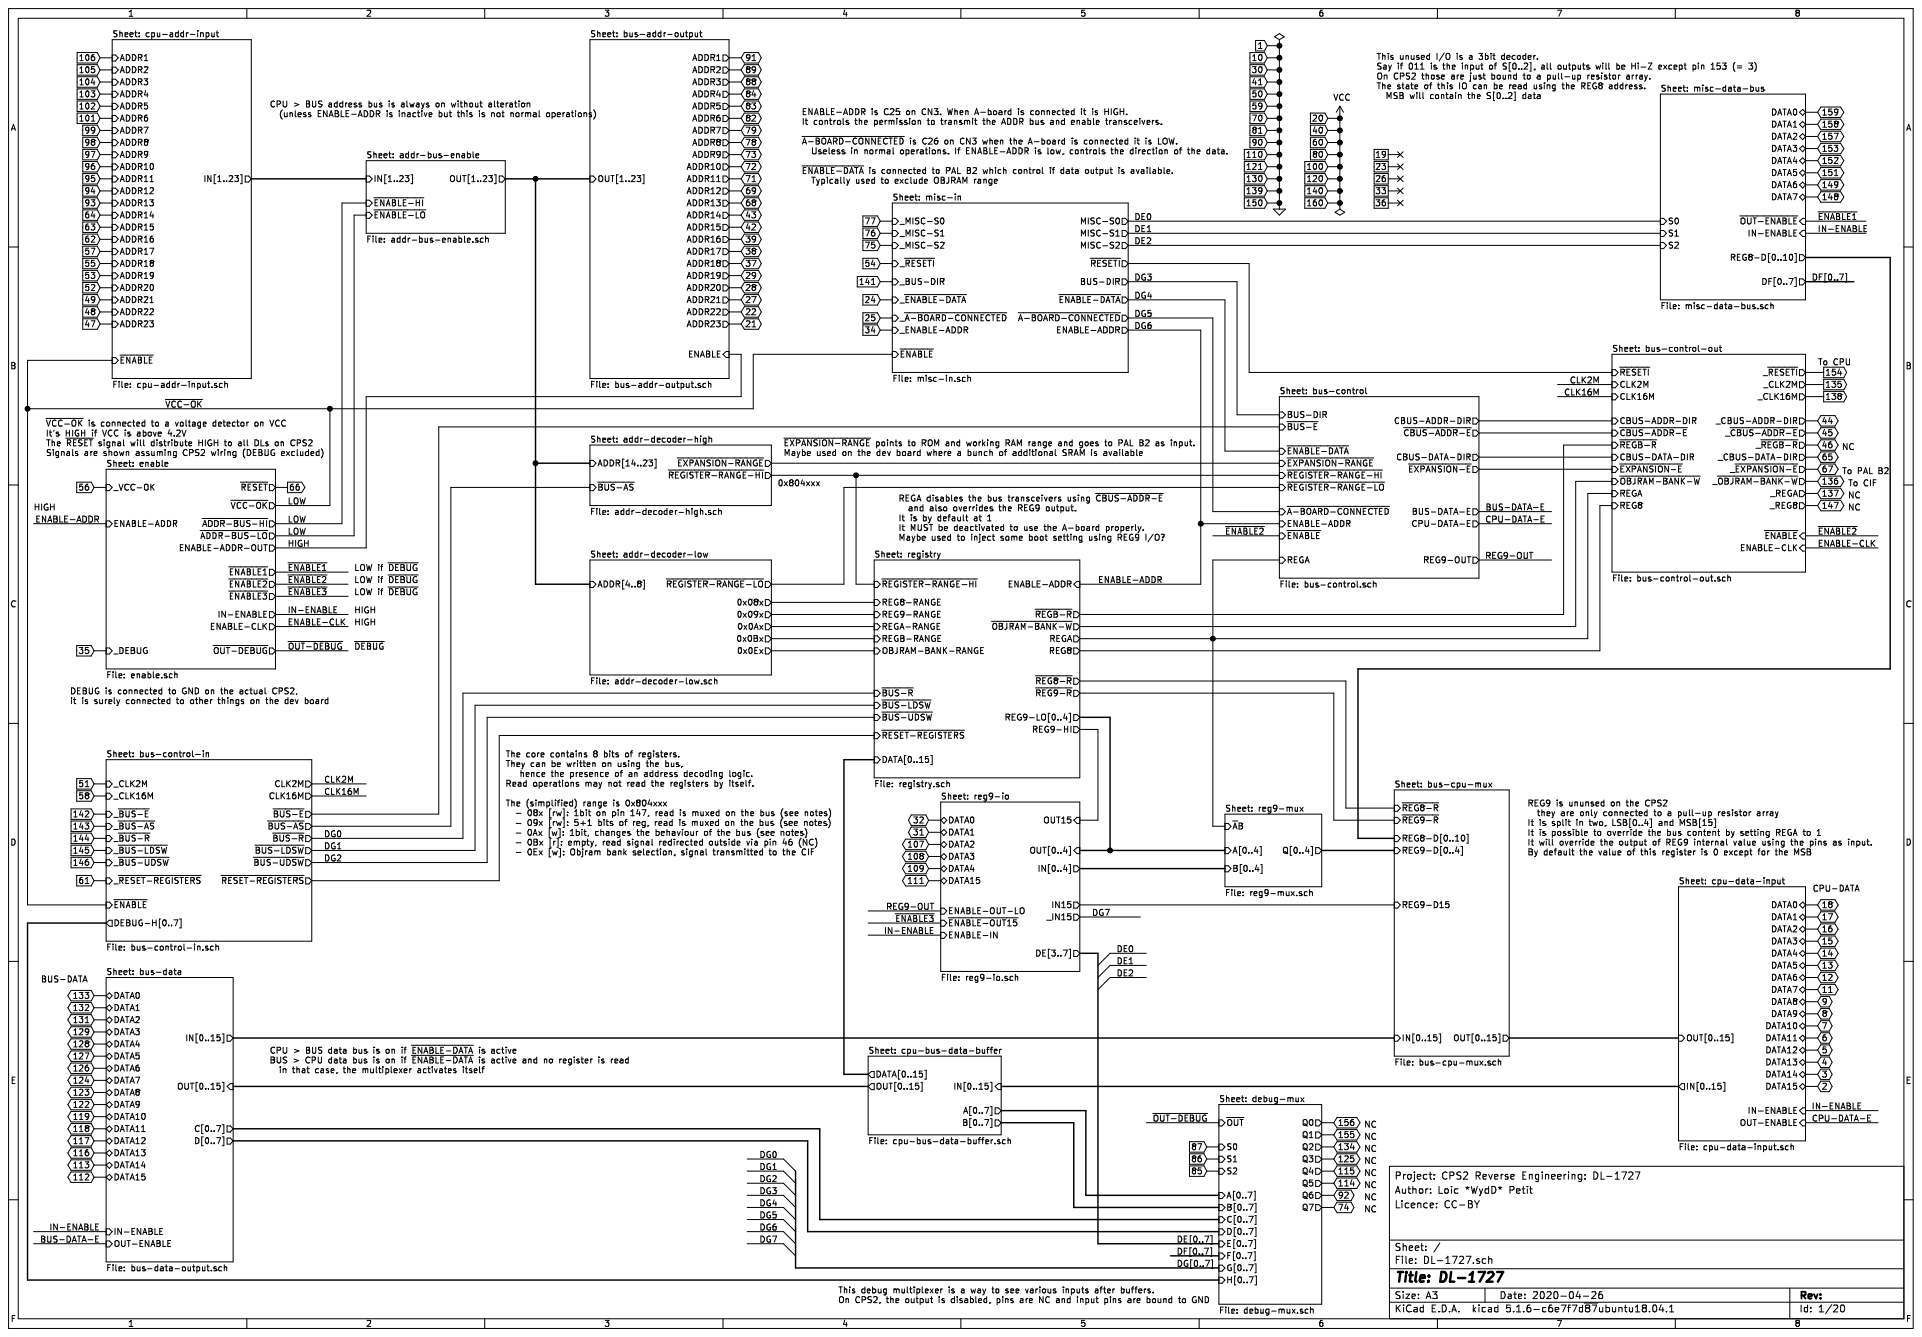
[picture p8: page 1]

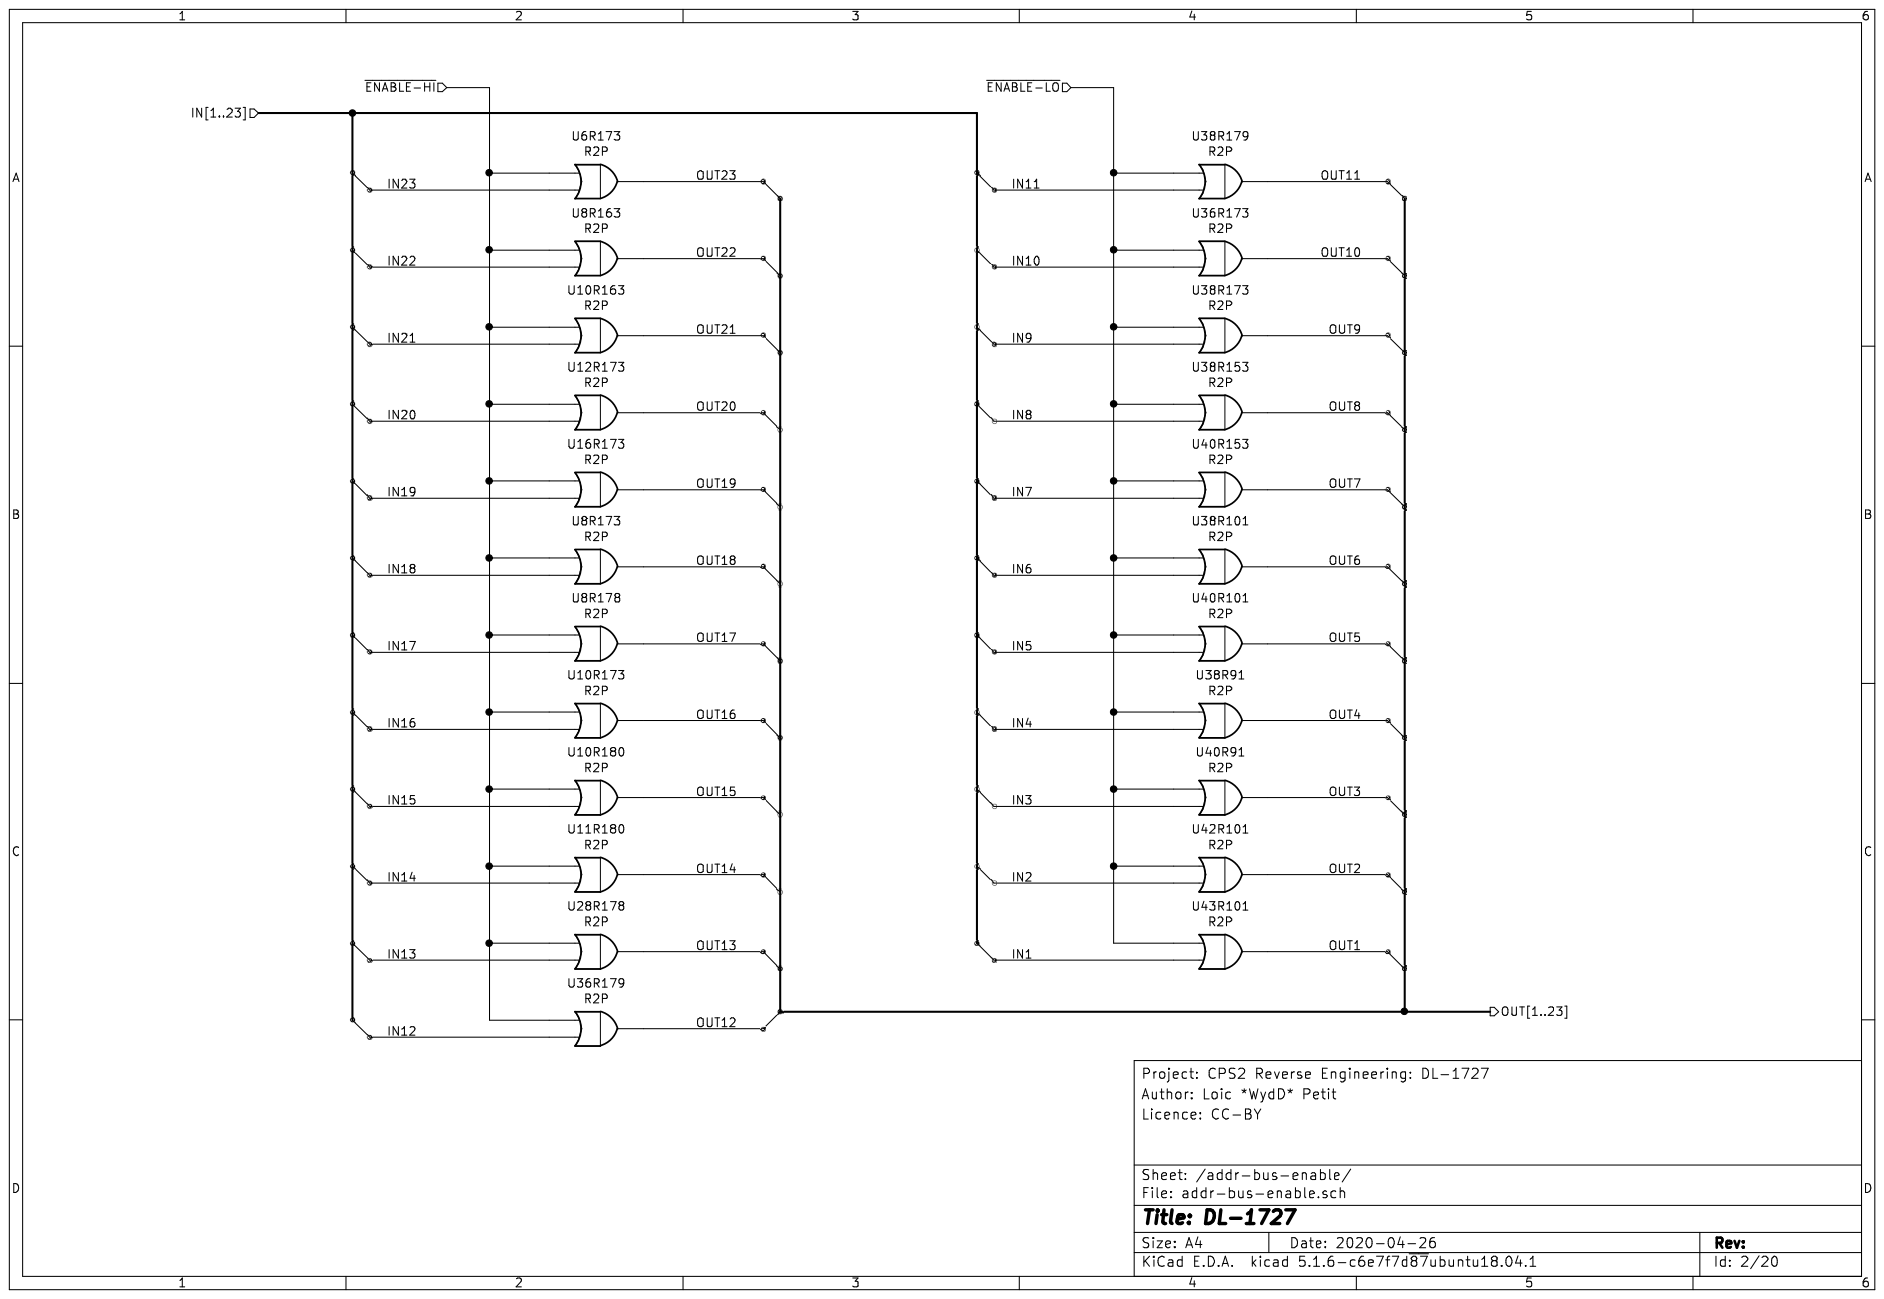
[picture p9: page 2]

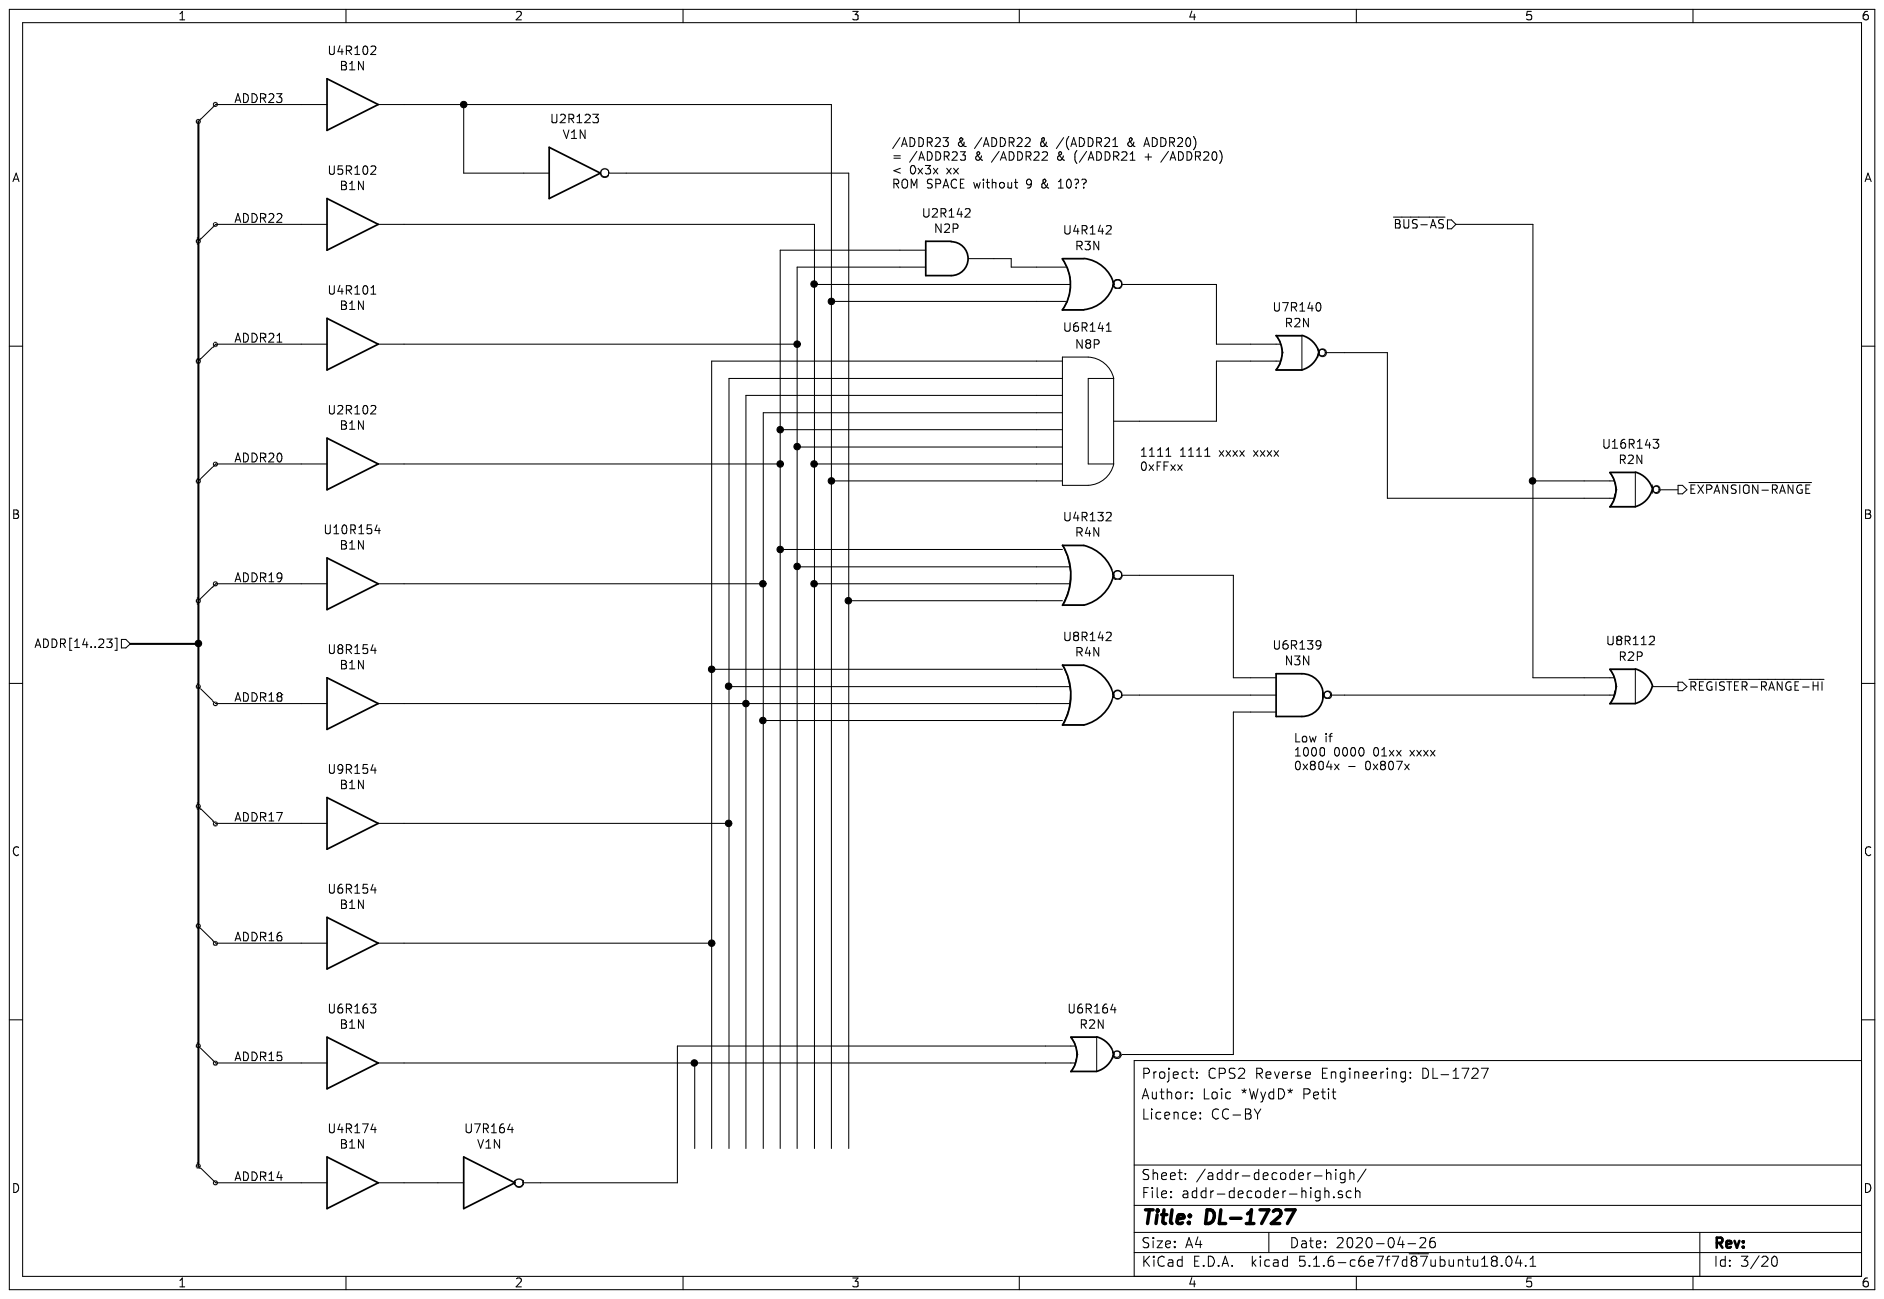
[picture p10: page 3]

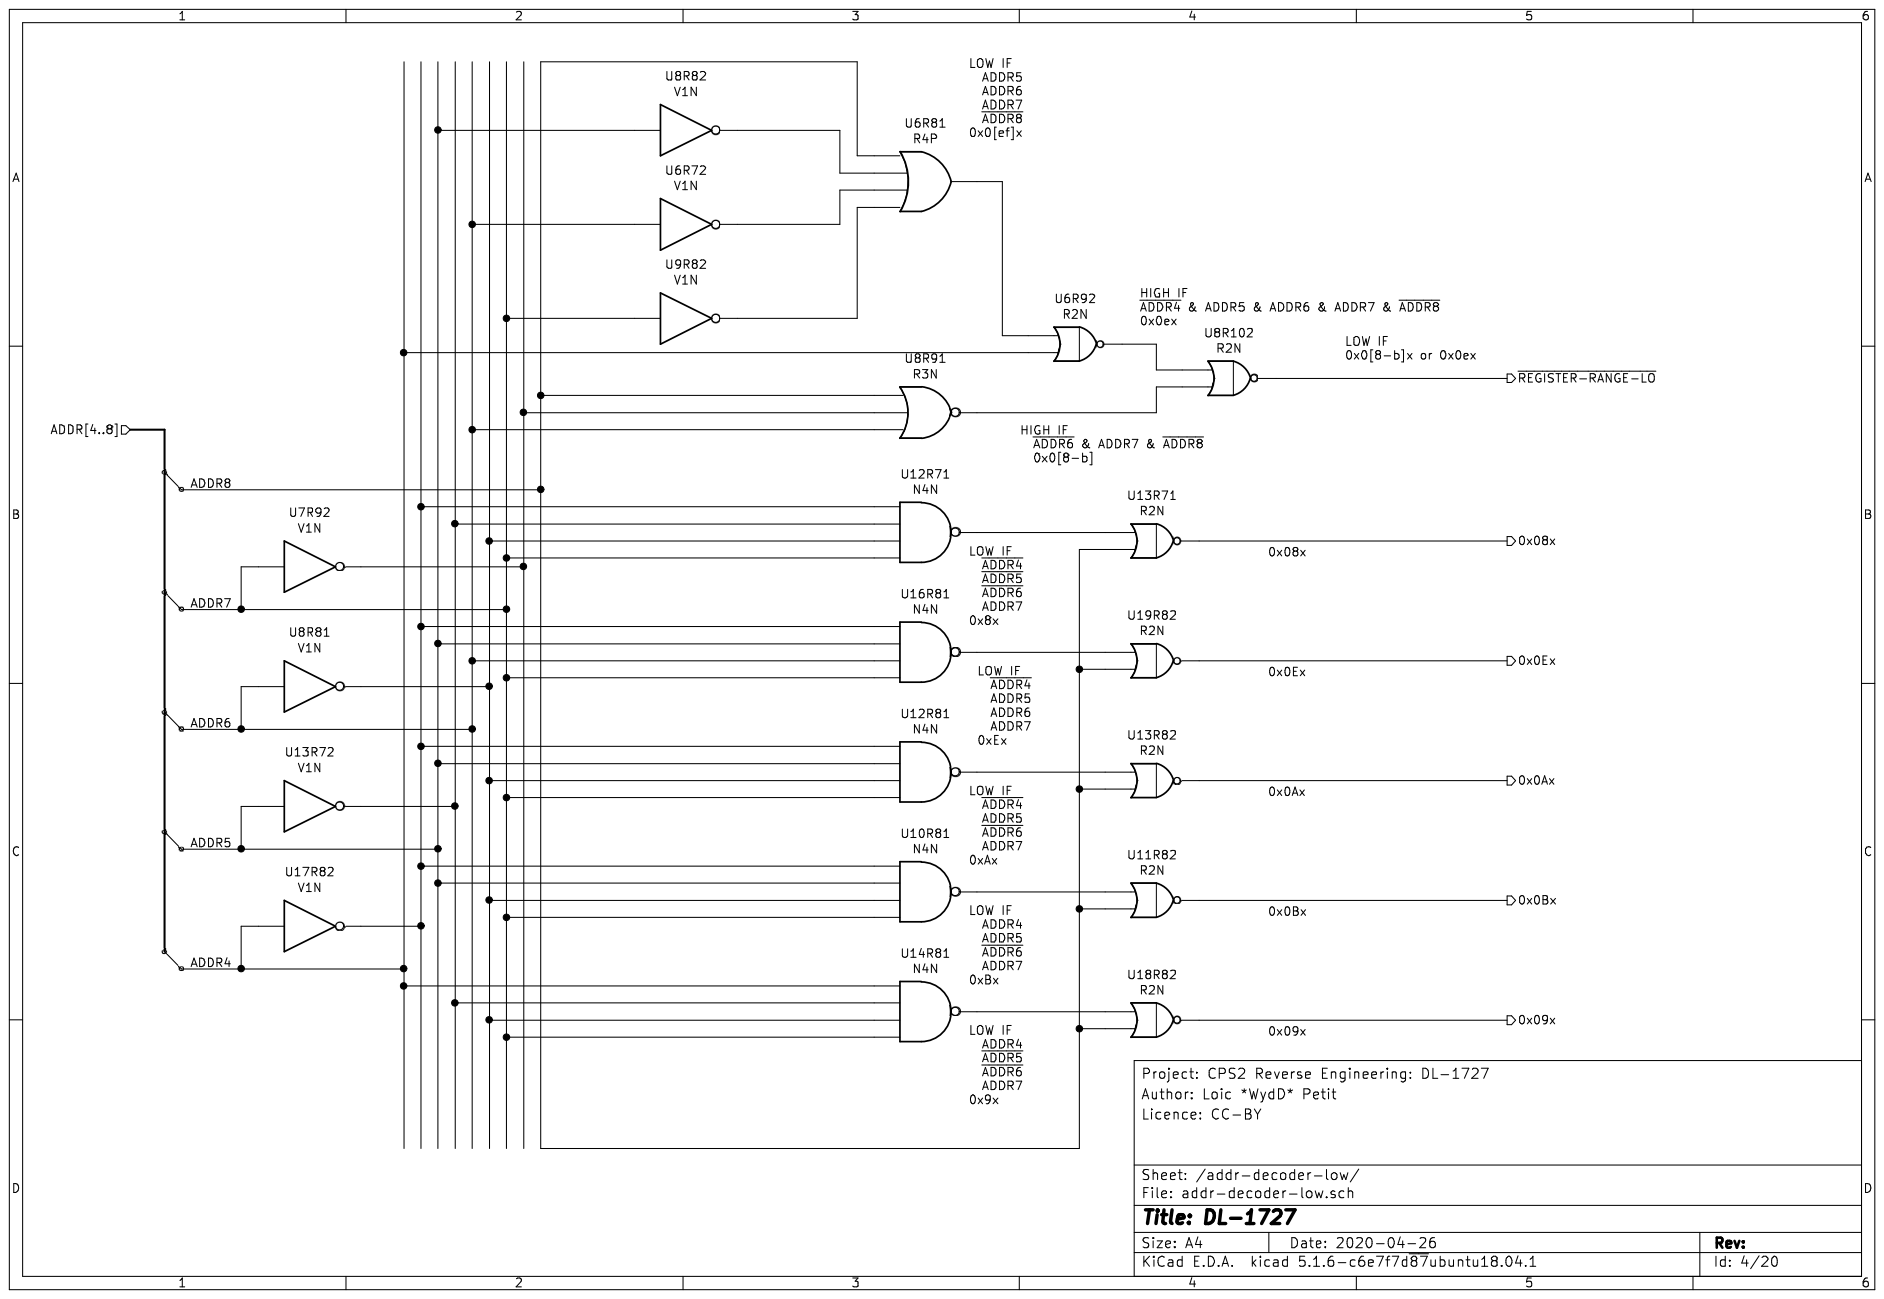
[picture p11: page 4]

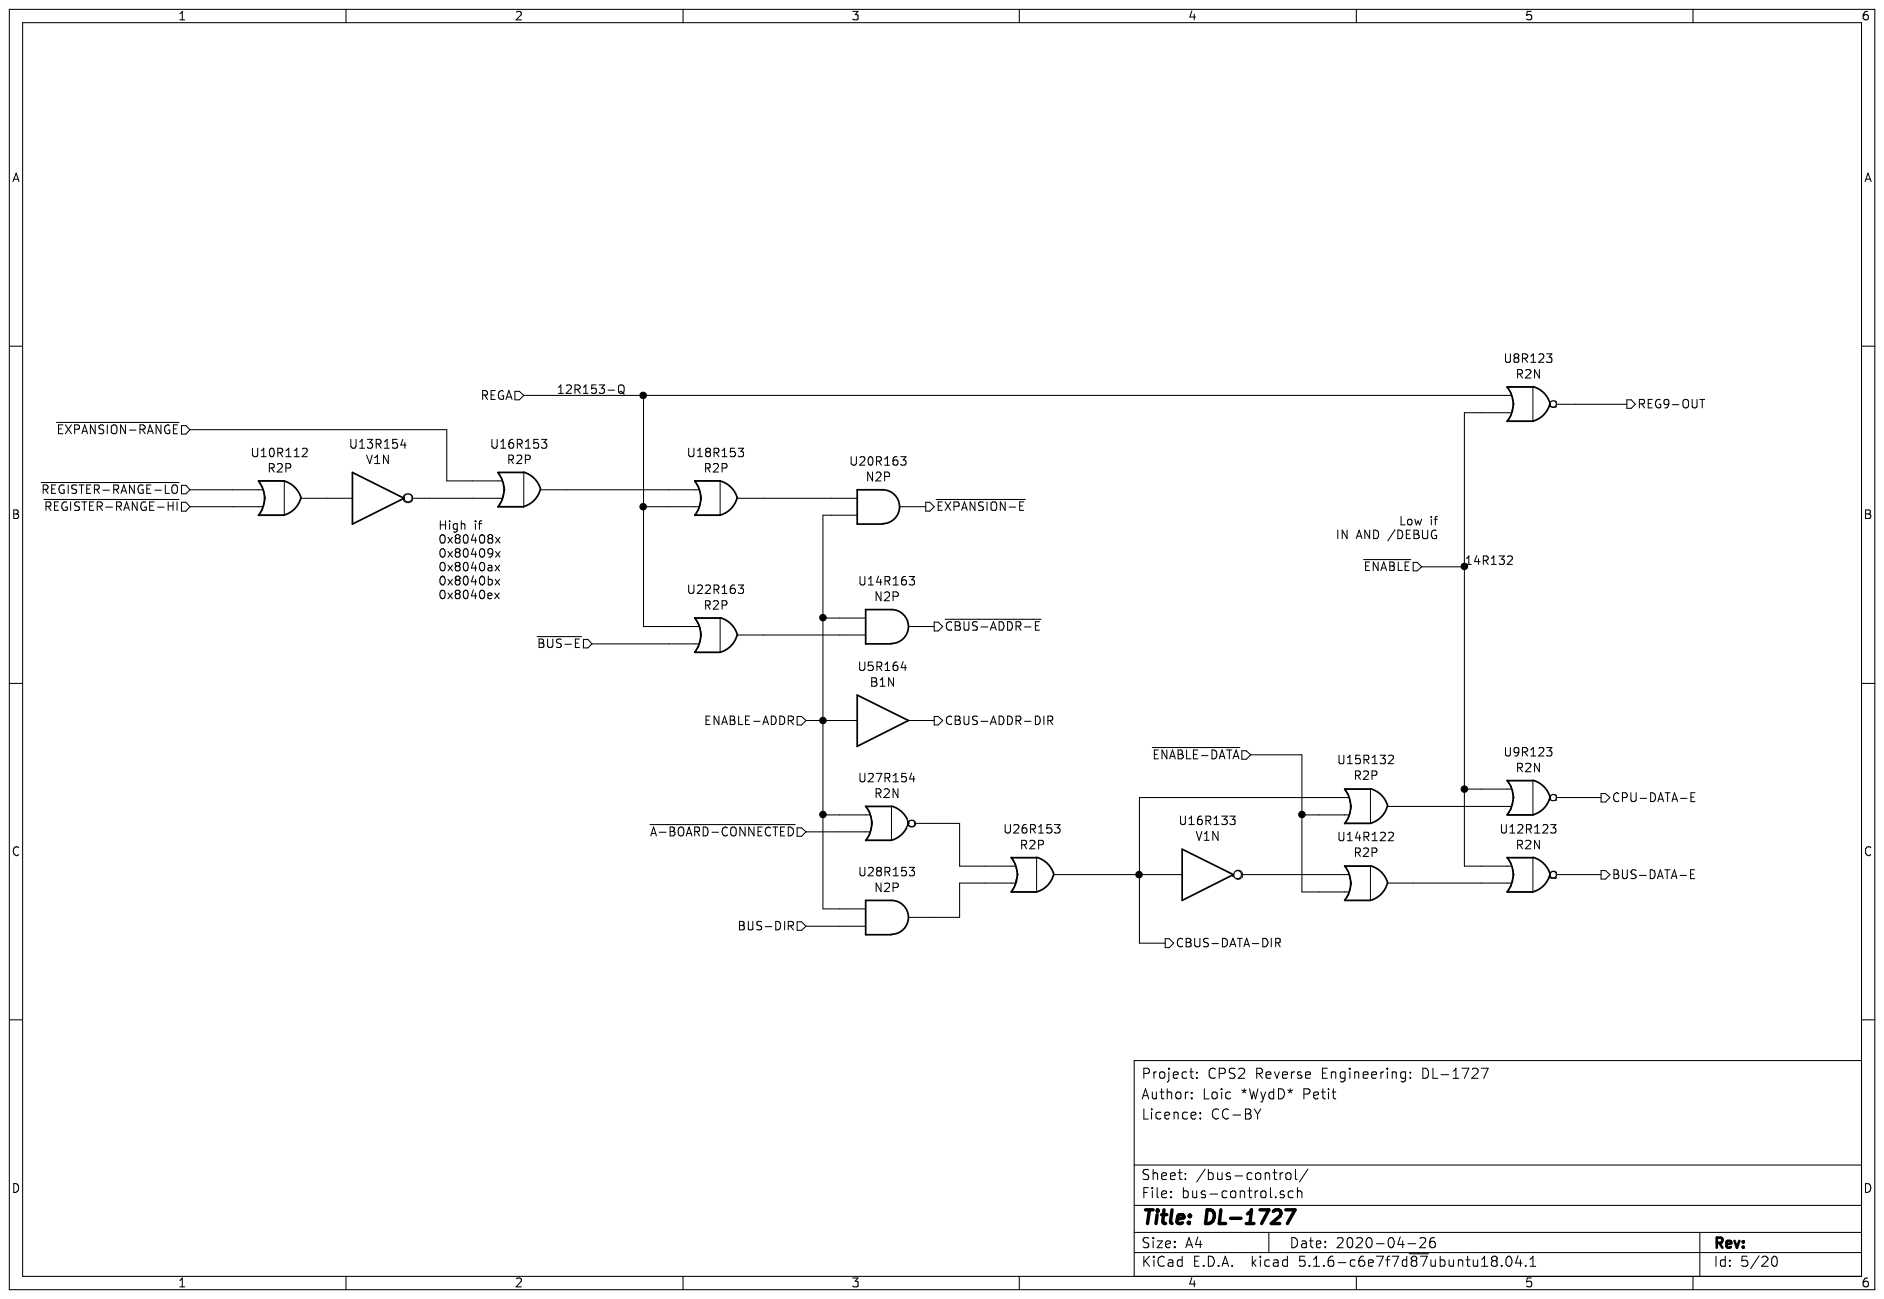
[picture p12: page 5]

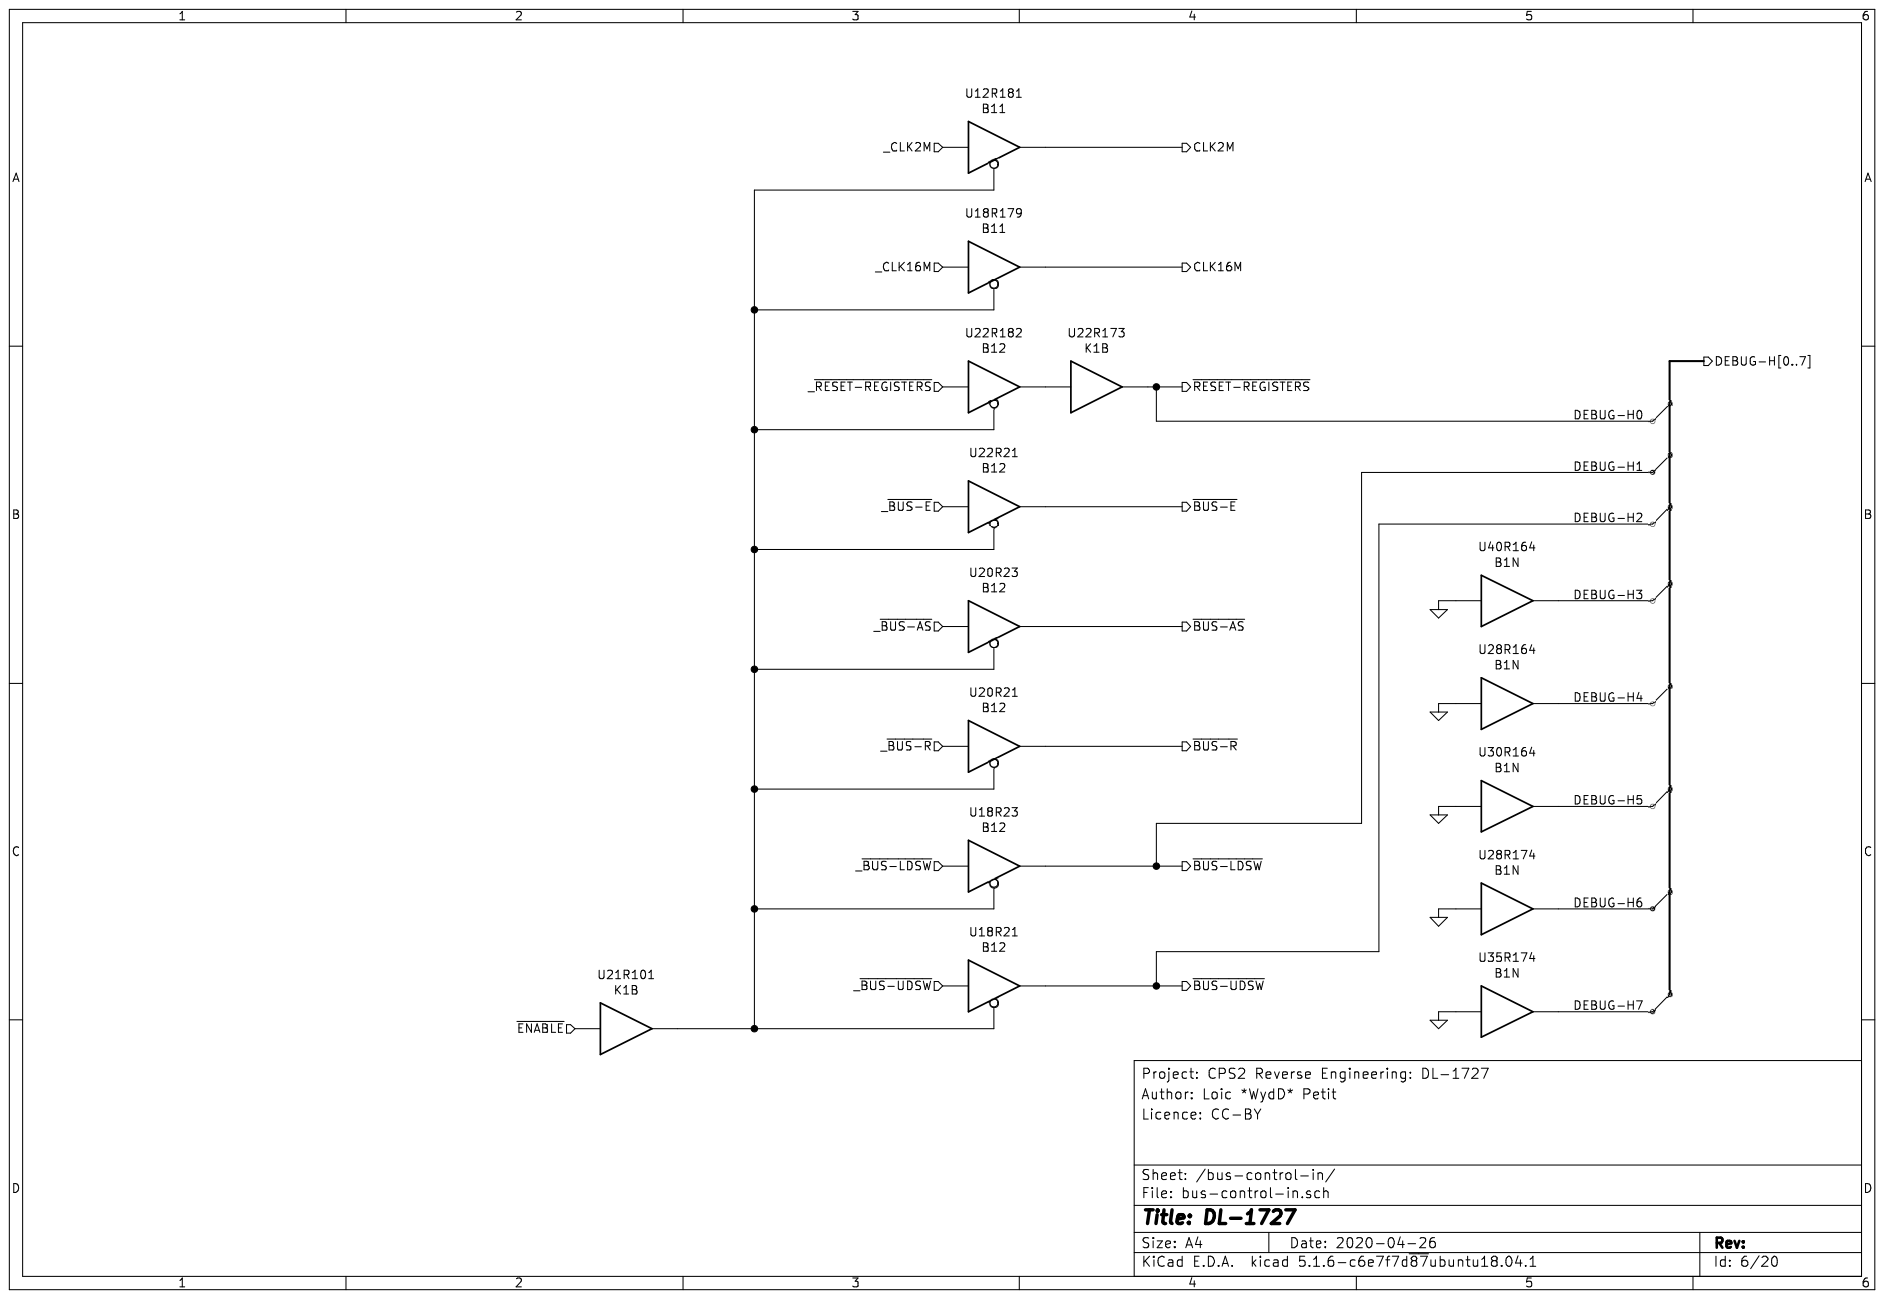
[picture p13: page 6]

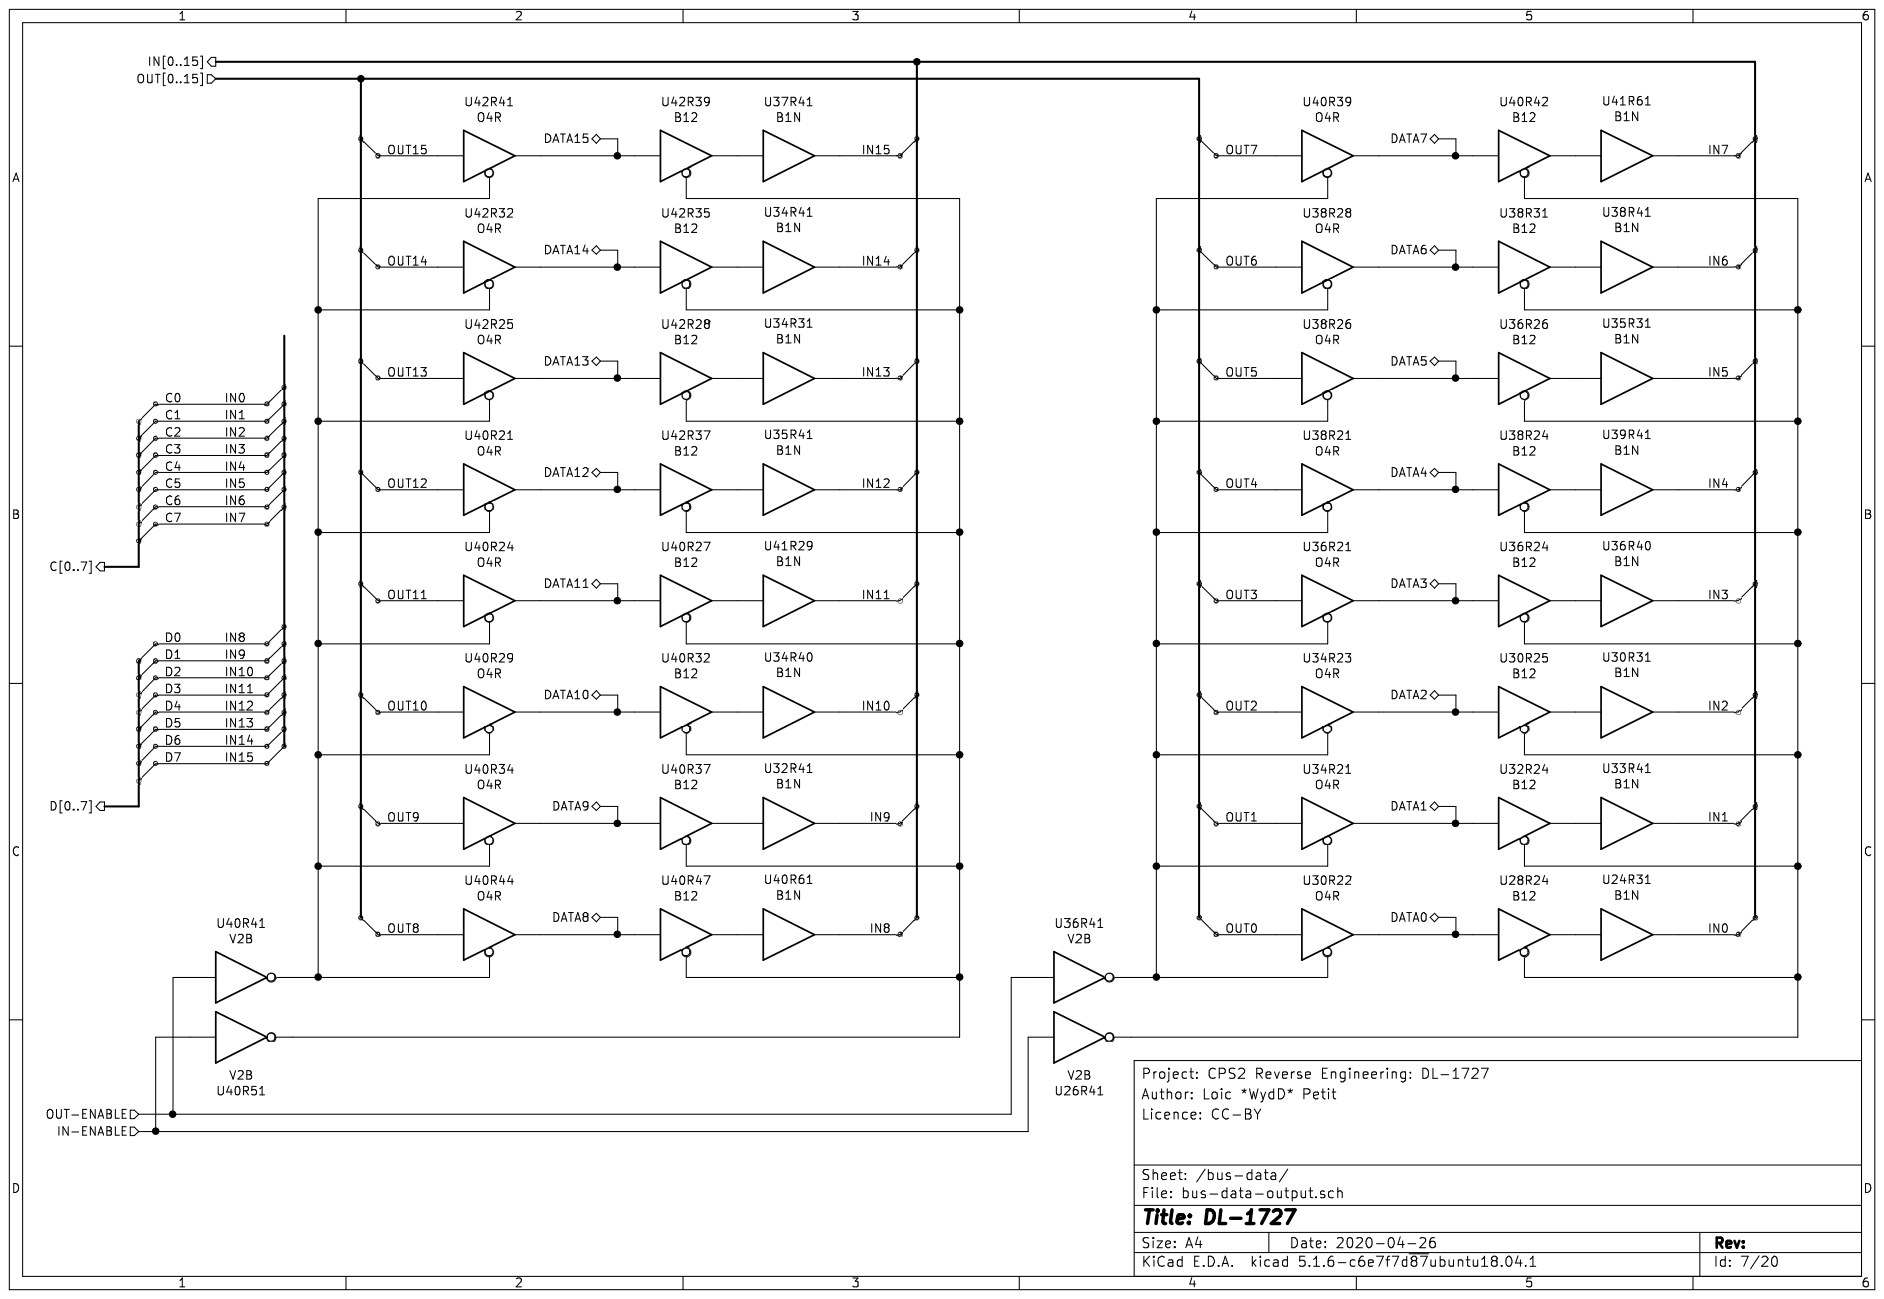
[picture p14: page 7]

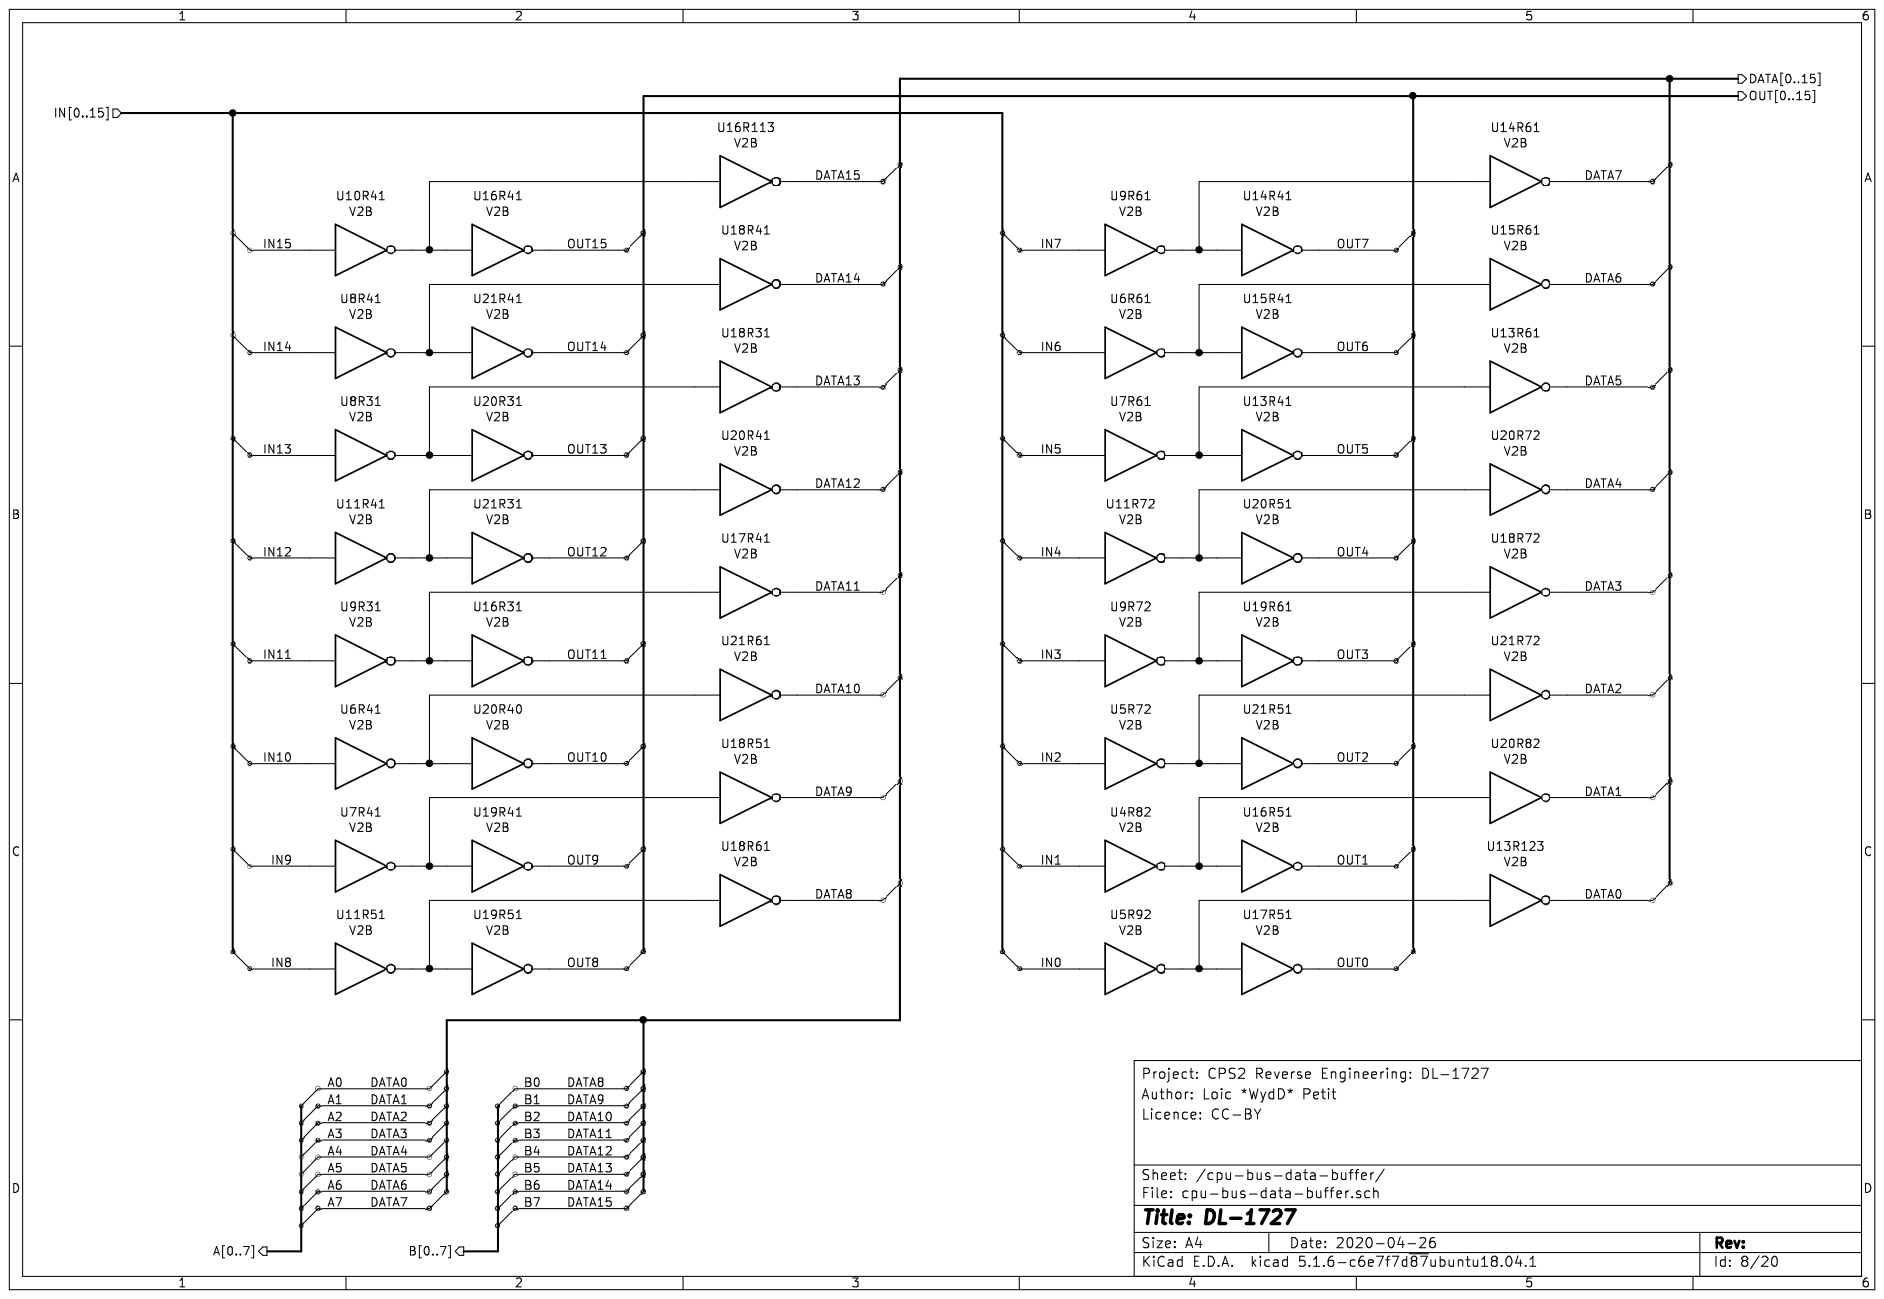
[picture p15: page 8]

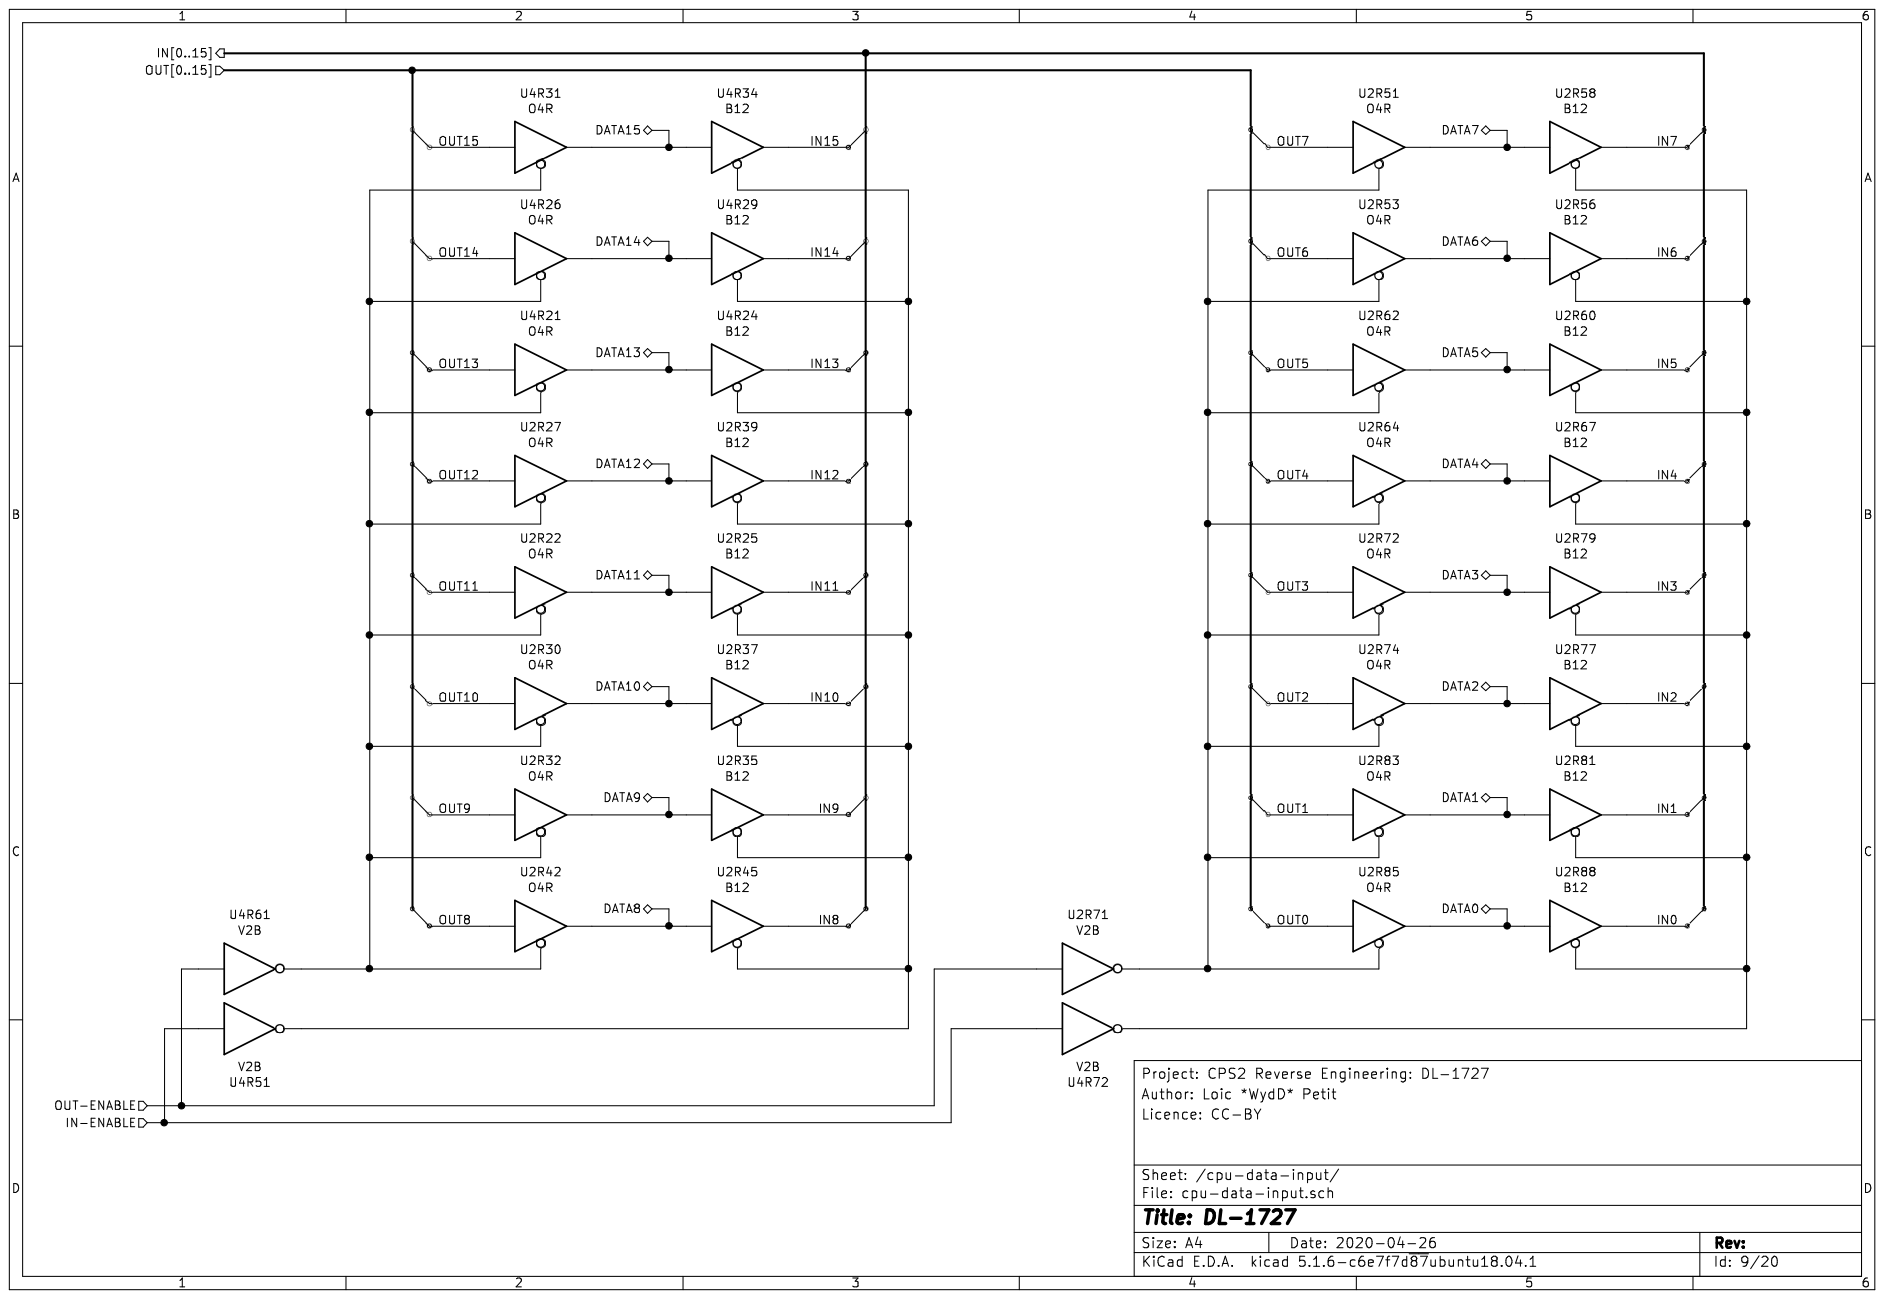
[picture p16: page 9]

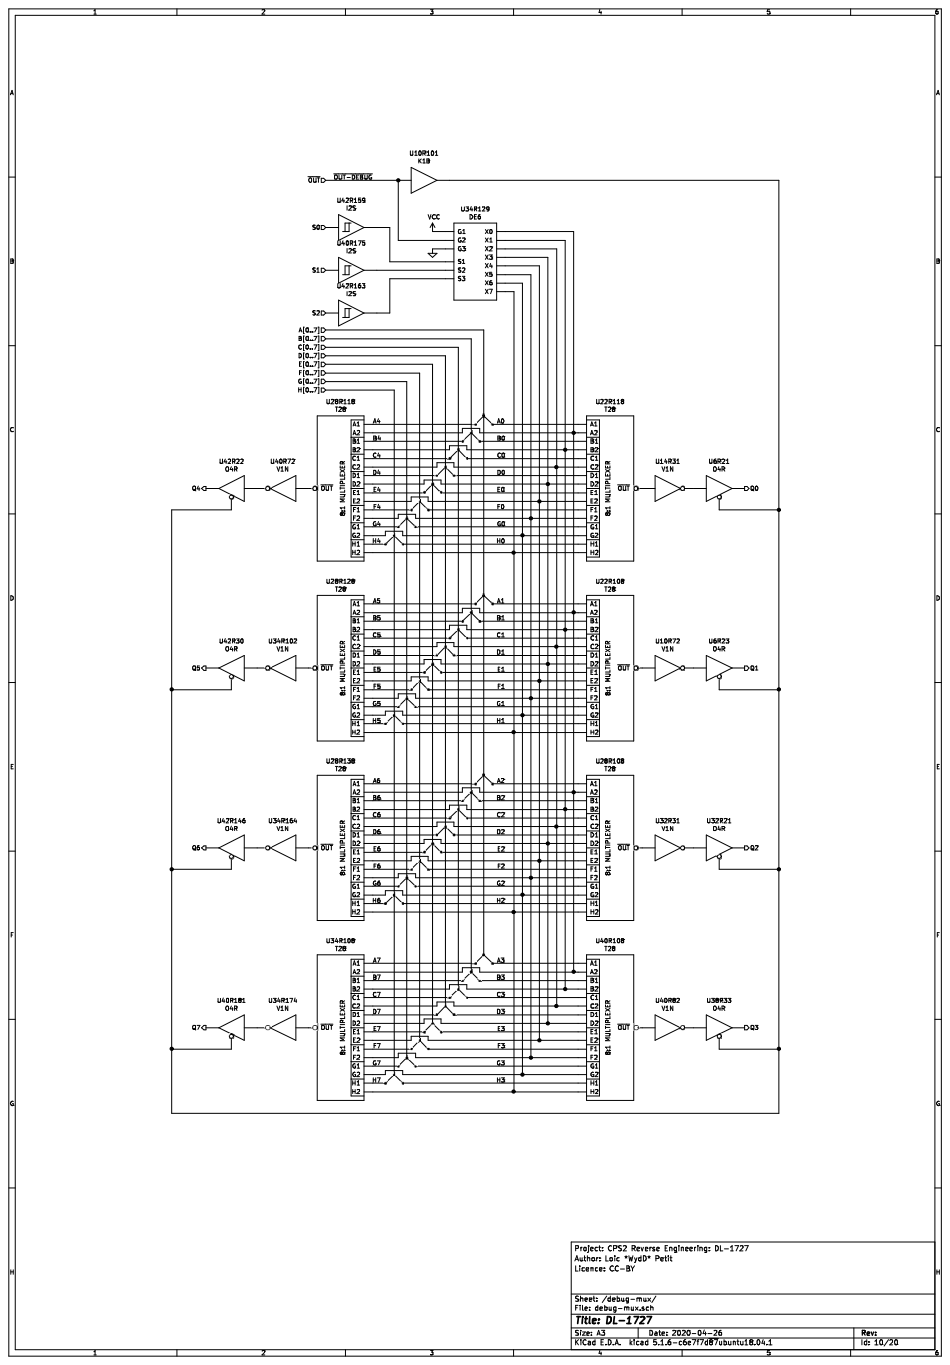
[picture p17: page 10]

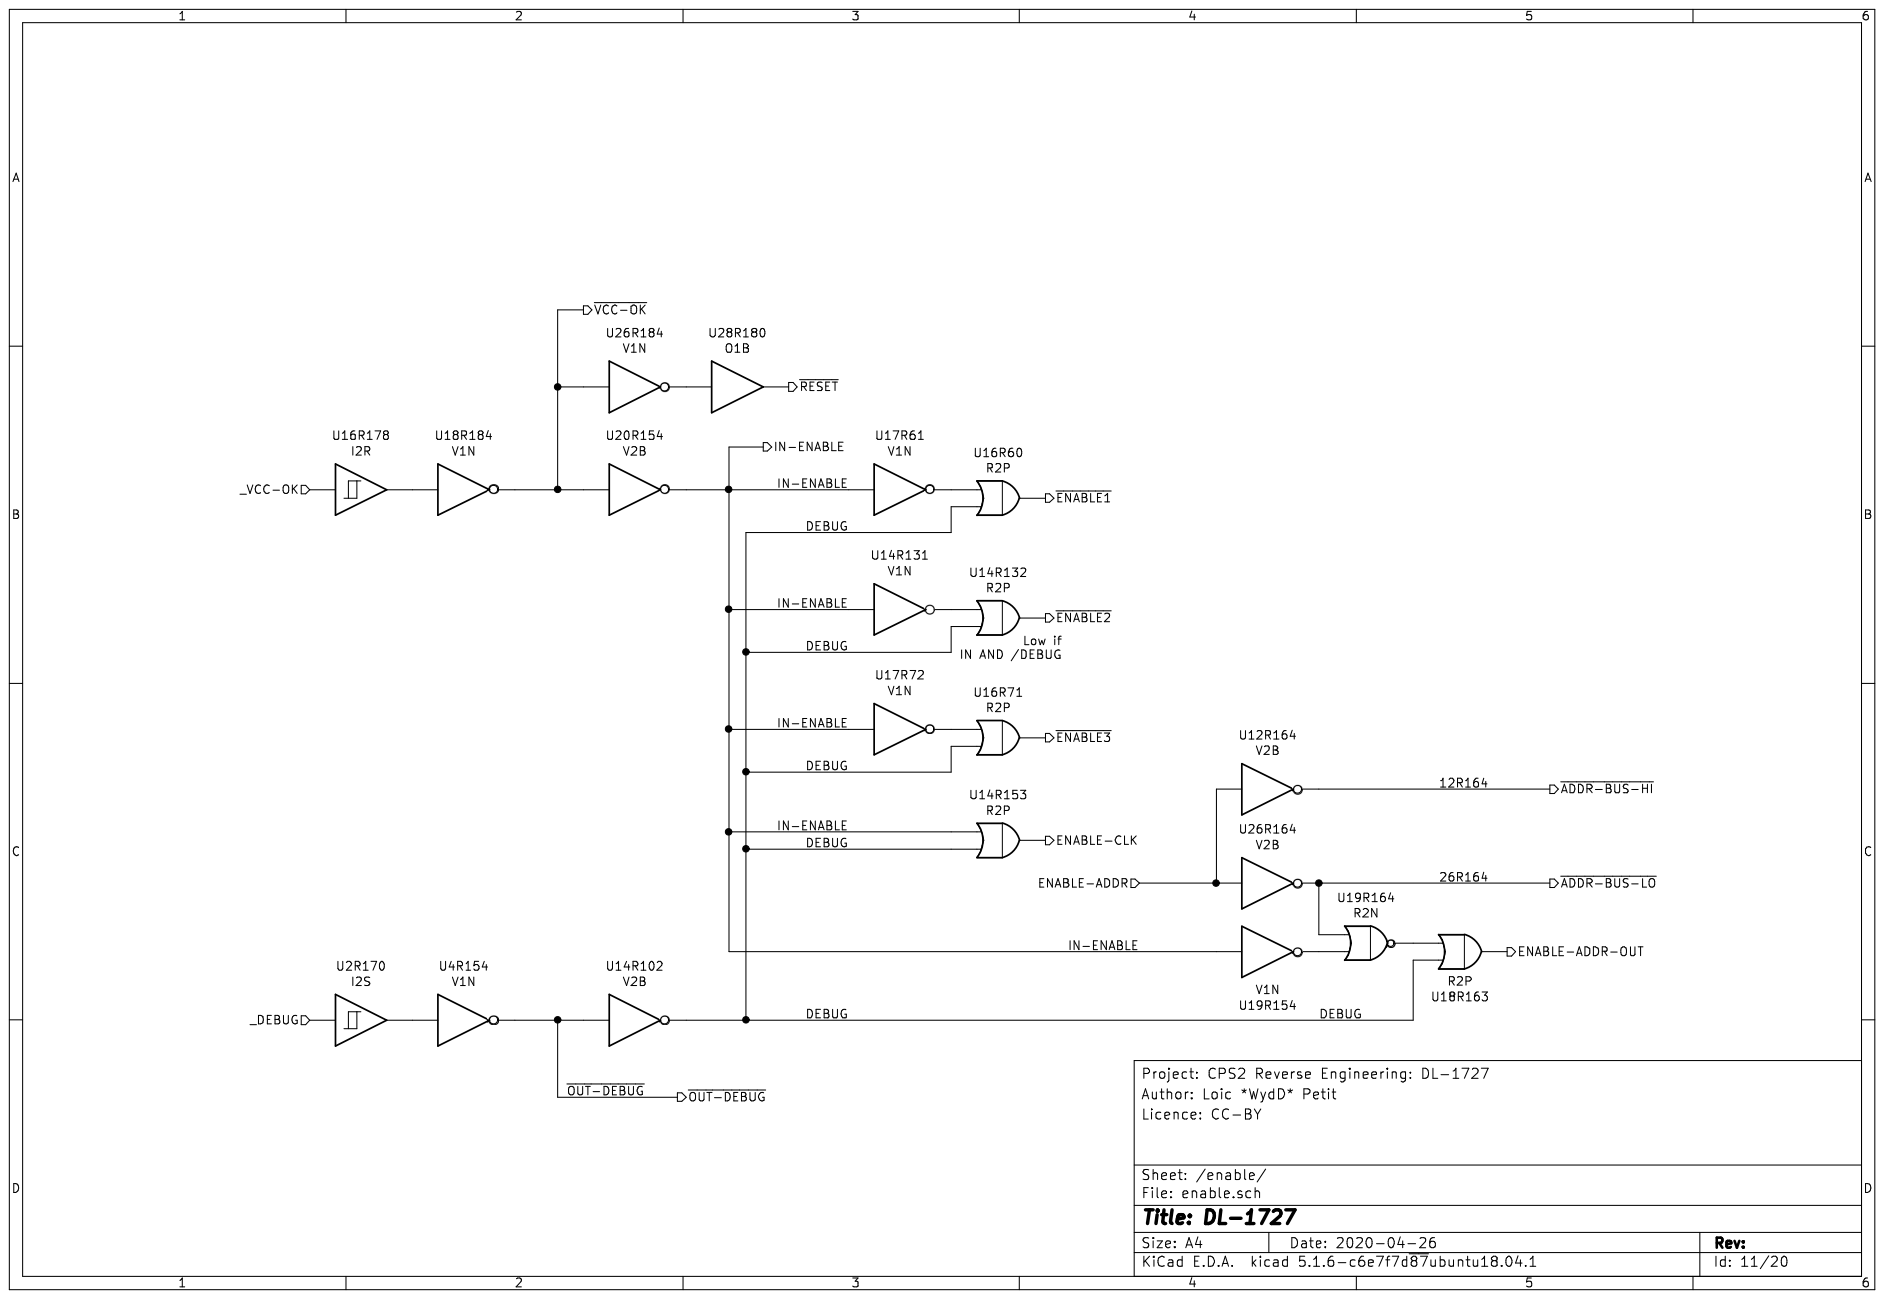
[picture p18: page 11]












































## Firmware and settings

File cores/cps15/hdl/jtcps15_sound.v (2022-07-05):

/*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
    Author: Jose Tejada Gomez. Twitter: @topapate
    Version: 1.0
    Date: 19-9-2020 */

module jtcps15_sound(
    input             rst,
    input             clk96,
    input             clk48,
    input             cen8,
    input             vol_up,
    input             vol_down,
    output reg [12:0] volume, // volume moves in 2dB steps
    // Decode keys
    input             kabuki_we,
    input             kabuki_en,

    // Interface with main CPU
    input      [23:1] main_addr,
    input      [ 7:0] main_dout,
    output reg [ 7:0] main_din,
    input             main_ldswn,
    input             main_buse_n,
    output            main_busakn,
    output            main_waitn,

    // ROM
    output reg [18:0] rom_addr, // 512 kByte
    output reg        rom_cs,
    input      [ 7:0] rom_data,
    input             rom_ok,

    // QSound sample ROM
    output reg [22:0] qsnd_addr, // max 8 MB.
    output            qsnd_cs,
    input      [ 7:0] qsnd_data,
    input             qsnd_ok,

    // ROM programming interface
    input      [12:0] prog_addr,
    input      [ 7:0] prog_data,
    input             prog_we,

    // Sound output
    output signed [15:0] left,
    output signed [15:0] right,
    output               sample
);

wire        cpu_cen, cen_extra;
wire [ 7:0] dec_dout, ram_dout, cpu_dout, bus_din;
wire [15:0] A, bus_A;
reg  [ 3:0] bank;
reg  [ 7:0] cpu_din;
reg         rstn;
reg         ram_cs, bank_cs, qsnd_wr, qsnd_rd;
wire        ram_we, int_n, mreq_n, wr_n, rd_n, m1_n, iorq_n;
wire        busrq_n, busak_n, halt_n, z80_buswn;
wire        bus_wrn, bus_mreqn, main_busn;
reg         main_busn_dly;

// QSound registers
reg         [23:0] cpu2dsp;
reg                dsp_irq; // UR6B in schematics
reg         [ 1:0] dsp_datasel;
reg  signed [15:0] reg_left, reg_right, pre_l, pre_r;
wire signed [15:0] fxd_l, fxd_r;
wire               resample48;

// DSP16 wires
wire [15:0] dsp_ab, dsp_pbus_out;
reg  [15:0] dsp_pbus_in;
wire        dsp_pods_n, dsp_pids_n;
wire        dsp_do, dsp_ock, dsp_doen;
wire        dsp_iack, dsp_ext_rq;
reg         dsp_rst;
wire        dsp_psel, dsp_sadd, dsp_rdy_n;
wire        dsp_cen_cko;
wire        cen_dsp;
reg         base_sample;

reg         last_pids_n;
reg         rom_okl, last_romcs;

`ifndef NOSOUND
assign      dsp_rdy_n = ~(dsp_irq | dsp_iack);

jtcps15_qsnd_cen u_dspcen(
    .clk96       ( clk96       ),
    .clk48       ( clk48       ),
    .rst         ( rst         ),
    .base_sample ( base_sample ),
    .qsnd_ok     ( qsnd_ok     ),
    .ext_rq      ( dsp_ext_rq  ),
    .qsnd_cen    ( cen_dsp     ),
    // sound resample
    .l_in        ( pre_l       ),
    .r_in        ( pre_r       ),
    .l_out       ( fxd_l       ),
    .r_out       ( fxd_r       ),
    .resample48  ( resample48  )
);

`else
reg rdy_reads, last_rd;
assign      dsp_rdy_n = rdy_reads;

always @(posedge clk48, posedge rst) begin
    if( rst ) begin
        rdy_reads <= 0;
        last_rd   <= 0;
    end else begin
        last_rd <= qsnd_rd;
        if( !qsnd_rd && last_rd ) rdy_reads <= ~rdy_reads;
    end
end
`endif

`ifdef SIMULATION
wire bank_access = rom_cs & A[15];
`endif

reg [1:0] ram_ok;
reg  main_busnl;
wire bus_equ;

assign bus_equ     = main_busn == main_busnl;
assign ram_we      = ram_cs && !bus_wrn;
assign bus_A       = main_busn ?        A : main_addr[16:1];
assign bus_wrn     = main_busn ?     wr_n : main_ldswn;
assign bus_din     = main_busn ? cpu_dout : main_dout;
assign bus_mreqn   = main_busn ?   mreq_n : main_buse_n;
assign main_busakn = main_busn_dly | main_busn | busrq_n |
    //(rom_cs & ~(rom_ok & rom_okl)) |
    (rom_cs & ~last_romcs);
assign main_waitn  = rom_cs ? rom_ok & rom_okl : bus_equ & ram_ok[0];

always @(posedge clk48) begin
    main_busnl <= main_busn;
    ram_ok <= { ram_ok[0] & bus_equ, bus_equ };
    if(!main_busn) main_din <= cpu_din; // bus output
    main_busn_dly <= main_busn;
    rom_okl    <= rom_ok;
    last_romcs <= rom_cs;
end

always @(negedge clk48) begin
    rstn <= ~rst;
end

//always @(posedge clk48, posedge rst) begin
always @(*) begin
    //if ( rst ) begin
    //    rom_cs    <= 0;
    //    rom_addr  <= 16'd0;
    //    ram_cs    <= 0;
    //    bank_cs   <= 0;
    //    qsnd_wr   <= 0;
    //    qsnd_rd   <= 0;
    //end else begin
        rom_cs  = !bus_mreqn && (!bus_A[15] || bus_A[15:14]==2'b10);
        //if(!bus_mreqn) begin
        rom_addr = (bus_A[15] ? ({ 1'b0, bank, bus_A[13:0] } + 19'h8000) : { 4'b0, bus_A[14:0] });
//            rom_addr = (~mreq_n & main_busakn) ?
//                // Z80
//                (bus_A[15] ? ({ 1'b0, bank, bus_A[13:0] } + 19'h8000) : { 4'b0, bus_A[14:0] }) :
//                // M68000
//                main_addr[19:1];
        //end
        ram_cs   = !bus_mreqn && (bus_A[15:12] == 4'hc || bus_A[15:12]==4'hf);
        qsnd_wr  = !bus_mreqn && !bus_wrn && (bus_A[15:12] == 4'hd && bus_A[2:0]<=3'd2);
        bank_cs  = !bus_mreqn && !bus_wrn && (bus_A[15:12] == 4'hd && bus_A[2:0]==3'd3);
        qsnd_rd  = !bus_mreqn && !rd_n && (bus_A[15:12] == 4'hd && bus_A[2:0]==3'd7);
   // end
end

// wire qs0l_w = qsnd_wr && A[2:0]==2'd0;
// wire qs0h_w = qsnd_wr && A[2:0]==2'd1;
wire qs1l_w = qsnd_wr && A[2:0]==2;
reg [23:0] cpu2dsp_s;

always @(posedge clk48, posedge rst) begin
    if ( rst ) begin
        bank    <= 4'd0;
        cpu2dsp <= 24'd0;
        dsp_rst <= 1;
    end else begin
        if( bank_cs ) begin
            bank    <= bus_din[3:0];
            dsp_rst <= ~bus_din[7];
        end
        if( qsnd_wr ) begin
            case( A[2:0] )
                0: cpu2dsp[15: 8] <= bus_din; // data word MSB
                1: cpu2dsp[ 7: 0] <= bus_din; // data word LSB
                2: cpu2dsp[23:16] <= bus_din; // address
                default:;
            endcase // A[2:0]
        end
    end
end

always @(*) begin
    cpu_din =  rom_cs ? ( A[15] ? rom_data : dec_dout ) : (
               ram_cs ? ram_dout : (
              qsnd_rd ? { dsp_rdy_n, 3'b111, bank } : 8'hff
              ));
end

assign busrq_n = main_buse_n;
assign main_busn = busak_n;

jtcps15_z80int u_z80int(
    .clk    ( clk48     ),
    .rst    ( rst       ),
    .cen8   ( cen8      ),
    .m1_n   ( m1_n      ),
    .iorq_n ( iorq_n    ),
    .int_n  ( int_n     )
);

jtcps15_z80wait u_extrawait(
    .clk    ( clk48     ),
    .rst    ( rst       ),
    .cen8   ( cen8      ),
    .m1_n   ( m1_n      ),
    .addr   ( A[15:12]  ),
    .cen_cpu( cen_extra )
);

jtframe_ram #(.aw(13)) u_z80ram( // 8 kB!
    .clk    ( clk48         ),
    .cen    ( 1'b1          ),
    .data   ( bus_din       ),
    .addr   ( bus_A[12:0]   ),
    .we     ( ram_we        ),
    .q      ( ram_dout      )
);
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

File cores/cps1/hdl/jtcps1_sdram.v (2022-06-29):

/*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
    Author: Jose Tejada Gomez. Twitter: @topapate
    Version: 1.0
    Date: 5-12-2020 */

module jtcps1_sdram #( parameter
           CPS     = 1,
           REGSIZE = 24,
           Z80_AW  = CPS==1 ? 16 : 19,
           PCM_AW  = CPS==1 ? 18 : 23
) (
    input           rst,
    input           clk,        // SDRAM clock (48/96)
    input           clk_gfx,    // 96 MHz
    input           clk_cpu,    // 48 MHz
    input           LVBL,

    input           downloading,
    output          dwnld_busy,
    output          cfg_we,

    // ROM LOAD
    input   [25:0]  ioctl_addr,
    input   [ 7:0]  ioctl_dout,
    output  [ 7:0]  ioctl_din,
    input           ioctl_wr,
    input           ioctl_ram,
    output  [22:0]  prog_addr,
    output  [15:0]  prog_data,
    output  [ 1:0]  prog_mask,
    output  [ 1:0]  prog_ba,
    output          prog_we,
    output          prog_rd,
    input           prog_rdy,
    output          prog_qsnd,

    // EEPROM
    input           sclk,
    input           sdi,
    output          sdo,
    input           scs,

    // Kabuki decoder (CPS 1.5)
    output          kabuki_we,

    // CPS2 Keys
    output          cps2_key_we,
    output   [ 1:0] cps2_joymode,

    // Main CPU
    input           main_rom_cs,
    output          main_rom_ok,
    input    [20:0] main_rom_addr,
    output   [15:0] main_rom_data,

    // VRAM
    input           vram_clr,
    input           vram_dma_cs,
    input           main_ram_cs,
    input           main_vram_cs,
    input           main_oram_cs,
    `ifdef CPS2
    input           obank,
    input    [15:0] oram_base,
    input    [12:0] gfx_oram_addr,
    output   [15:0] gfx_oram_data,
    output          gfx_oram_ok,
    input           gfx_oram_clr,
    input           gfx_oram_cs,
    `endif
    input           vram_rfsh_en,

    input    [ 1:0] dsn,
    input    [15:0] main_dout,
    input           main_rnw,

    output          main_ram_ok,
    output          vram_dma_ok,

    input    [17:1] main_ram_addr,
    input    [17:1] vram_dma_addr,

    output   [15:0] main_ram_data,
    output   [15:0] vram_dma_data,

    // Sound CPU and PCM
    input           snd_cs,
    input           pcm_cs,

    output          snd_ok,
    output          pcm_ok,

    input [Z80_AW-1:0] snd_addr,
    input [PCM_AW-1:0] pcm_addr,

    output     [7:0] snd_data,
    output     [7:0] pcm_data,

    // Graphics
    input           rom0_cs,
    input           rom1_cs,

    output reg      rom0_ok, // obj
    output          rom1_ok,

    input    [19:0] rom0_addr,
    input    [ 1:0] rom0_bank,
    input    [19:0] rom1_addr,

    input           rom0_half,
    input           rom1_half,

    output reg [31:0] rom0_data,  // obj
    output     [31:0] rom1_data,

    input             star_bank,
    input     [12:0]  star0_addr,
    output    [31:0]  star0_data,
    output            star0_ok,
    input             star0_cs,

    input     [12:0]  star1_addr,
    output    [31:0]  star1_data,
    output            star1_ok,
    input             star1_cs,

    // Bank 0: allows R/W
    output   [22:0] ba0_addr,
    output   [22:0] ba1_addr,
    output   [22:0] ba2_addr,
    output   [22:0] ba3_addr,
    output   [ 3:0] ba_rd,
    output          ba_wr,
    output   [15:0] ba0_din,
    output   [ 1:0] ba0_din_m,  // write mask
    input    [ 3:0] ba_ack,
    input    [ 3:0] ba_dst,
    input    [ 3:0] ba_dok,
    input    [ 3:0] ba_rdy,

    input    [15:0] data_read,
    output          dump_flag
);

localparam [22:0] ZERO_OFFSET  = 23'h0,
                  PCM_OFFSET   = ZERO_OFFSET,
                  VRAM_OFFSET  = 23'h20_0000,
                  ORAM_OFFSET  = 23'h28_0000,
                  WRAM_OFFSET  = 23'h30_0000,
                  SND_OFFSET   = 23'h38_0000,
                  ROM_OFFSET   = ZERO_OFFSET;

// Disabling the SDRAM cache latch increases
// object trhoughput
`ifdef MISTER
localparam OBJ_LATCH=0;
`else
// MiST/SiDi struggle with timing with the low latency setting
// So it is disabled. Nonetheless,
// they enjoy a different benefit as the SDRAM has dedicated
// lines for DQMH/L
localparam OBJ_LATCH=1;
`endif

`ifdef CPS2
    localparam [22:0] SCR_OFFSET = 23'h00_0000; // change this when moving to 8MB+ GFX
    localparam        CPS2       = 1;
`else
    localparam [22:0] SCR_OFFSET = ZERO_OFFSET;
    localparam        CPS2       = 0;

    wire [12:0] gfx_oram_addr = 13'd0;
    wire [15:0] gfx_oram_data;
    wire        gfx_oram_ok;
    wire        gfx_oram_clr = 0;
    wire        gfx_oram_cs  = 0;
`endif

`ifdef CPS15
localparam EEPROM_AW=7, EEPROM_DW=8;
`else
localparam EEPROM_AW=6, EEPROM_DW=16;
`endif

(*keep*) wire [22:0] cps2_gfx0;
wire [21:0] gfx1_addr, gfx0_addr;
wire [22:0] main_offset;
wire        ram_vram_cs;
wire        ba2_rdy_gfx, ba2_ack_gfx;
reg  [17:1] main_addr_x; // main addr modified for object bank access
reg         ocache_clr, obank_last;
wire        dump_we;


assign gfx0_addr   = {rom0_addr, rom0_half, 1'b0 }; // OBJ
assign gfx1_addr   = {rom1_addr, rom1_half, 1'b0 };
assign ram_vram_cs = main_ram_cs | main_vram_cs | main_oram_cs;
assign main_offset = main_oram_cs ? ORAM_OFFSET :
                    (main_ram_cs  ? WRAM_OFFSET : VRAM_OFFSET );
assign prog_rd     = 0;
assign dump_we     = ioctl_wr & ioctl_ram;

always @(*) begin
    main_addr_x = main_ram_addr;
    `ifdef CPS2
    if( main_oram_cs ) begin
        main_addr_x[17:14]  = 4'd0;
        main_addr_x[13] = main_ram_addr[15] ^ obank;
    end
    `endif
end

jtcps1_prom_we #(
    .CPS        ( CPS           ),
    .REGSIZE    ( REGSIZE       ),
    .CPU_OFFSET ( ROM_OFFSET    ),
    .PCM_OFFSET ( PCM_OFFSET    ),
    .SND_OFFSET ( SND_OFFSET    )
) u_prom_we(
    .clk            ( clk           ),
    .downloading    ( downloading   ),
`ifdef MIST
    // This prevents a 1'bz for MSB in simulation
    // Not important for implementation
    .ioctl_addr     ( {1'b0, ioctl_addr[24:0] } ),
`else
    .ioctl_addr     ( ioctl_addr    ),
`endif
    .ioctl_dout     ( ioctl_dout    ),
    .ioctl_wr       ( ioctl_wr      ),
    .ioctl_ram      ( ioctl_ram     ),
    .prog_addr      ( prog_addr     ),
    .prog_data      ( prog_data     ),
    .prog_mask      ( prog_mask     ),
    .prog_ba        ( prog_ba       ),
    .prog_we        ( prog_we       ),
    .prog_rdy       ( prog_rdy      ),
    .cfg_we         ( cfg_we        ),
    .dwnld_busy     ( dwnld_busy    ),
    // QSound & Kabuki keys
    .prom_we        ( prog_qsnd     ),
    .kabuki_we      ( kabuki_we     ),
    // CPS2
    .cps2_key_we    ( cps2_key_we   ),
    .joymode        ( cps2_joymode  )
);
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

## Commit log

2020-01-13 Memory calculations
    [notes.ods]
2020-01-14 PPU2 pinout
    [notes.ods]
2020-01-19 Is SDRAM fast enough?
    [notes.ods]
2020-01-19 Before adding local cache to tilemaps
    [notes.ods]
2020-01-19 GFX ROM access wrong in video sim
    [notes.ods]
2020-01-22 First go at palette
    [notes.ods]
2020-01-22 Moved back to 48MHz. No frame buffer
    [notes.ods]
2020-01-24 Started work on OBJ
    [notes.ods]
2020-01-25 OBJ scan must be divided by lines like pre-CPS
    [notes.ods]
2020-01-26 Sprite engine produces output
    [notes.ods]
2020-01-26 Some sprite visibility
    [notes.ods]
2020-01-30 Video simulation works with ROM file and binary dump of VRAM
    [notes.ods]
2020-01-30 Screen refresh adjusted to real speed
    [notes.ods]
2020-02-03 -CPU seems to get halted around frame 10 after first VRAM read operation. 130.566ms -R/W slot of sdram mux doesn't work correctly
2020-02-05 Ghouls boots up to SCROOL 1 NO GOOD error
    [notes.ods]
2020-02-07 Fixes power up
2020-02-11 New test case
2020-02-15 Strider GFX ok
    [notes.ods]
2020-02-26 Fixed button mapping
2020-03-09 Scroll missing lines almost gone after this optimization. Strider and 1941 1st levels are ok. Small glitch in Glide stage, left hand side, SCR1
2020-03-10 Added DMA for OBJ
2020-03-10 Added DMA for palette copying
2020-03-20 Added SF2 board DMA measurements
2020-03-27 More bits used in mappers. Fixes church top of 2nd stage in Mercs. Also mappers separated in two sets almost fixes timing in MiST
2020-04-05 SF2: all 6 buttons work
2020-04-07 Moved palette DMA to separate module
2020-04-07 Palette DMA now works like original
2020-04-07 Support for SFZ charger version added
2020-04-09 Palette DMA adjusted according to PCB measurements
2020-04-09 OBJ DMA spreaded out across the whole frame
2020-04-09 Removed PAL SDRAM slot
2020-04-09 SCR1 and SCR2 seem ok with new DMA scheme
2020-04-09 Fixed palette DMA issue
2020-04-09 Glitch in Final Fight objects fixed. UN Squadron misses many blocks in SCR1
    [jtcps1_dma.v]
2020-04-10 Ryu stage, right hand side
2020-04-10 Fixed SCR1 in SF2
    [jtcps1_dma.v]
2020-04-10 Row scroll value read during palette DMA. Palette DMA lasts as measured
2020-04-11 Fixed button problem with some SF2 clones
2020-04-12 Fixes a couple of official titles
2020-04-13 Added DIP switches
    [1941.CFG, 1941J.CFG, 1941R1.CFG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]
2020-04-13 DIP switches
    [1941.CFG, 1941J.CFG, 1941R1.CFG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]
2020-04-22 DMA cycles for row scroll value skipped if not enabled
    [jtcps1_dma.v]
2020-04-22 Line DMA intervals adjusted for the fourth possible cases
2020-04-22 DMA problem with Three wonders fixed
    [jtcps1_dma.v]
2020-04-22 Fixes DMA: OBJ table is completely transferred now
    [jtcps1_dma.v]
2020-04-22 Fixes PAL copy error. FPGA test pending
    [jtcps1_dma.v]
2020-04-23 Last trial before re-writting DMA
2020-05-01 Pang3 has broken GFX
    [jtcps1_prom_we.v]
2020-05-09 Correct address implementation without adders
    [jtcps1_dma.v]
2020-05-09 Avoid adding. This is likely the original implementation
    [jtcps1_dma.v]
2020-09-09 Added note about buttons in MiST. Updated JTFRAME -untested-
2020-09-10 Temptative fix for 1941 flip mode
    [jtcps1_dma.v]
2020-09-19 More CPS2 schematics
2020-10-18 Avoids identifying CPS1.5 games as Pang3
    [jtcps1_prom_we.v]
2020-10-19 Punisher seems ok in its first frame of sim
2020-10-21 A better fake for non DSP. But still slammast won't boot fully
    [jtcps15_sound.v]
2020-10-21 Kabuki bank access fixed
    [jtcps15_sound.v]
2020-10-23 fixed false DTACK when accessing Z80 ROM
    [jtcps15_sound.v]
2020-11-14 Added missing QSound LSB during downloading
    [jtcps1_prom_we.v]
2020-11-15 Added sample VCD file
2020-11-15 Sample VCD file extended to 600 frames
2020-11-16 Fixes parallel bus reading
    [jtcps15_sound.v]
2020-11-16 Fixed cpu2dsp bit order
    [jtcps15_sound.v]
2020-11-16 Fixes PBUSIN data selection
    [jtcps15_sound.v]
2020-11-16 Fixes SDRAM connection to DSP16A
    [jtcps15_sound.v]
2020-11-16 Unused pin removed
2020-11-16 Serial interface bypassed. qsnd_addr MSB latched fixed
    [jtcps15_sound.v]
2020-11-22 Sample rate changed to exact 24kHz instead of 24019.21Hz
2020-11-23 Added Punisher track 0 VCD
2020-11-24 83 second simulation of Punisher first stage music
2020-12-08 Fixes QSound gain to prevent distortion
    [jtcps15_sound.v]
2020-12-08 Fixes some timing errors
    [jtcps15_sound.v]
2020-12-17 Added 6 button + pause support to CPS 1.5 version of SF alpha
2020-12-18 Fixed CPS 1.5 games after adding the charger wire
2020-12-19 Support for BRAM. Only works in MiSTer CPS1.5 because of device limitations
2020-12-20 EEPROM dump to ARM works
2020-12-31 Fixed VRAM calculation from base addresses
    [jtcps1_dma.v]
2020-12-31 Garbage still appears on game start. Could it DMA related?
2021-01-02 Fixes Chun Li's theme music
    [jtcps1_dma.v]
2021-01-02 Added full interpolator for CPS1 ADPCM samples
2021-01-13 Sound peak output thru LED
2021-01-13 Added PCM filter at the original 770Hz
2021-01-13 ADPCM filter integration finished.
2021-01-17 JTFRAME. Interpolation filter set to 1
2021-01-17 Changed to LUT for brightness. Fixes dark boxes around graphic elements
    [jtcps1_sdram.v]
2021-01-21 Super Puzzle Fighter 2 boots ok and is stable Start/coin inputs fixed Tilemaps displayed correctly
    [jtcps1_prom_we.v]
2021-01-22 Sprite engine rework starts
    [jtcps1_sdram.v]
2021-01-26 CPS2: Skips interpolator on MiST
    [jtcps15_sound.v]
2021-01-27 Added failing case for background
2021-01-28 Added frame buffer to object table
2021-01-28 Frame buffer for OBJ table works ok in FPGA
2021-01-28 Raster interrupts (wip)
2021-01-28 Raster interrupts done -not simulated-
2021-01-30 DMA timing improved. Only 15% slower now (was 20%)
    [results.ods]
2021-01-31 DMA test error with real PCB reduced to 0.68% (or 1895h vs 18C0h)
2021-01-31 Speed error decreased to -0.08% (or 1895h vs 188f)
    [results.ods]
2021-02-03 NVRAM works for MiSTer (should be broken for MiST)
    [jtcps1_prom_we.v]
2021-02-04 NVRAM works correctly on all systems
    [jtcps1_prom_we.v]
2021-02-19 Megaman2 test case fixed
2021-02-19 New sfa test case
2021-02-19 fixed sfa test case
2021-02-20 Fixed the extra wait logic
    [jtcps15_sound.v]
2021-02-20 Fixes palette DMA extending for several lines
    [jtcps1_dma.v]
2021-02-20 OBJ/PAL DMA is activated with each new frame, not with writes to the base register as before
    [results.ods]
2021-02-21 OBJ/PAL reverted to trigger upon register write. MRA GFX order fixed.
    [jtcps1_dma.v]
2021-02-23 Disabling raster interrupts fixes Nanairo
2021-02-24 Raster interrupt counters do not seem to be programmed correctly
2021-02-24 Fixes missed raster interrupt
2021-02-24 Raster interrupts will not trigger if the counter is 0x106. I think that is correct
2021-02-24 6 button support
2021-02-24 2nd DMA test
2021-02-25 DMA can be disabled for SCROLL 2/3. OBJ DMA doesn't need a write to trigger
    [jtcps1_dma.v]
2021-02-26 Fixes 2P 6 buttons
2021-02-26 16MB support
    [results.ods]
2021-02-27 MRA buttons
2021-02-27 Button count fixed
2021-02-27 Button count fixed for all games
2021-02-27 More button definitions
2021-02-28 Fixes broken GFX (error introduced in 2b3d4ddd. Beware of back merges\!)
    [jtcps1_prom_we.v]
2021-03-01 DDR download for CPS2. CPS1/1.5 download may be broken
    [jtcps1_prom_we.v]
2021-03-02 DDR download. GFX fixes (MRA)
    [jtcps1_prom_we.v]
2021-03-02 Added SCR DMA enable bits
2021-03-03 Fixes 3P inputs for AvsP
    [jtcps1_prom_we.v]
2021-03-04 Moved sound CPU to bank 0, so 8MB-QSound games can be loaded in MiST (Progear, Giga Wing and Dimahoo)
2021-03-05 32MB GFX support, but many large games won't boot
    [jtcps1_prom_we.v, jtcps1_sdram.v]
2021-03-08 Fixes simulation after adding 64MB support to CPS2
    [jtcps1_sdram.v]
2021-03-08 Fixes broken test sound screen on Dark Stalkers
    [jtcps15_sound.v]
2021-03-08 Fixes sound missing in Nanairo, Marvel, Progear...
    [jtcps15_sound.v]
2021-03-09 Fixes SF2 intro. BLNK_DLY changed back to 4 for CPS1
    [jtcps1_dma.v]
2021-03-18 Added Battle Circuit to beta list
2021-03-23 OBJ DMA is always enabled
2021-03-25 Bug fix: progear intro
    [jtcps1_sdram.v]
2021-03-26 Fixes OBJ flickering by using the OBJ base register
    [jtcps1_sdram.v]
2021-03-26 Bugfix: Puzz Loop 2 sprites
    [jtcps1_sdram.v]
2021-04-12 Avoids triggering the raster interrupt at the beginning and at the end of the line
2021-04-20 CPS-A OBJ DMA disabled
2021-04-23 STA fixed for MiST/SiDi
    [jtcps1_sdram.v]
2021-04-26 Interrupt clear signal is generated like in DL-1827
2021-04-26 Messing with the interrupts
2021-05-03 Fixes CPS2 objects with sdram64
    [jtcps1_sdram.v]
2021-05-05 DMA cache (romrq) cleared
2021-05-05 Fixes random horizontal line glitches
    [jtcps1_dma.v]
2021-05-07 Fixes SSF2 Q-Snd RAM
    [jtcps15_sound.v]
2021-05-08 Fixes CSCLUB intro & Gigawing's stage 3
2021-05-08 Fixes Cammy's stage
2021-05-09 Double reads for VRAM and ORAM DMA
2021-05-09 Frame buffer copy moved to later in the frame
2021-05-24 Trying no double for ROM acess to check if that's the problem with CPS1/1.5
    [jtcps1_sdram.v]
2021-06-08 cps15 buttons
2021-10-01 cnt15/16 updated once per 16 frames only
2021-10-20 JTFRAME: macro renamed BUTTONS->JTFRAME_BUTTONS
2021-11-21 Willow DIP switches fixed. Fixes issue #94
2021-12-22 JTFRAME/automatic issue to project flow
2022-03-21 Fixes #111 Forgotten World stars
    [jtcps1_sdram.v]
2022-04-26 Update README.md
    Fix typo
    Remove Carrier Air Wing "Known issue" since it is already fixed
2022-06-26 cps15 fixed - mist
    [jtcps1_prom_we.v, jtcps1_sdram.v]
2022-07-04 Fixes issue #126 by improving the QSound interface robustness
    [jtcps15_sound.v]
2022-10-21 moved sch folder
    [colmix.kicad_sch, cps3.kicad_pcb, cps3.kicad_sch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]
2022-10-26 Moved schematics back to the sch folder
    [colmix.kicad_sch, cps3.kicad_pcb, cps3.kicad_sch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]
2022-10-27 ppu_ research
    [cps3.kicad_sch, gfx.kicad_sch, memories.kicad_sch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]
2022-10-31 modification in progress_ppu
    [cps3.kicad_sch, gfx.kicad_sch, memories_gfx.kicad_sch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]
2022-11-03 ppu in process
    [cps3.kicad_sch, memories.kicad_sch, simm_gfx.kicad_sch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]
2022-12-13 wip cps3
    [cps3.kicad_sch, ppu.kicad_sch, simms_2~1.kicad_sch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]

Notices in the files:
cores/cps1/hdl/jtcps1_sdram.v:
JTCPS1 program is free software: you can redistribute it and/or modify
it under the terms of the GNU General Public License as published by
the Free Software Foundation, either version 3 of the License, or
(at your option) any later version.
